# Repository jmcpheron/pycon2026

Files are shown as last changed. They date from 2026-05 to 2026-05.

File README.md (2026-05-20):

# pycon2026 — a 256:1 reduction-gear card

> A credit-card-sized object with a five-gear compound reduction chain — 256:1 from input to output. Designed in Onshape, deconstructed by Python.








<p align="center">
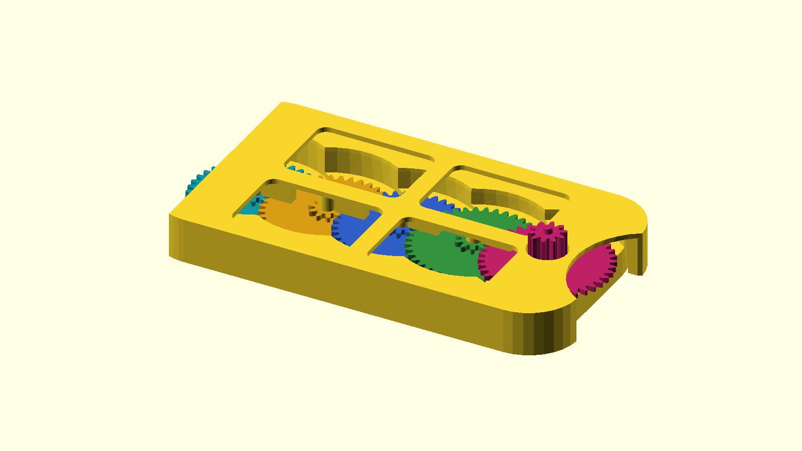
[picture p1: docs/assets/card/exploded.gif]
Animated exploded view of the reduction-gear card: top card half lifts up, five blue 40-tooth spur gears fan out in the middle, bottom card half lowers to reveal five shaft holes spaced 15 mm apart.
  
</p>

<p align="center">
  <sub>Onshape AP242 STEP → <a href="src/cardlab"><code>cardlab explode</code></a> → seven parts → animated GIF. The GIF rebuilds itself in CI whenever the STEP changes.</sub>
</p>

<p align="center">
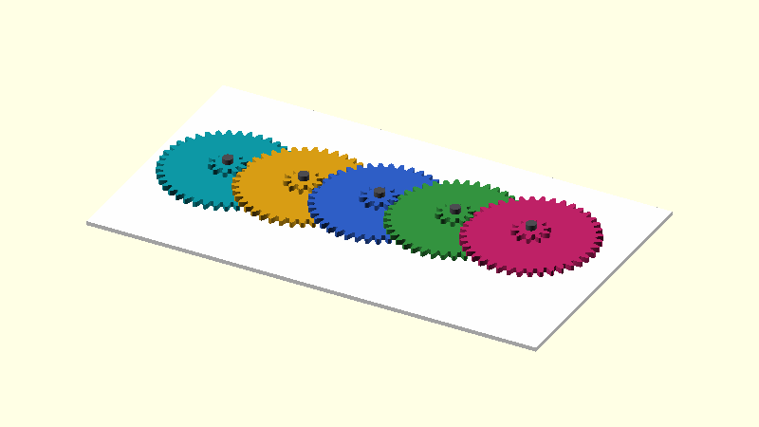
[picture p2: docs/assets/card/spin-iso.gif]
Animated isometric view of the same five-gear chain in motion. The input gear at one end is a brass blur — four full rotations per loop — and each subsequent gear turns at a quarter the rate of its neighbour, alternating direction. The output gear at the far end barely twitches: 256× slower than th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
  
</p>

<p align="center">
  <sub>Same five-gear chain, now <em>running</em>. Three-quarter iso view.</sub>
</p>

<p align="center">
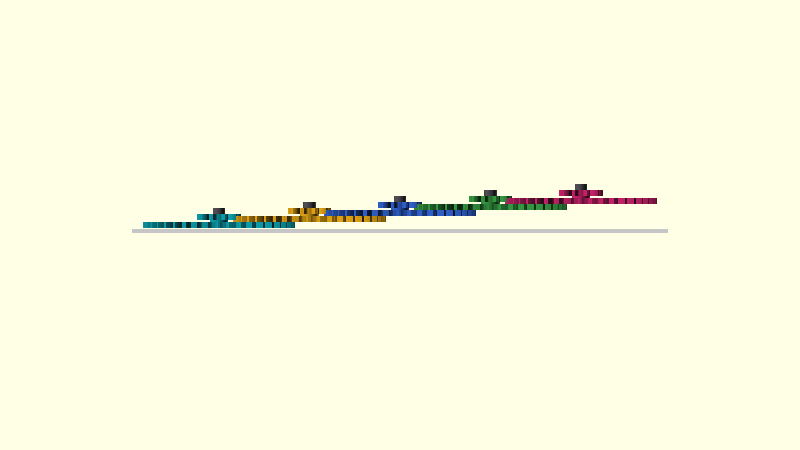
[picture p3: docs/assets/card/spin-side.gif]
Animated edge view of the same five-gear chain, looking along the card's long edge. Each compound gear sits one gear-thickness higher in Z than the previous, so the chain reads as a colored staircase climbing across the card body — and you can see each stage spinning at a quarter the rate of its ne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
  
</p>

<p align="center">
  <sub>Edge view reveals the staircase: each compound gear stacks one gear-thickness higher in Z so the print stays thin. Both GIFs are built parametrically from <a href="src/explainers/card.py"><code>card.py</code></a> with <a href="https://github.com/gumyr/build123d"><code>build123d</code></a> + <a href="https://github.com/gumyr/bd_warehouse"><code>bd_warehouse.gear.SpurGear</code></a>; rendered frame-by-frame by OpenSCAD and stitched by Pillow. Rebuilt by <a href="src/cardlab/spin.py"><code>cardlab spin</code></a>. (Both libraries Apache-2.0 — see <a href="ACKNOWLEDGMENTS.md">ACKNOWLEDGMENTS</a>.)</sub>
</p>

<p align="center">
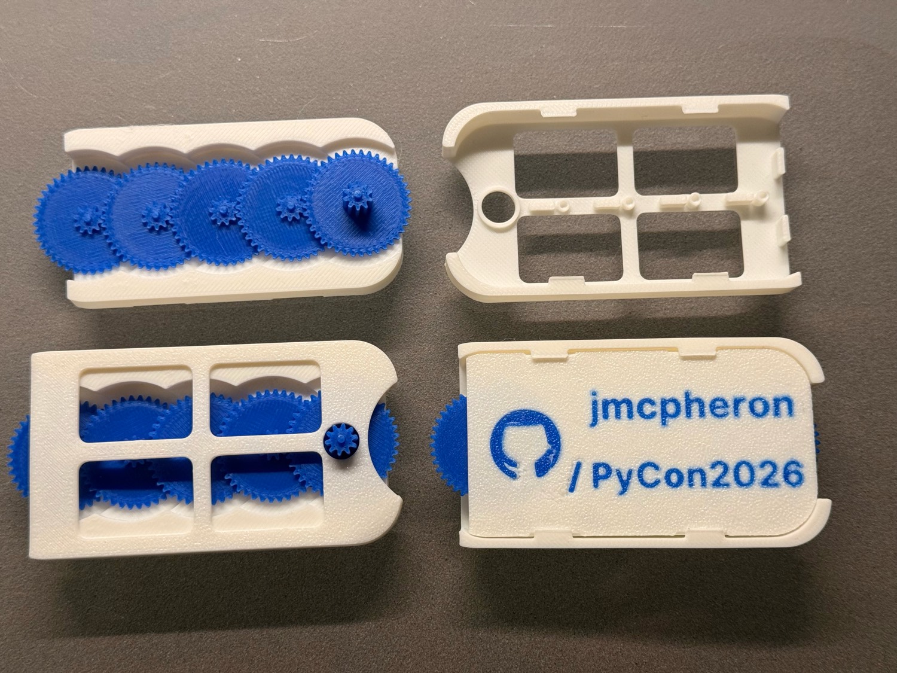
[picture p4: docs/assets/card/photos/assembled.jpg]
Photograph of an actual 3D-printed card, separated into four pieces on a grey desk. Top-left: the bottom card half with the five blue compound gears nested into their pockets, lid removed so the chain is visible. Top-right: the matching white top card half on its own, showing the four interior wind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
  
</p>

<p align="center">
  <sub>And here's the actual print. Two card halves, five blue compound gears, the input pinion poking out the right edge for your thumb — print-in-place from the same <a href="jmcpheron-card.step"><code>jmcpheron-card.step</code></a> the GIFs above are generated from.</sub>
</p>

<p align="center">
  Flat 2D plan view of the five-gear chain. The leftmost gear (INPUT, thumb-spun) rotates clockwise once every two seconds. Each subsequent gear runs at one-quarter the speed of the previous and spins the opposite direction — '4:1' callouts sit between each adjacent pair. By the rightmost gear (OUTPU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
</p>

<p align="center">
  <sub>Each mesh is a 4:1 reduction. Five gears, four meshes, 4<sup>4</sup> = <strong>256:1</strong>. See <a href="docs/explainers/gear-ratios.md">gear-ratios</a> for the math and thumb-travel intuition. Rebuilt by <a href="src/explainers/ratios.py"><code>explainers build ratios</code></a>.</sub>
</p>

<table>
<tr>
<td align="center" valign="top" width="33%">
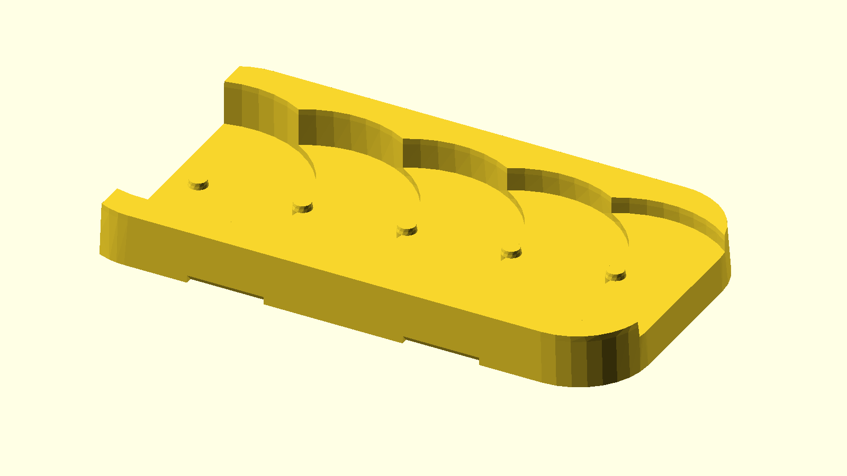
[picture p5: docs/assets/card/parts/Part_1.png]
Render of one of the two card halves — a 78 × 44 mm flat body with five rounded gear pockets, an axle hole, and a curved bottle-opener-style notch on the right.

<br/>
<sub><strong>Card half</strong><br/>78 × 44 mm body, five pockets, axle hole, bottle-opener notch.</sub>
</td>
<td align="center" valign="top" width="33%">
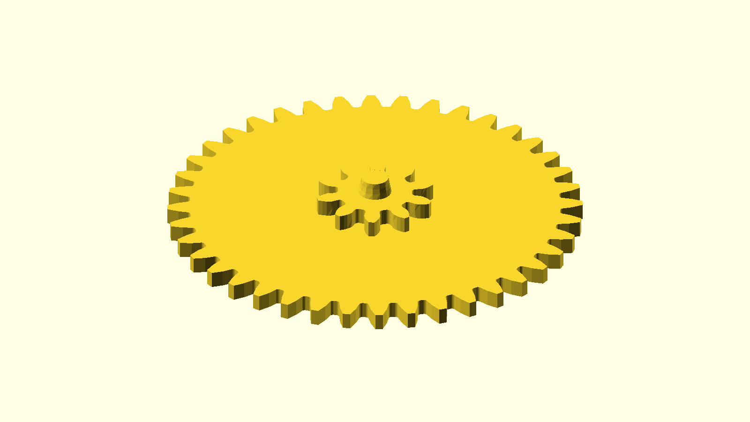
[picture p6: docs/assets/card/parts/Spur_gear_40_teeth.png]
Render of a 40-tooth spur gear with a short 10-tooth pinion hub fused on top — the standard compound gear.

<br/>
<sub><strong>Standard compound gear</strong><br/>40-tooth driven disc + 10-tooth pinion on a short hub.</sub>
</td>
<td align="center" valign="top" width="33%">
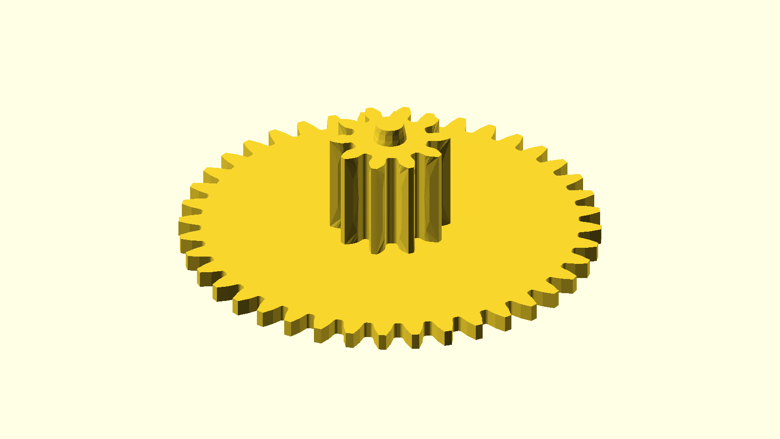
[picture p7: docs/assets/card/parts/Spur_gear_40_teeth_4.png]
Render of a 40-tooth spur gear with a tall 10-tooth pinion hub — the tall-hub variant used in alternating positions of the compound chain.

<br/>
<sub><strong>Tall-hub variant</strong><br/>Same 40 / 10 teeth, taller hub. Interleaved with short-hub gears so the discs don't collide.</sub>
</td>
</tr>
</table>

> *Curious about the pattern behind this repo? See [SHAREABLE-CAD.md](SHAREABLE-CAD.md) for the synthesis — Onshape as source of truth, GitHub as the workshop, MakerWorld + Printables as the storefronts, and the [Adam Savage vault](docs/vault/) as the current worked example.*

## Lightning talk · PyCon US 2026

<p align="center">
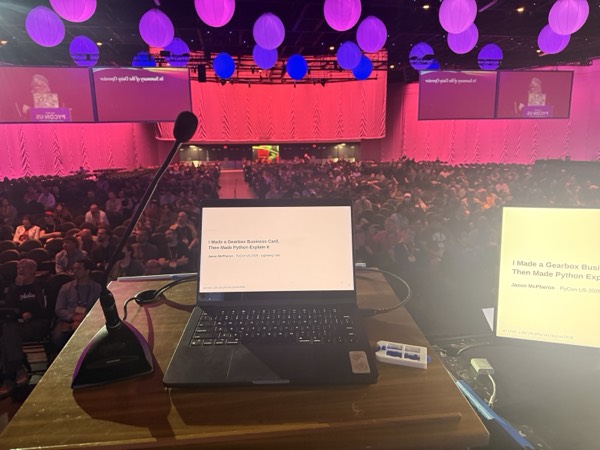
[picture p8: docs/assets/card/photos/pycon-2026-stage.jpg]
View from the lightning-talk podium at PyCon US 2026: a laptop on the podium shows the title slide 'I Made a Gearbox Business Card, Then Made Python Explain It · Jason McPheron · PyCon US 2026 · Lightning Talk'; a gooseneck microphone sits in front of it and a yellow confidence monitor to the right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
  
</p>

<p align="center">
  <sub>View from the lightning-talk stage at PyCon US 2026 in Long Beach, Saturday evening, May 16, 2026.</sub>
</p>

I gave a five-minute lightning talk at PyCon US 2026, *["I Made a Gearbox Business Card, Then Made Python Explain It"](https://us.pycon.org/2026/schedule/presentation/175/)* — the story behind this repo, condensed to slides and a 3D-printed prop audience members could hold. The same lightning-talk session included Simon Willison's *"The last six months in LLMs in five minutes,"* with the latest update to his [pelican-riding-a-bicycle](https://simonwillison.net/tags/pelican-riding-a-bicycle/) LLM benchmark — a real honour to share a stage with.

A recording should land on the [PyCon US YouTube channel](https://www.youtube.com/@PyConUS) in the weeks after the conference; I'll embed the clip here when it's posted.

## How it works

Five compound gears in a chain. Four 4:1 meshes between them, multiplied together: **256:1**. Spin the input gear with your thumb; the output gear moves a quarter-degree.

*(Five gears, four reductions — an idler chain of the same gears would still only reduce 4:1.)*

There are six short explainer pages if you want the longer version:

- [**The card in 3D**](docs/explainers/card-3d.md) — the STEP file and the little script that pulls it apart. Start here.
- [**Gear ratios**](docs/explainers/gear-ratios.md) — compound multiplication, with a thumb-travel intuition: ~20.3 m of finger motion per output rotation.
- [**Decoding the gears from STEP**](docs/explainers/decoding-gears.md) — slice the committed STL, FFT the radial profile, recover the tooth count and module from geometry alone.
- [**Stacking**](docs/explainers/stacking.md) — why a 3-level cycle of hub heights keeps the card thin without the discs colliding.
- [**Terminology**](docs/explainers/terminology.md) — pinion, module, pitch circle, addendum. The 90 seconds of vocabulary the other pages assume.
- [**Printing considerations**](docs/explainers/printing.md) — orientation, chamfers, why each post is its own part.

## A second design — Pounce-a-Pult, a spiral-spring cat toy

To show the same pipeline works on more than just the gear card, here's another of my designs run through it: the [Pounce-a-Pult spiral cat toy](docs/pounce-a-pult/README.md). The parametric source lives in a [public Onshape document](https://cad.onshape.com/documents/01739d2a63dc91eaf28c2c62/w/a7c671d651186a5272cc789f/e/fdb2542c5ccec8040d59912a) (fork it to remix the geometry) with a [printable MakerWorld bundle](https://makerworld.com/en/models/2138778-pounce-a-pult-spiral-cat-toy#profileId-2316710) (slicer profile + photos). The STEP export sits at [`step-demo/pounce-a-pult.step`](step-demo/pounce-a-pult.step); `cardlab inspect` reads its AP242 tree, `cardlab render` produces orthographic hero PNGs, and `cardlab explode` decomposes it into six per-part STL/GLB/PNG renders plus an animated exploded GIF — the same five-function chain the gear card uses, no toy-specific code. Per-page write-up at [**docs/pounce-a-pult/**](docs/pounce-a-pult/README.md).

## How it gets built

The card itself lives in Onshape. The STEP export is committed at the repo root. A little Click CLI called `cardlab` (in [`src/cardlab/`](src/cardlab/)) does five small things to it, leaning on [`build123d`](https://github.com/gumyr/build123d) and [`cascadio`](https://github.com/trimesh/cascadio):

| Command | Does |
|---|---|
| `cardlab inspect` | AP242 schema, assembly tree, bounding box, tessellation stats; merges sidecar `.meta.toml` if present |
| `cardlab build` | Tessellates STEP → STL or **colored GLB** (cascadio path preserves Onshape's per-part colors) |
| `cardlab render` | Orthographic PNG via the OpenSCAD pipeline (iso/top/edge/front/right presets) |
| `cardlab explode` | Pulls an assembly apart into per-part STL/GLB/PNG + an exploded GLB + an animated GIF + a manifest |
| `cardlab assemble` | Glues multiple STEP parts into one assembly from a TOML manifest |
| `cardlab spin` | Renders the chain *running* — parametric gears via `bd_warehouse`, frame-by-frame OpenSCAD, PIL-stitched into `spin-iso.gif` + `spin-side.gif`. Reads only from `src/explainers/card.py`; the STEP file is not used. |

```
jmcpheron-card.step       ──►  cardlab inspect  ──►  docs/assets/card/inspect.txt
                          ──►  cardlab build    ──►  jmcpheron-card.{stl,glb}
                          ──►  cardlab explode  ──►  parts/*.{stl,glb,png}
                                                     exploded.{glb,gif}
                                                     manifest.toml
src/explainers/card.py    ──►  cardlab spin     ──►  spin-iso.gif
                                                     spin-side.gif
```

Everything in [`docs/assets/card/`](docs/assets/card/) is regenerated by [`.github/workflows/build-card.yml`](.github/workflows/build-card.yml) on any push that touches the STEP or the `cardlab` script, then auto-committed back. Push a new Onshape export and the hero GIF above updates itself within a minute.

The six explainer pages above are also Python — small scripts under [`src/explainers/`](src/explainers/) that emit the markdown and SVG diagrams. All the numbers come from one [`card.py`](src/explainers/card.py); change a number there and every page reflects it on the next build.

```
src/explainers/<topic>.py  ──►  uv run explainers build  ──►  docs/explainers/<topic>.md
```

## Try it yourself

```bash
git clone https://github.com/jmcpheron/pycon2026
cd pycon2026
uv sync --extra step
uv run cardlab inspect jmcpheron-card.step
uv run cardlab explode --in jmcpheron-card.step --out /tmp/card/
# → /tmp/card/{exploded.gif, jmcpheron-card.glb, parts/*.{stl,glb,png}, manifest.toml}
```

The `step` extra is opt-in — the OpenCascade wheel is ~180 MB.

Requirements: Python 3.11+, [OpenSCAD](https://openscad.org/) on your `$PATH`, [`uv`](https://docs.astral.sh/uv/). Or just [open the Onshape doc](https://cad.onshape.com/documents/786fefdef357fb6860b54650/w/33fb9222a6752311e4f08c8b/e/da99fedbaeebf1422d4cb0d3) and spin it in your browser — no install required.

## Things I'd love to chat about at PyCon

If you scanned this from the card I handed you, here's what I'm hoping to talk about. Find me on the floor — or open an issue.

- **3D printing**, especially print-in-place mechanisms and the geometry tricks that make them survive a bed-slinger.
- **Python ↔ CAD pipelines.** Onshape STEP exports → `cascadio` → `trimesh` → OpenSCAD → animated GIF, all in CI. I'd like to hear what other people are gluing together.
- **Open-source licensing for physical 3D files.** I went with CC BY-SA 4.0 for the geometry — did I get that right? STEP and STL aren't software; copyright on mechanical designs is fuzzy; CERN OHL exists. Would love to hear from people who've thought harder about this.
- **Defensive disclosure vs. license clauses** as protection against patent trolls and copyright-shaped opportunism. Public Onshape + dated commits is probably doing most of the work; share-alike does the rest. Or does it?
- **Devlog-as-build-journal** as a way to ship hardware in public. I'd like to hear from others doing the same.

## License

**Code** (`src/`, `tests/`, workflows): **MIT** — see [`LICENSE`](LICENSE).

**3D files** ([`jmcpheron-card.step`](jmcpheron-card.step), the generated STL / GLB / PNG / GIF under `docs/assets/card/` and `docs/vault/assets/`, and the [public Onshape document](https://cad.onshape.com/documents/786fefdef357fb6860b54650/w/33fb9222a6752311e4f08c8b/e/da99fedbaeebf1422d4cb0d3)): **CC BY-SA 4.0** — see [`LICENSE-3D-FILES`](LICENSE-3D-FILES).

Print it, fork it, remix the gears. If you publish a derivative — a different layout, a coin-sized version, whatever — it needs to be CC BY-SA 4.0 too, and please credit `pycon2026` by jmcpheron with a link back here.

## Acknowledgments

This project is a thin glue layer on top of a lot of other open-source
work — `build123d`, `bd_warehouse`, `cadquery-ocp` (OCCT), `cascadio`,
`trimesh`, `Pillow`, `drawsvg`, `matplotlib`, `click`, plus OpenSCAD
and `uv` outside Python. See [`ACKNOWLEDGMENTS.md`](ACKNOWLEDGMENTS.md)
for the full list with licenses and links.

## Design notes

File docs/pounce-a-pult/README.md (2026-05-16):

# Pounce-a-Pult — a spiral-spring cat toy, run through the Python pipeline

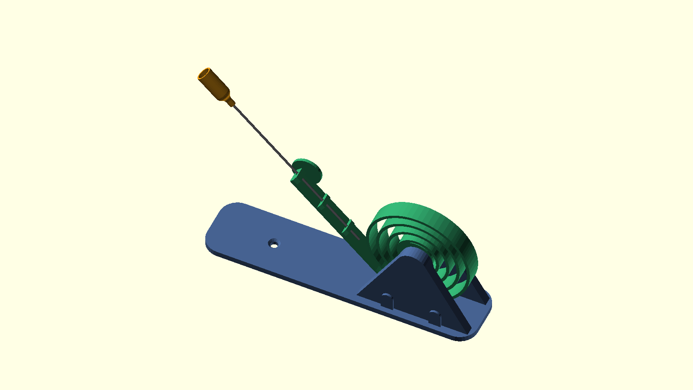
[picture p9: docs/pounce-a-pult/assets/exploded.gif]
Six parts of the pounce-a-pult fanning radially outward from the assembled pose and back, looping; the orange spiral spring and rod-holder cup, the long black base plate, two triangular brackets, and a small reflective bracket plate


> A flat spiral spring that flexes and rebounds when your cat swats it.
> One tap sends the spiral wobbling and twisting before it settles back,
> ready for the next round.

## What it is

The arm is a *flat spiral spring* — laid flat in the print bed, so it
comes off the printer ready to flex out-of-plane. Its free end carries
a small cup sized for a thin straight rod (a straightened coat hanger
works perfectly). Tape a feather to the rod and the assembly becomes a
self-resetting swatting target that moves in a way cats seem to find
endlessly interesting. The base is a long flat plate and two triangular
support brackets that hold the spring vertical.

## Where to get one

The pounce-a-pult is meant to be shared, printed, and remixed. Two
canonical homes for the design live alongside this repo:

- **Print one.** The published bundle on MakerWorld has the slicer
  profile, photos in the wild, and remix notes — the easiest path to a
  working toy:
  [makerworld.com/en/models/2138778-pounce-a-pult-spiral-cat-toy](https://makerworld.com/en/models/2138778-pounce-a-pult-spiral-cat-toy#profileId-2316710).
- **Remix the CAD.** The design lives in a public Onshape document —
  open it in any browser to spin it around, then click "Make a copy"
  into a free Onshape account to change the geometry directly (a
  longer base, taller brackets, a different polygon on the spring
  socket):
  [cad.onshape.com/documents/01739d2a63dc91eaf28c2c62](https://cad.onshape.com/documents/01739d2a63dc91eaf28c2c62/w/a7c671d651186a5272cc789f/e/fdb2542c5ccec8040d59912a).

The files under [`step-demo/`](../../step-demo/) are just the
exported STEP plus everything [`cardlab`](../../src/cardlab/)
derives from it.

## Hero renders

| Iso | Top | Edge |
|---|---|---|
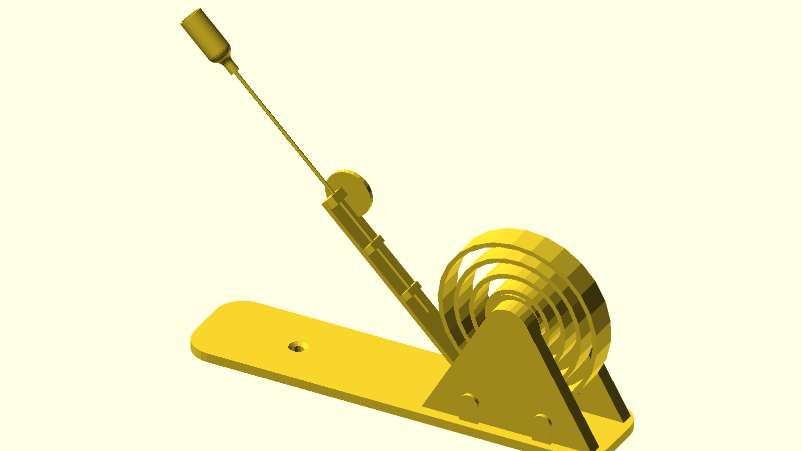
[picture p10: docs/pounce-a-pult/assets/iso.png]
Isometric render: long flat base, twin triangular brackets holding the orange spiral spring upright, small orange cup at the spring's free end
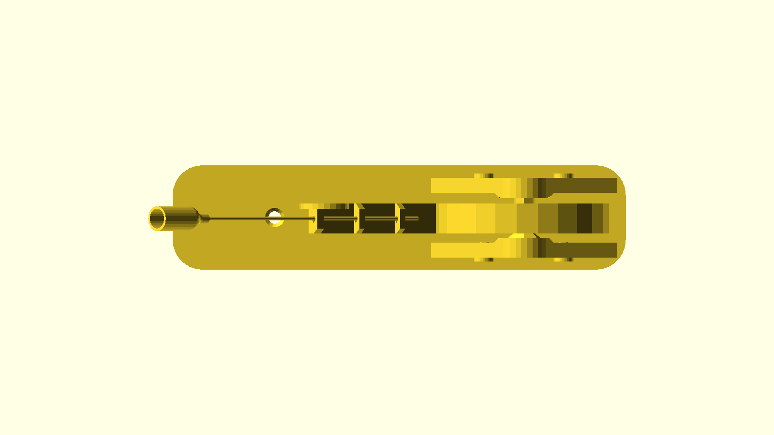
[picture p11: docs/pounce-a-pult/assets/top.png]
Top-down render showing the spring's flat spiral as a near-circular foot-print
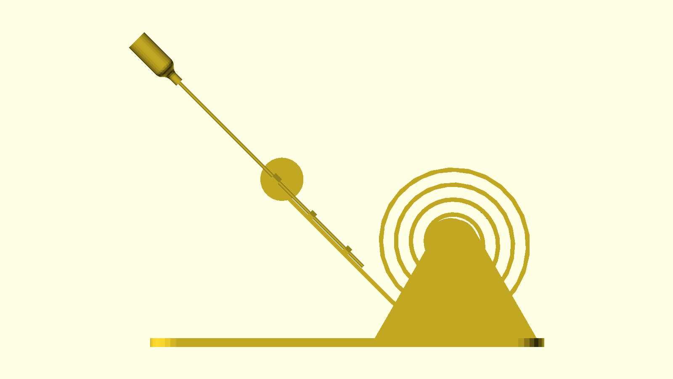
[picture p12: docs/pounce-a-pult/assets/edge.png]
Edge view: the base is a thin strip; the brackets project upward and the spring rises from between them
|  |  |  |

Rendered by `cardlab render` (OpenSCAD-backed orthographic projection)
at the iso / top / edge presets from
[`src/cardlab/render.py`](../../src/cardlab/render.py).

## V2 upgrades

- **Chamfered mounting holes** through the base plate so you can bolt
  this thing to a wall, desk, cat tree, or any nearby surface brave
  enough to host it.
- **Heptagon socket on the spring mount** — 7 sides instead of 2, so
  there are *seven* discrete angle options for clocking the spring
  into the base instead of just two. When the spring starts to sag
  after months of high-impact cat shenanigans, just rotate it to a
  fresh face: more tuning options, better wear spread, and an easy
  way to dial in the perfect amount of bounce.

## Assembly

- Designed for a **~1.6 mm rod**. A straightened coat hanger works
  great. Straightened PLA filament or any similar stiff plastic rod
  will also do the job.
- Add a feather, puffball, or string to the end of the rod with glue,
  a knot, or a snug friction fit. Cat preference, not engineering.
- The brackets slot onto the base plate; the spring's heptagon socket
  registers it to one of seven angles between them. No fasteners
  required for the basic build; M-screws into the chamfered base
  holes if you're wall-mounting.

## Printing

- **PLA or PETG** recommended.
- **No supports** required.
- **Prints flat on the build plate.** The spiral arm is what makes
  this design work — print it lying down so the layers run radially
  along the spring's length, not across it. Cross-grain layers crack
  on the first hard swat.

## Part-by-part breakdown

`cardlab explode` decomposes the STEP into 6 solids, renders each one
in isolation, and writes the colour + centroid + displacement vector
to [`assets/manifest.toml`](assets/manifest.toml).

| Render | Part | Bbox (mm, X × Y × Z) | Notes |
|---|---|---|---|
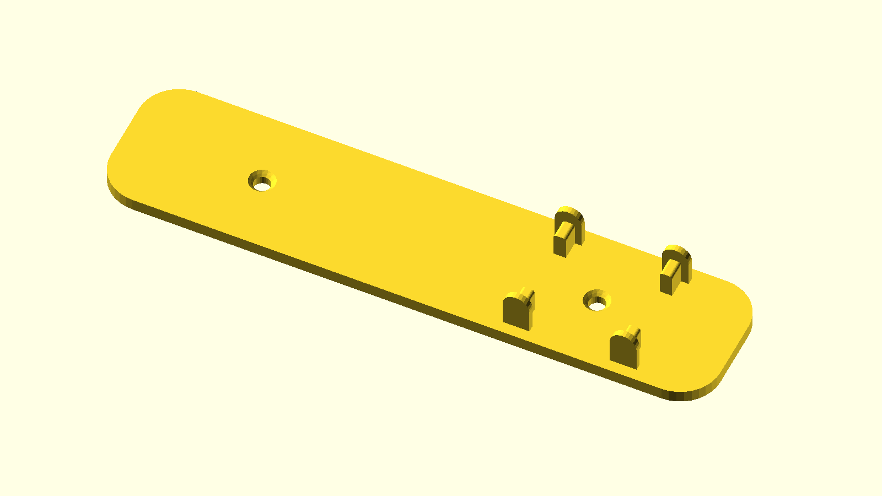
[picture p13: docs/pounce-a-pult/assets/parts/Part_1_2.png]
Long flat base plate
|  | `Part_1_2` | 182 × 42 × 16 | Long flat base plate — the longest part on the long axis. |
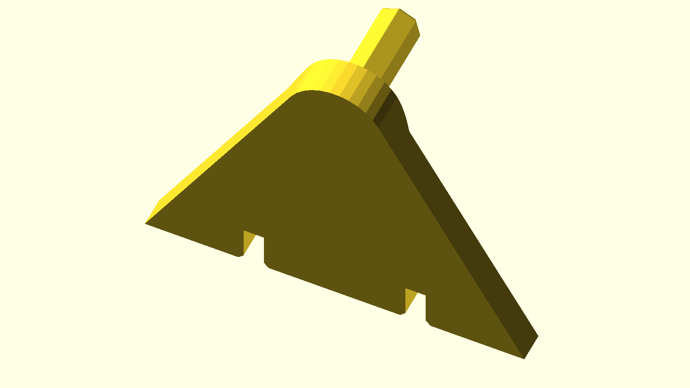
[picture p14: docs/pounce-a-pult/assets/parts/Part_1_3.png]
Triangular support bracket
|  | `Part_1_3` | 75 × 28 × 55 | One of the triangular support brackets. |
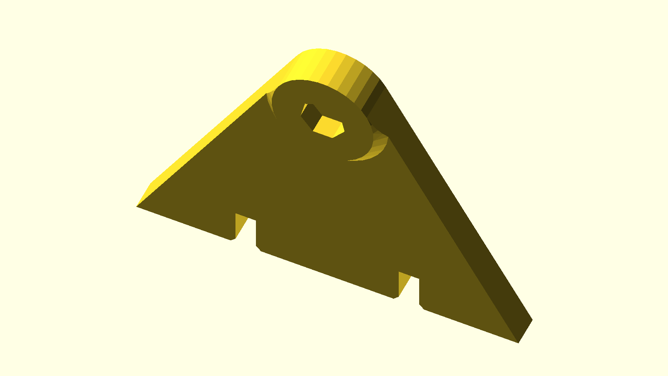
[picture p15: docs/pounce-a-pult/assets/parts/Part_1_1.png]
Triangular support bracket — mirror twin
|  | `Part_1_1` | 75 × 8 × 55 | The mirror-twin support bracket. |
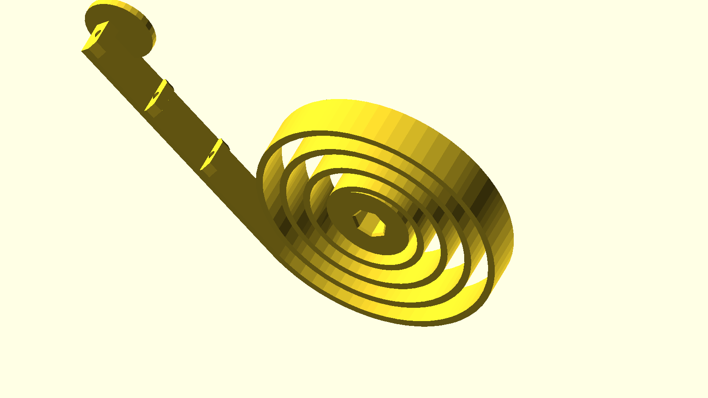
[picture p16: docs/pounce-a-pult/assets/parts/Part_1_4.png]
Flat spiral spring arm
|  | `Part_1_4` | 125 × 12 × 78 | The flat spiral arm — the part that flexes. |
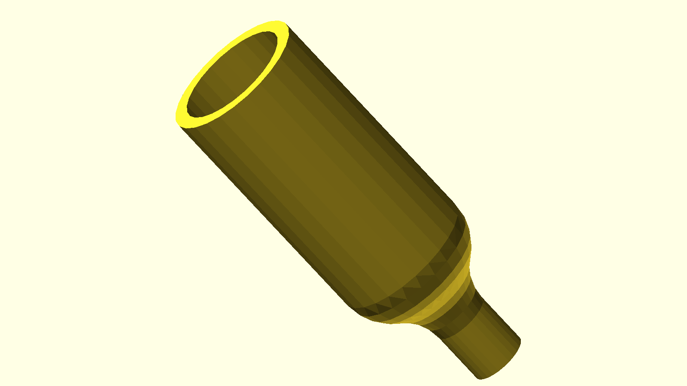
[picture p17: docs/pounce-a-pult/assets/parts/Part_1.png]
Small rod-holder cup
|  | `Part_1` | 25 × 10 × 25 | The rod-holder cup at the free end of the spring. |
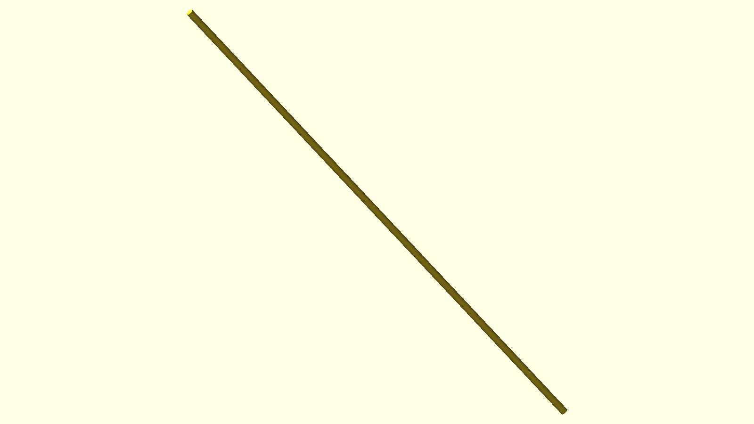
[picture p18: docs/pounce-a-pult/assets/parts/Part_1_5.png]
Square mounting reference
|  | `Part_1_5` | 86 × 1.5 × 86 | The thin square reference plate visible in the Onshape doc. |

Dimensions come straight from the STEP's bounding boxes in
[`assets/manifest.toml`](assets/manifest.toml); the captions are my
read of what each slot is for. The full per-part STL + GLB live next
to the PNGs in [`assets/parts/`](assets/parts/) so you can pull any
single part into Bambu Studio or Onshape.

## Inspect output

The full AP242 tree, bounding box, and tessellation stats are in
[`inspect.txt`](inspect.txt) — produced by `cardlab inspect
step-demo/pounce-a-pult.step`. Useful if you want to confirm units,
schema, or originating CAD system before re-mixing.

## How this page is built

```
step-demo/pounce-a-pult.step  ──►  cardlab inspect  ──►  inspect.txt
                              ──►  cardlab render   ──►  assets/{iso,top,edge}.png
                              ──►  cardlab explode  ──►  assets/exploded.{glb,gif}
                                                         assets/manifest.toml
                                                         assets/parts/*.{stl,glb,png}
```

The exact same `build123d` + `cascadio` + `trimesh` + OpenSCAD + Pillow
pipeline that powers the [gear card's exploded GIF](../assets/card/exploded.gif)
and the [vault mechanism animation](../vault/assets/vault-hero.gif). No
asset-specific code — the only thing that changes between projects is
the input STEP file and the displacement strategy. See
[`ACKNOWLEDGMENTS.md`](../../ACKNOWLEDGMENTS.md) for the full
upstream-library credit list.

CI re-runs the full pipeline on every push that touches
`step-demo/**.step` or `src/cardlab/**`, via
[`.github/workflows/build-step.yml`](../../.github/workflows/build-step.yml),
and auto-commits the regenerated artefacts back to `main`.

## Source · license

The pounce-a-pult is another of my designs, published under
[Creative Commons Attribution 4.0 (CC BY)](https://creativecommons.org/licenses/by/4.0/)
— a more permissive choice than the rest of this repo's 3D files, so
anyone can remix and redistribute the toy without share-alike strings
attached.

Two canonical locations:

- The **parametric CAD source** is a [public Onshape document](https://cad.onshape.com/documents/01739d2a63dc91eaf28c2c62/w/a7c671d651186a5272cc789f/e/fdb2542c5ccec8040d59912a) — this is where the geometry actually *lives* (sketches, features, parameters). Fork it there if you want to change the shape of anything.
- The **printable bundle** is on [MakerWorld](https://makerworld.com/en/models/2138778-pounce-a-pult-spiral-cat-toy#profileId-2316710) — slicer profile, photos, assembly tips, and a place to leave a like.

The `step-demo/pounce-a-pult.step` file is the STEP export from that
Onshape document; every render in this folder
(`docs/pounce-a-pult/assets/*.{png,gif,glb}` and `parts/*`) is a
derivative work of it and inherits **CC BY 4.0** — distinct from the
rest of this repo's [`LICENSE-3D-FILES`](../../LICENSE-3D-FILES) (CC
BY-SA 4.0).

If you remix the toy, please carry the attribution forward.

---

*Generated by `cardlab` from `step-demo/pounce-a-pult.step` — same
Python pipeline as the gear card, run against a different design.*

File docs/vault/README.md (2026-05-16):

# Vault Door Mechanism Study

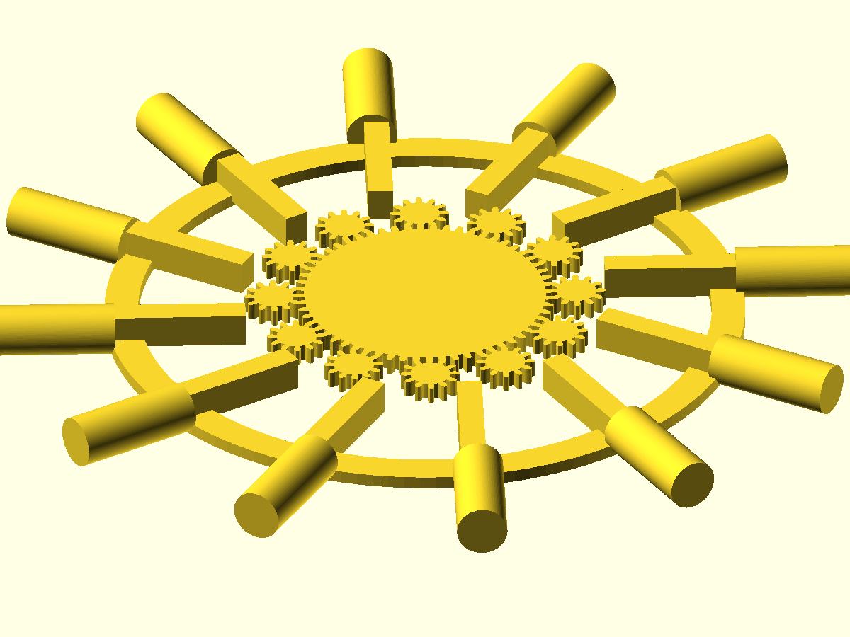
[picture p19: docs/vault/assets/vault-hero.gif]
12-pin vault door mechanism — ring gear, 12 spurs, 12 rack-and-pin assemblies


> *A small Python toy for the geometry of rotary vault-door pin mechanisms.
> Symmetry, gearing, packaging, and what 12 pins share that
> 13 pins can't.*

## I made this because I got curious

Watching Adam Savage's mini vault-door build, I kept staring at one
detail I didn't understand at first: each pin had a section of straight
gear teeth cut into it, and the back of that section — the spine,
opposite the teeth — was machined surprisingly thin. More material
removed than weight savings would justify. When the parts went together
inside the door it clicked. **The pin count was forcing the geometry.**

A single central pinion has to drive all N racks at once, the racks
share the perimeter of that one pinion, and each rack's spine gets
machined down to whatever slice it gets. Bigger N → thinner slice.
Adam wasn't choosing the shape; the pin count was choosing it for him.

That observation kept me up an evening. This repo is what came out — a
Python parametric study of how pin count, symmetry, gearing, and
packaging interact on a circular vault door. Every diagram below is
generated from one parameter file
([`vault.py`](../../src/vault/vault.py)); change a number, every page
re-derives.

## Play with it

**[→ Open the live pin-count explorer](https://jmcpheron.github.io/pycon2026/vault/pin-explorer.html)**

Drag the slider from 3 to 30 pins. The layout snaps. The readout panel
shows the angle step (`360/N`), the divisors of N, whether the count
has exact opposing pairs, and how thin the rack body has to be at that
pin count given the canonical 12 mm pinion.

> 12 reads clean.  13 works but doesn't share.  24 pinches the racks to slivers.

*(Clicking that link from GitHub.com opens the page source. Open it
through GitHub Pages for the live version — the URL above lands you
there directly.)*

## Five short sections

1. [**Symmetry**](symmetry.md) — why 12 and 24 read as obvious and 13 doesn't.
2. [**The 13-pin problem**](thirteen-pin-problem.md) — it works mechanically; what it gives up are the *shortcuts* (shared racks, mirrored fixtures, sub-symmetric actuation). Honest framing of where prime hurts.
3. [**Pin counts**](pin-counts.md) — small-multiples comparison plus the rack-thinning note from watching Adam's video, with the inequality `t ≤ 2π·r_pinion/N − clearance` and a per-N budget table.
4. [**Motion and travel**](motion-and-travel.md) — what a 10° cam rotation actually gets you. `arc = r·θ`, the cam-radius table, and the careful distinction between *arc travel* and *radial pin travel*.
5. [**Onshape workflow**](onshape-workflow.md) — how the Python parameters in [`vault.py`](../../src/vault/vault.py) map to a parametric CAD model.

## For the Tested community

If you got here via the Tested Maker Share: hi. Adam's mini vault-door
build sparked this study; it is a love-letter to the geometry, not a
clone of his mechanism. Fork it, remix it, riff on it — change the pin
count in [`vault.py`](../../src/vault/vault.py), run `uv run vault build`,
and every page above re-derives with your numbers. The interactive
explorer takes the same input live in your browser. Send me what you
find.

## Default door parameters

* Door diameter: **160 mm**, thickness **8 mm**
* Pin count: **12** on a pitch circle of radius **70 mm**
* Pin travel: **8 mm** radial
* Central cam rotation: **10°** (sweeps **12.22 mm** of arc at the pin radius)
* Central pinion radius: **12 mm** (bounds rack-body thickness to **5.98 mm** at N = 12)

Change any of these in [`vault.py`](../../src/vault/vault.py) and the
explainer pages, hero animation, and budget tables all re-derive on the
next `uv run vault build`.

## Print one · remix it

The five canonical mechanism parts ship as standalone STLs alongside
the hero GIF, ready to drop into Bambu Studio, Onshape, or any other
3D tool:

* [`assets/parts/ring-gear.stl`](assets/parts/ring-gear.stl) — central 60-tooth ring gear (module 1). Print **1×**.
* [`assets/parts/spur-gear.stl`](assets/parts/spur-gear.stl) — one 12-tooth satellite spur gear. Print **12×**.
* [`assets/parts/rack.stl`](assets/parts/rack.stl) — one rack, already pre-milled on its spine to the per-pin tangential budget (5.98 mm). Print **12×**.
* [`assets/parts/pin.stl`](assets/parts/pin.stl) — one 12 mm × 30 mm locking pin. Print **12×**.
* [`assets/parts/door-rim.stl`](assets/parts/door-rim.stl) — the 152.4 mm annulus the pins ride through. Print **1×**.

To regenerate them locally (no OpenSCAD required for parts-only
export — build123d is enough):

```
uv run vault export-parts --out-dir /tmp/vault-parts
```

## How it gets built

```
src/vault/<topic>.py     ─►  uv run vault build <topic>      ─►  docs/vault/<topic>.md (+ assets/*.svg)
src/vault/mechanism.py   ─►  uv run vault build-mechanism    ─►  docs/vault/assets/vault-hero.gif
                                                                 + docs/vault/assets/parts/*.stl
src/vault/mechanism.py   ─►  uv run vault export-parts       ─►  docs/vault/assets/parts/*.stl  (parts only, no GIF)
```

The lightweight pages are regenerated by
[`.github/workflows/build-vault.yml`](../../.github/workflows/build-vault.yml)
on every push that touches `src/vault/` and auto-committed back to
`main`. The detailed mechanism GIF — which needs build123d,
`bd_warehouse`, OpenSCAD, and xvfb — runs on its own slower workflow
[`.github/workflows/build-vault-mechanism.yml`](../../.github/workflows/build-vault-mechanism.yml).
Both auto-commit alongside the parallel workflows for the gear card and
the engineering explainers.

The interactive [`pin-explorer.html`](pin-explorer.html) is *not*
regenerated — it's hand-written, self-contained, deployed by
[`.github/workflows/pages.yml`](../../.github/workflows/pages.yml).

## Disclaimer · licenses

This is a fan-made educational mechanism study inspired by public maker
videos and general vault-door mechanisms. It is **not** an official
Tested project, does not reproduce any private plans, and is not
affiliated with Adam Savage's Tested.com.

Code: MIT.
Diagrams + 3D files under this directory: CC BY-SA 4.0.
See [`LICENSE`](../../LICENSE) and [`LICENSE-3D-FILES`](../../LICENSE-3D-FILES).

## Credits — the libraries that draw the pictures

The static SVG diagrams (symmetry, pin-counts, motion, the 13-pin
comparison) are drawn with
[`drawsvg`](https://github.com/cduck/drawsvg) (MIT).
The mechanism GIF above is built from
[`build123d`](https://github.com/gumyr/build123d) and
[`bd_warehouse`](https://github.com/gumyr/bd_warehouse) parts (both
Apache-2.0) — `bd_warehouse.gear.SpurGear` is what gives us the
involute-tooth ring and spur gears — rendered frame-by-frame through
[OpenSCAD](https://openscad.org/) (GPL-2.0-or-later) and stitched into
a GIF with [Pillow](https://github.com/python-pillow/Pillow) (MIT-CMU).
The full list of third-party tools the repo leans on lives in
[`ACKNOWLEDGMENTS.md`](../../ACKNOWLEDGMENTS.md).

---

*Generated by `src/vault/index.py`. Source-of-truth parameters live in
[`src/vault/vault.py`](../../src/vault/vault.py).*

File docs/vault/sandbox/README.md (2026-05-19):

# Vault door — local OpenSCAD sandbox

This directory is the **local iteration playground** for the vault door's
structural body. It is intentionally a "side quest" from the main repo
toolchain:

* No build123d, no `bd_warehouse`, no Python in the loop — just one
  hand-written `.scad` file with an OpenSCAD Customizer block.
* Not watched by `build-vault.yml` or `build-vault-mechanism.yml`. The
  only CI that touches it is `pages.yml`, which publishes the file to
  GitHub Pages as a static asset.
* No auto-commits race your edits.

The canonical Python parameters in [`src/vault/vault.py`](../../../src/vault/vault.py)
remain the source of truth for the CI-rendered GIF and the engineering
explainer pages. `door.scad` is a *parallel* representation — same
numbers, different language — meant for fast geometric play.

## How to use

Open the file in the OpenSCAD GUI:

```
openscad docs/vault/sandbox/door.scad
```

Then **View → Customizer**. Drag the sliders. Hit **F5** for fast
preview, **F6** for the full CSG render.

To export a still PNG for sharing:

```
openscad -o /tmp/door.png \
    --imgsize 1600,900 \
    --camera 0,0,15,58,0,28,500 \
    --projection ortho \
    --colorscheme Cornfield \
    docs/vault/sandbox/door.scad
```

To override a parameter from the command line (one-off, without editing
the file):

```
openscad -o /tmp/door_thin.png -D 'door_thickness_mm=24' docs/vault/sandbox/door.scad
```

## What is and isn't in the model

In: door body, tapered edge, internal cavity, 12 radial pin bores, the
spur-axle bolt circle on the 72 mm BCD, the ring-gear boss recess, an
optional 120° cutaway wedge.

Not in: the ring gear, the 12 spur gears, the racks, the locking pins
themselves, the combination lock cage, the hinge, the frame plate. The
gears already exist as STLs in
[`docs/vault/assets/parts/`](../assets/parts/) — those are produced from
`src/vault/mechanism.py` via build123d + bd_warehouse, because involute
gear teeth are painful in raw OpenSCAD primitives. If you want them
visible alongside the door, `import("../assets/parts/ring-gear.stl")`
from a sibling `.scad` file is the cleanest path.

## When to graduate a number out of the sandbox

If a dimension you've been dialling in here turns out to be the "right"
one, update [`docs/vault/specs.md`](../specs.md) (with a source tag) and
then `src/vault/vault.py`. The sandbox is for play; the Python module is
where decisions land.

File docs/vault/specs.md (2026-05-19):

# Vault build — specifications

Single source of truth for every dimension, count, and material call-out.
Each entry tagged with the source it came from (e.g. `[video-01]`), so when
Adam revises a number in a later video the trail stays clear.

Sources legend:
- `[video-01]` — Adam machining the ring gear from a stainless cylinder
  (https://www.youtube.com/watch?v=SiL8IzJSnyU)
- `[Part 2]` — pins, racks, acrylic hub body — `part-2.md`
- `[Part 3]` — vault-door puck, frame plate, hinge — `part-3.md`
- `[Part 4]` — rack concentricity rework, revised pin diameter — `part-4.md`
- `[Part 5]` — miniature combination lock cage — `part-5.md`

---

## Global gear math

| Parameter | Value | Source |
| --- | --- | --- |
| Gear module | 0.5 mm | [video-01] |
| Scale (relative to a real vault door) | 1/12 | [video-01] |

The module is the parameter that has to match across every gear that meshes,
so it is the single most important number in the file.

## Real-world reference (for context, not for modeling)

Real vault doors: 24 spur gears (24 teeth each) around a 288-tooth ring gear.
Adam's miniature halves this — see below. `[video-01]`

## Ring gear

| Parameter | Value | Source |
| --- | --- | --- |
| Teeth | 120 | [video-01] |
| Outer diameter | 2.401 in (≈ 2.4 in) | [video-01] |
| Depth of gear cut (OD to root of tooth) | 0.044 in | [video-01] |
| Material (Adam's build, FYI only) | 416 stainless | [video-01] |

## Spur gears

| Parameter | Value | Source |
| --- | --- | --- |
| Count | 12 | [video-01] |
| Teeth (each) | 24 | [video-01] |
| Bolt-circle hole spacing | 30° (12 holes evenly around) | [video-01] |

Adam's mill dividing plate has 24 holes (15° spacing), but he only fills every
other one for the 12-pin door.

## Locking pins

| Parameter | Value | Source |
| --- | --- | --- |
| Count | 12 (one per spur gear) | [video-01] |
| Diameter | 12 mm | [video-01] |
| Drive mechanism | Straight rack on bottom face, driven by spur gear | [video-01] |

## Door body (the acrylic / cast-iron puck)

| Parameter | Value | Source |
| --- | --- | --- |
| Outer diameter (at the front face) | 6 in (152.4 mm) | [Part 2] |
| Stock thickness (Adam's as-built) | 1.25 in (31.75 mm) | [Part 2] |
| Sandbox thickness (see "Three-stage edge profile" below) | 48 mm | derived |
| Material (Part 2) | Cast acrylic (for the visualisation hub) | [Part 2] |
| Material (Part 3) | Cast iron (the real heavy puck) | [Part 3] |
| Front-face solid thickness (before cavity) | 0.5 in (12.7 mm) | [Part 3] |
| Internal cavity depth (Adam's stock) | 0.75 in (19.05 mm) | [Part 3] |
| Door-thinning required for swing clearance | 0.75 in (19.05 mm) of push-back | [Part 3] |
| Ring-gear boss inner diameter ("slip cut") | 2.003 in (50.876 mm) | [Part 2] |

### Three-stage edge profile

The Part 3 video shows the door edge is NOT a single conical taper —
it's three roughly-even axial stages stacked back-to-front, each
~1/3 of the total thickness:

| Stage | z range | Wall character | Role |
| --- | --- | --- | --- |
| **Back** | [0, t/3] | Near-cylindrical (≈ 0°) | Houses the 12 radial pin bores. The wall has to be straight so the bores are perpendicular to a parallel surface. |
| **Middle** | [t/3, 2t/3] | Gradual taper (≈ 6°) | Intermediate transition. |
| **Front** | [2t/3, t] | Bigger taper (≈ 12°) | Lands on the display face. This is the angle that does most of the "thunk into the frame seat" work. |

Where `t` is the total door thickness.

**Why the sandbox uses 48 mm instead of Adam's 31.75 mm**: at the
canonical 12 mm pin diameter, the back stage needs to contain the pin
bore cleanly — diameter 12 + 0.2 mm clearance + ~2 mm of wall above and
below = ~16 mm of z-height per stage. Three even stages of 16 mm = 48
mm total. Adam's 31.75 mm stock gives each stage only ~10.6 mm, which
forces the pin to straddle the boundary between the back stage and the
middle stage rather than living entirely inside the back stage. The
sandbox model favours a clean back-stage placement; the as-built
column is preserved as a separate row above.

## Pin layout & spur-axle bolt circle

| Parameter | Value | Source |
| --- | --- | --- |
| Spur-axle bolt-circle diameter (BCD) | 72 mm | [Part 2] |
| Spur-axle hole count | 12 (every other hole of the 24-hole dividing-plate pattern) | [video-01] |
| Angular spacing | 30° | 360 / 12 |
| Pin bores | 12 radial, through the rim, into the cavity | [Part 2] |
| Shoulder-bolt smooth-shoulder slip-fit clearance to spur-gear bore | 0.1 mm | [Part 2] |

## Pin & rack mechanism (revisions and details)

| Parameter | Value | Source |
| --- | --- | --- |
| Pin diameter (Part 2 drawing) | 12 mm ("M12 × 30") | [Part 2] |
| Pin diameter (Part 4 revision, measured from physical part) | 10 mm | [Part 4] |
| Pin length | 30 mm | [Part 2] |
| Pin base thread | M6 (rack screws into the pin base) | [Part 2] |
| Rack stock | 8 × 8 mm square | [Part 2] |
| Rack module | Mod 0.5 (matches ring + spur) | [Part 2] |
| Rack threaded stud | 6 mm Ø, M6 (turned from the 8 mm square) | [Part 2] |
| Rack back-face relief | Curved (ball-end-mill) to clear ring gear | [Part 2] |
| Rack quantity made | 14 (12 needed; "always make more than you need") | [Part 4] |
| Rack tooth-zero-point alignment tolerance | within 0.1 mm of all 12 racks | [Part 2] |
| Concentricity error from hand-cut thread (the trap to avoid in CAD) | 0.0125 in (≈ 0.32 mm) | [Part 4] |

## Frame plate & door swing (Part 3, FYI for the full build)

| Parameter | Value | Source |
| --- | --- | --- |
| Frame plate material | 1/2 in 6061 aluminium | [Part 3] |
| Frame plate footprint | ≈ 10–12 in square | [Part 3] |
| Frame opening | 6 in bore | [Part 3] |
| Door-to-frame radial clearance | 0.020 in (0.508 mm) | [Part 3] |
| Hinge thrust bearings | 3/8 in OD on a 1/8 in centre pin | [Part 3] |
| Hinge fasteners | 28 × M2 screws (M6 is Adam's plan B) | [Part 3] |

## Combination lock cage (Part 5, future scope)

| Parameter | Value | Source |
| --- | --- | --- |
| Cage envelope | 0.75 in long × 0.5 in wide | [Part 5] |
| Cage wall material | 0.025 in (≈ 0.64 mm) brass sheet | [Part 5] |
| Combination wheels | 3 wheels | [Part 5] |
| Wheel diameter | 0.450 in | [Part 5] |
| Spindle | 1/8 in brass rod through the door | [Part 5] |
| Dial tick divisions | 36 (one per 10°) | [Part 5] |

## Derived values

| Parameter | Value | Notes |
| --- | --- | --- |
| Drive ratio (ring : spur) | 5 : 1 | 120 / 24. Onshape's Gear Relation tool will compute this automatically from tooth counts. |
| Spur centres relative to ring centre | 36 mm | BCD / 2 |
| Pins per 30° wedge | 1 | 12 pins, 360 / 12 |

## Discrepancies (numbers that disagree between sources)

These are the open decisions. When you pick a winner, update both
`src/vault/vault.py` and the row above to match.

| Param | `src/vault/vault.py` | Video transcript | Decision |
| --- | --- | --- | --- |
| Locking pin diameter | `MECH_LOCKING_PIN_DIA_MM = 12.0` | 12 mm `[Part 2 drawing]` → revised 10 mm `[Part 4 physical part]` | (TBD) |

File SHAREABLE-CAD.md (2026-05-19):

# Shareable CAD — the pattern this repo is built on

> *A pipeline for hand-printable, parametric, code-trackable, community-shareable 3D objects. Onshape is where the geometry lives. GitHub is the workshop. MakerWorld and Printables are the storefronts. Python sits in the middle and pulls everything apart so anyone can put it back together.*

This repo started as one small physical artifact — a credit-card-sized
five-gear reduction chain handed out at PyCon 2026 — and a Python
toolkit to deconstruct its STEP file into renders, exploded GIFs, and
generated explainer pages. Then we ran the same toolkit on a
[spiral-spring cat toy](docs/pounce-a-pult/README.md). Then we started
[an Adam Savage mini-vault-door study](docs/vault/). Three different
objects, same scaffolding, same kind of writeup.

At three projects the *pattern* is more interesting than any one of
them. This document is the pattern.

## TL;DR

```
   Onshape doc          ← source of truth (parametric CAD in the cloud)
       │ STEP export, committed to repo root
       ▼
   GitHub repo          ← Python tooling, parameters, history, issues
       │ auto-built artifacts (STL / GLB / GIF / SVG / explainer pages)
       ▼
   MakerWorld + Printables   ← consumer-facing sharing endpoints
                              (3MF bundle + slicer profile + photos)
```

You design in Onshape because it's the most painless cloud CAD tool
that produces clean STEP. You commit the STEP into git so the geometry
has a versioned home. You mirror the parameters into a Python file so
parameter changes show up as real diffs. You let CI rebuild every
derivative artifact on push. You ship a 3MF bundle to MakerWorld
because that's where consumer 3D printers actually look — and you
mirror to Printables (and link back to GitHub) because that's the open
door home. The Python tooling makes the whole loop reproducible.

The three projects so far:

| Project | Status | Lives on | Doc |
|---|---|---|---|
| Gear card | shipped | GitHub | [`README.md`](README.md) |
| Pounce-a-Pult | shipped | MakerWorld + GitHub | [`docs/pounce-a-pult/`](docs/pounce-a-pult/README.md) |
| Adam Savage vault | in progress | GitHub (sandbox printable now) | [`docs/vault/`](docs/vault/README.md) |

The vault is the spotlight worked example in this document — it's the
project where every pipeline stage is visible because we're walking
through it in real time.

## What makes something "shareable CAD" in this sense

The word "shareable" does a lot of work here. People share STLs on
Thingiverse every day; that's not what this is about. What we mean:

1. **Parametric.** The object isn't a frozen mesh — it's a small
   number of *parameters* that produce a mesh. Change a tooth count, a
   diameter, a thickness, and the whole thing re-derives.
2. **Single source of truth.** Every dimension lives in exactly one
   place. The Onshape document has it. A Python file mirrors it. Tests
   yell if a third file hardcodes one of those numbers.
3. **Code-trackable.** A parameter change is a one-line git diff with
   a commit message and a date. Not a screenshot of "revision 12 of
   the Onshape document, dated last spring."
4. **Derivable.** Every artifact a reader might want — exploded GIF,
   per-part STL, hero PNG, explainer page — is *built* by code that
   reads only from the source of truth. No artisanal copies.
5. **Printable.** The end-state of this whole loop is a 3D print
   someone else can produce in their own kitchen with a 3D printer
   they already own, without having to know any of the above.

The PyCon-talk kernel of all this is the **Python tooling that does
the deriving** — `cardlab`, `explainers`, `vault`. Those packages are
the *lab* where we work out what "processing 3D files at consumer
community level" actually means.

## The three projects so far

### Gear card — the kernel

Animated exploded view of the reduction-gear card

A 78 × 44 mm card with five compound gears giving 256:1 reduction
input-to-output. The card itself lives in
[a public Onshape document](https://cad.onshape.com/documents/786fefdef357fb6860b54650/w/33fb9222a6752311e4f08c8b/e/da99fedbaeebf1422d4cb0d3);
its STEP export sits at the repo root as [`jmcpheron-card.step`](jmcpheron-card.step);
the Python parameter mirror lives at
[`src/explainers/card.py`](src/explainers/card.py); the
[`cardlab`](src/cardlab/) CLI deconstructs the STEP into per-part
renders + an exploded GIF + a manifest; the [`explainers`](src/explainers/)
CLI generates six writeup pages, every number on every page sourced
from `card.py`. This is the project where the pipeline was born.

Lives on GitHub. CC BY-SA 4.0 on the geometry — change-and-share-back.

### Pounce-a-Pult — the MakerWorld proof point

Six parts of the pounce-a-pult fanning radially outward and back

A spiral-spring cat toy. Second project. The
[Onshape document](https://cad.onshape.com/documents/01739d2a63dc91eaf28c2c62/w/a7c671d651186a5272cc789f/e/fdb2542c5ccec8040d59912a)
is its real home; the
[MakerWorld bundle](https://makerworld.com/en/models/2138778-pounce-a-pult-spiral-cat-toy)
is where actual humans go to print it. The STEP file
[`step-demo/pounce-a-pult.step`](step-demo/pounce-a-pult.step)
is the bridge: `cardlab inspect / render / explode` runs the *same
five-function pipeline* used on the gear card — no toy-specific code
— and the auto-committed artifacts under
[`docs/pounce-a-pult/assets/`](docs/pounce-a-pult/) feed the page on
github.io.

Lives on **MakerWorld + GitHub**. CC BY 4.0 — intentionally more
permissive than the gear card, no share-alike strings, because cat
toys travel better that way.

### Adam Savage mini vault door — the walkthrough in progress

12-pin vault door mechanism — ring gear, 12 spurs, 12 rack-and-pin assemblies

A fan study of the 1/12-scale vault-door mechanism Adam Savage
machined on
[Tested.com](https://www.tested.com/). The third project, and the
slowest — partly because it's the most ambitious (12 pins on a 72 mm
BCD, three nested taper stages, a satellite gear train), partly
because we're documenting *while* we model. Everything is here:

- The video research, transcribed and distilled into [`docs/vault/specs.md`](docs/vault/specs.md).
- An [Onshape workflow doc](docs/vault/onshape-workflow.md) and [Onshape notes](docs/vault/onshape-notes.md) covering the FeatureScripts, the variable sheet, the gear math.
- A parametric **OpenSCAD sandbox** at [`docs/vault/sandbox/`](docs/vault/sandbox/) with a three-stage tapered door body, a full assembly with imported gear STLs, a self-contained ring-gear `.scad`, and a rack `.scad` that meshes with the satellite spurs. STLs ready to print today.
- A side-by-side **[Onshape ↔ OpenSCAD comparison doc](docs/vault/onshape-vs-openscad.md)** covering the tradeoff between cloud-CAD ergonomics and code-trackable text files.
- A build123d render pipeline at [`src/vault/mechanism.py`](src/vault/mechanism.py) producing the hero GIF above.
- Five canonical part STLs exported by [`vault export-parts`](src/vault/cli.py) under [`docs/vault/assets/parts/`](docs/vault/assets/parts/).

What's left to ship: the Onshape model itself (in progress), a 3MF
bundle for MakerWorld, a Printables mirror, and a few open dimension
questions (the [12 mm vs 10 mm pin diameter](docs/vault/specs.md)
revision Adam shows in Part 4; the three-stage taper angles).

The vault is the project where every pipeline stage is in flight at
the same time — which is why it's the example I keep coming back to
below.

## The pipeline stages

### Onshape as the source of truth

Onshape isn't open source. It's a cloud CAD app owned by PTC. We
recommend it anyway, because for the audience this pipeline is aimed at
— people who want to design a parametric 3D object and put it in
front of other humans without negotiating five command-line tools — it
is the most painless entry point that produces clean STEP. The
specifics that earn it the spot:

- **Public-readable URLs.** You can paste an Onshape link in your
  README and anyone with a browser can spin your design around. The
  gear card and Pounce-a-Pult both do this.
- **FeatureScript standard library.** Standard features (spur gears,
  threads, weld beads) are a click away. We use the
  ["Spur Gear" FeatureScript](docs/vault/onshape-notes.md) directly for
  every gear in the vault. No hand-drawn involutes.
- **Mate and Gear Relation UX.** Onshape's Assembly tab is genuinely
  good at making 12 satellite spurs rotate at the right ratio against
  a central ring gear. Code-driven CAD tools cannot beat that for
  iteration speed.
- **STEP export.** AP242 STEP is the lingua franca that lets every
  downstream tool (build123d, cascadio, OpenSCAD via STL, FreeCAD,
  CAM packages) read what Onshape made.

The cost is real, and worth naming. Onshape documents aren't
git-trackable. If PTC raises prices or shuts the free tier, your
geometry doesn't *vanish* — STEP exports survive — but the editing
environment does. We acknowledge the lock-in honestly and mitigate it
two ways: (a) commit STEP exports into git so the geometry has a
versioned home outside Onshape, and (b) keep the *numbers* in a Python
file so changing a parameter is independent of the editing UI. More on
that below.

### The Python parameter mirror

Every project in this repo has a single Python module that holds every
dimension. Other code reads *only* from that module:

- Gear card: [`src/explainers/card.py`](src/explainers/card.py) — `BIG_TEETH`, `PINION_TEETH`, `MODULE_MM`, the lot.
- Vault: [`src/vault/vault.py`](src/vault/vault.py) — door diameter, pin count, BCD, ring-gear bore, pressure angle, every cam parameter.

You change a number there, you run `uv run explainers build` or
`uv run vault build`, and every page, diagram, and (for the vault)
every parametric `.scad` file re-derives. There's a test
([`test_no_drift_between_sections`](tests/test_explainers.py)) that
checks every explainer markdown still contains the textual value of
the canonical parameters — so a literal-number sneaking into the
prose fails CI.

The Python mirror is what lets a parameter change be a 1-line git diff
with a commit message and a date. The Onshape variables are still the
*editing surface*; the Python module is the *diffable record*. They
have to stay in sync, and right now that sync is by hand (you change
a number in Onshape, you also change it in `card.py` / `vault.py`).
The hand-sync is the friction point most worth automating eventually.

### The Python kernel

The three packages [`cardlab`](src/cardlab/), [`explainers`](src/explainers/),
and [`vault`](src/vault/) are the *lab* the PyCon talk is built
around — small CLIs that demonstrate "processing 3D files at
consumer-community level."

`cardlab` is the workhorse, because STEP processing is the part most
people don't already have a recipe for:

| Command | Does |
|---|---|
| `cardlab inspect` | AP242 schema, assembly tree, bounding box, tessellation stats |
| `cardlab build` | Tessellates STEP → STL or coloured GLB |
| `cardlab render` | Orthographic PNG via OpenSCAD (iso / top / edge / front / right) |
| `cardlab explode` | Pulls an assembly apart into per-part STL/GLB/PNG + exploded GLB + animated GIF + manifest |
| `cardlab assemble` | Glues multiple STEP parts into one assembly |
| `cardlab spin` | Renders a gear chain *running* — parametric gears, frame-by-frame OpenSCAD, PIL-stitched into a GIF |

`explainers` and `vault` generate the per-page writeups: SVG diagrams
via [`drawsvg`](https://github.com/cduck/drawsvg), charts via
matplotlib, markdown that reads from the parameter file.

The packages split into a **light toolchain** (drawsvg + matplotlib,
fast install, builds the explainer pages) and a **heavy toolchain**
(build123d + cadquery-ocp + OpenSCAD + xvfb, ~180 MB OpenCascade
wheel, builds the STEP-derived renders and the GIFs). Anyone who just
wants to fix a typo in an explainer page doesn't need OpenCascade.
The split is in
[`pyproject.toml`'s optional dependencies](pyproject.toml):
`--extra explainers` is the light one, `--extra step` is the heavy
one. CI uses both.

### GitHub as the workshop

This repo's working pattern, generalised:

1. **The README tells the story.** Hero GIF, what it is, how it
   works, how to print one. Not "documentation" — narrative. The
   [gear-card README](README.md) is the canonical example.
2. **CI auto-builds derived artifacts on push.** Three workflows
   ([`build-card.yml`](.github/workflows/build-card.yml),
   [`build-explainers.yml`](.github/workflows/build-explainers.yml),
   [`build-vault.yml`](.github/workflows/build-vault.yml)) each watch
   their own input paths and write to disjoint output paths. They each
   `git pull --rebase` and retry on push rejection, so they can race
   each other (and human pushes) without conflict.
3. **Issues are for design discussion.** "Should the pin be 10 mm or
   12 mm?" is an issue, not a Slack thread.
4. **PRs are for parameter changes.** Bump a number, regenerate the
   diagrams, look at the diff. The diagrams are part of the diff.
5. **GitHub Pages deploys `docs/`.** Anyone who doesn't have a clone
   can still read the markdown.

The auto-commit-on-push pattern is the one trick most other CAD repos
don't do — it's what makes "change one number, rebuild everything" a
real workflow instead of a documentation lie. It's worth copying.

### MakerWorld + Printables as the storefronts

Once a design is ready for non-programmer humans, ship it to the two
biggest FDM-hobbyist sharing sites:

- **MakerWorld** is owned by Bambu Lab, the dominant consumer
  3D-printer maker right now. It bundles slicer profiles with prints,
  which dramatically lowers the "first print works" failure rate. Its
  audience is enormous. It is also somewhat closed — login-gated,
  account-bound, with a points system tilted toward originating-on-MW.
  We share there because that's where the audience is.
- **Printables** is owned by Prusa. Looser, more open. The default
  share-licence is more permissive. Smaller audience but a sturdier
  community.

The pattern is to publish to **both**, with the 3MF bundle as the
binary artifact and the GitHub repo as the parametric source. Each
listing should link back to the others:

```
   MakerWorld listing ──► ──► ──► GitHub repo ──► Onshape doc
              ▲                       │
              └─── Printables listing ┘
```

The Pounce-a-Pult is the existing template here — its
[MakerWorld page](https://makerworld.com/en/models/2138778-pounce-a-pult-spiral-cat-toy)
is the bundle, [its GitHub page](docs/pounce-a-pult/README.md) carries
the parametric story, and the
[Onshape doc](https://cad.onshape.com/documents/01739d2a63dc91eaf28c2c62/w/a7c671d651186a5272cc789f/e/fdb2542c5ccec8040d59912a)
is where the geometry lives. The vault will follow the same pattern
once the Onshape model is finished.

## The open-source ↔ consumer-friendly tension

The pipeline forces a question: if MakerWorld is closed-ish, why
publish there at all? Why not just throw everything on Printables and
GitHub and tell people to clone the repo?

Because that's not where most consumers are. A first-time 3D printer
owner with a Bambu A1 in their kitchen is more likely to open the
Bambu Handy app and search MakerWorld than to type git URLs into a
terminal. Pretending otherwise just keeps a smaller audience.

The core belief this pipeline tries to live by:

- **The source of truth stays open.** The Onshape document is public.
  The Python parameter file is in git under MIT. The STEP file is in
  git under CC BY-SA 4.0 (or CC BY 4.0 for permissive cases like the
  Pounce-a-Pult). Anyone who wants to fork the *editable thing* can.
- **The derived bundle goes where the audience is.** MakerWorld gets
  a 3MF + slicer profile + photos. The bundle is the "click to print"
  consumer thing — it isn't where remixing happens, it's where the
  audience already lives.
- **Every listing links back to the others.** A MakerWorld viewer
  who wants to change the geometry sees, in the description, "Remix
  the CAD in Onshape" and "Full source on GitHub." A GitHub visitor
  sees the MakerWorld link in the README. Nobody is trapped in any
  single platform.

The licenses (MIT for code; CC BY-SA 4.0 or CC BY 4.0 for geometry;
see [`ACKNOWLEDGMENTS.md`](ACKNOWLEDGMENTS.md)) are the legal
expression of this stance. The dual-publish pattern is the practical
expression.

## Recommended repo layout

Generalised from what `pycon2026/` already does:

```
<project>/
├── README.md              # Project story. Hero GIF at the top. The story is the doc.
├── SHAREABLE-CAD.md       # This doc, or a pointer to it.
├── LICENSE                # MIT for code.
├── LICENSE-3D-FILES       # CC BY-SA 4.0 (default) or CC BY 4.0 (permissive variant).
├── ACKNOWLEDGMENTS.md     # Third-party tools + licenses + Onshape doc link.
├── <project>.step         # The Onshape STEP export. Lives at the root, gets committed.
├── docs/
│   ├── assets/<project>/  # Hero render, exploded GIF, per-part PNGs.
│   ├── explainers/        # Markdown + SVG, generated from src/explainers/.
│   ├── sandbox/           # OpenSCAD playground (optional, not auto-built).
│   └── makerworld/        # 3MF bundle source + slicer profile (when ready).
├── src/
│   ├── <thing>lab/        # Python CLI: inspect/build/render/explode/spin.
│   └── explainers/        # Parametric doc generator. Owns the parameter file.
├── tests/                 # Drift tests: numbers in markdown == numbers in parameters.py.
└── .github/workflows/     # Auto-build + auto-commit derived artifacts on push.
```

Canonical examples in *this* repo for each row:

- README pattern → [`README.md`](README.md) (gear card) and [`docs/pounce-a-pult/README.md`](docs/pounce-a-pult/README.md).
- License pair → [`LICENSE`](LICENSE) + [`LICENSE-3D-FILES`](LICENSE-3D-FILES).
- ACKNOWLEDGMENTS → [`ACKNOWLEDGMENTS.md`](ACKNOWLEDGMENTS.md).
- STEP at root → [`jmcpheron-card.step`](jmcpheron-card.step).
- Sandbox playground → [`docs/vault/sandbox/`](docs/vault/sandbox/).
- Python kernel → [`src/cardlab/`](src/cardlab/).
- Parameter file → [`src/explainers/card.py`](src/explainers/card.py), [`src/vault/vault.py`](src/vault/vault.py).
- Auto-commit workflows → [`.github/workflows/`](.github/workflows/).

## Onshape conventions

Pulled from
[`docs/vault/onshape-workflow.md`](docs/vault/onshape-workflow.md) and
[`docs/vault/onshape-notes.md`](docs/vault/onshape-notes.md), which
were written *while* modelling the vault and are the load-bearing
references:

1. **Make the document publicly readable.** Right-click → Share →
   anyone with the link. Put the URL in the README.
2. **Variables at the top of the Part Studio.** Every parameter the
   Python file has, define as an Onshape variable: `#door_diameter`,
   `#pin_count`, `#cam_rotation`. Drive every sketch dimension from
   the variable. This is your editing surface.
3. **Mirror the variables in your Python parameter file.** Same
   names, same units. They have to be kept in sync by hand — there's
   no automation for this yet — and the [Onshape ↔ Python table](docs/vault/onshape-workflow.md)
   is the canonical record of which mirrors which.
4. **Use FeatureScript for standard features.** Don't hand-draw
   involute gear teeth, threads, or splines. The Onshape standard
   library has them. [Spur Gear settings](docs/vault/onshape-notes.md)
   for our use cases are documented end-to-end.
5. **STEP export to repo root.** When a model is "ready enough,"
   export AP242 STEP, commit at the project root. Auto-commit
   workflows take over from there.

## GitHub conventions

What this repo does that's worth copying:

- **A front-door README that tells a story**, hero image first. The
  gear-card README opens with the exploded GIF before any prose — the
  GIF *is* the elevator pitch.
- **Auto-commit derived artifacts on push.** Three workflows
  ([`build-card.yml`](.github/workflows/build-card.yml),
  [`build-explainers.yml`](.github/workflows/build-explainers.yml),
  [`build-vault.yml`](.github/workflows/build-vault.yml)) each watch
  their own input paths, run their pipeline, and `git push` the
  output back to `main` with a rebase-and-retry loop. They write to
  disjoint paths so they can race.
- **Light vs heavy dependency extras** in `pyproject.toml` so
  contributors who only want to edit prose aren't forced into a 180
  MB OpenCascade wheel.
- **Pages workflow** publishes `docs/` to github.io for non-cloners.
- **A devlog**. [`docs/devlog/`](docs/devlog/) is where build journal
  entries live — informal, dated, the human story alongside the
  generated artifacts.

## MakerWorld + Printables prep

When a design is ready to ship to consumer 3D printer owners, the
bundle is:

1. **Hero render** — a single iso PNG that reads at thumbnail size.
   `cardlab render --angle iso` makes one.
2. **Per-part STLs** — what the slicer actually consumes. `cardlab
   explode` writes them under `assets/parts/`.
3. **3MF (preferred over STL)** — bundles part orientation,
   per-part colour, and printer-specific settings. Bambu Studio /
   PrusaSlicer both export.
4. **Slicer profile** — the `.gcode.3mf` or `.3mf` with the project's
   tested-good slicer settings baked in. MakerWorld highlights this.
5. **Photos in the wild** — a print on a desk, a cat playing with
   the toy, the card in someone's hand. Social proof that the design
   prints.
6. **Links back to GitHub and Onshape** — every consumer-site listing
   should have these in the description.

The [Pounce-a-Pult MakerWorld page](https://makerworld.com/en/models/2138778-pounce-a-pult-spiral-cat-toy)
is the existing template. Copy its structure.

## The vault as worked example

Where the Adam Savage vault is, as of this writing:

**Done.**

- Distilled five videos of source material into [`docs/vault/specs.md`](docs/vault/specs.md) with a per-row source tag and a "Discrepancies" table flagging the 12 mm vs 10 mm pin diameter question.
- Built an Onshape-conventions doc at [`docs/vault/onshape-notes.md`](docs/vault/onshape-notes.md) covering ring-gear and satellite-spur FeatureScript settings, the derived consistency-check numbers, and the four Assembly-tab operations (Revolute / Gear Relation / Rack-and-Pinion Relation / Circular Pattern) that turn one modelled spur into the timed 12-pin mechanism.
- A parametric OpenSCAD sandbox at [`docs/vault/sandbox/`](docs/vault/sandbox/) with:
  - [`door.scad`](docs/vault/sandbox/door.scad) — three-stage tapered puck, pin bores in the cylindrical back stage, ring-boss recess, spur-axle bolt circle.
  - [`assembly.scad`](docs/vault/sandbox/assembly.scad) — full mechanism using imported STLs for the gears, parametric pins, with a single `cam_progress` slider driving ring rotation, spur counter-rotation, and pin extension together.
  - [`ring_gear.scad`](docs/vault/sandbox/ring_gear.scad) — self-contained parametric spur gear, no libraries. Exports to STL.
  - [`rack.scad`](docs/vault/sandbox/rack.scad) — parametric rack meshing with the 24-tooth satellite spurs. Exports to STL.
- A side-by-side [Onshape ↔ OpenSCAD comparison](docs/vault/onshape-vs-openscad.md) covering the tradeoff between cloud-CAD ergonomics and code-trackable text files, with the ring gear as the worked example.
- A build123d render pipeline at [`src/vault/mechanism.py`](src/vault/mechanism.py) producing the hero GIF from `vault.py`.
- Five canonical printable part STLs at [`docs/vault/assets/parts/`](docs/vault/assets/parts/), exported by [`vault export-parts`](src/vault/cli.py).

**Next.**

- Finish the Onshape model. The geometry decisions (three-stage taper, pin diameter) get resolved in `specs.md` first; then they get into the Onshape variables, then into `vault.py`.
- Resolve the open dimension discrepancies in [`specs.md`'s Discrepancies table](docs/vault/specs.md).
- Bundle a 3MF + slicer profile.
- Publish to MakerWorld with the bundle.
- Mirror to Printables.
- Cross-link all three.

When that's done, the vault becomes the second project to fully
traverse the pipeline (after the Pounce-a-Pult). At that point this
doc gets updated with "the vault, as shipped."

## Starter checklist — kicking off your own project

Use this as the kickoff sequence for a new shareable-CAD project,
roughly in order:

1. **Pick a parametric CAD object.** Something small enough to print
   in one job. Something where changing a parameter is *interesting*
   to a remixer (a tooth count, a length, a bolt spacing).
2. **Build it in Onshape.** Make the document publicly readable.
   Put every dimension in a variable at the top of the Part Studio.
3. **Create a GitHub repo.** Mirror the layout in the "Recommended
   repo layout" section above. MIT for the code, CC BY-SA 4.0 (or
   CC BY 4.0 if you want permissive) for the geometry.
4. **Commit the STEP export at the repo root.** This is the bridge
   between Onshape and everything downstream.
5. **Write `parameters.py` (or `<project>.py`).** Mirror every
   Onshape variable as a Python constant. Use it from every other
   Python file in the repo. Reference [`src/vault/vault.py`](src/vault/vault.py)
   as the template.
6. **Wire up `cardlab` or a `cardlab`-style CLI.** At a minimum,
   `inspect` and `render`. `explode` if the design has multiple
   parts. (Copying `cardlab` and renaming `<thing>lab` is a fine
   starting point — it's not yet a published library; it's a pattern
   to fork.)
7. **Write your first explainer page** generated from the parameter
   file. Even if it's just one page that says "this has N teeth, here
   is what N teeth looks like, here is what changes if you change
   N." That page becomes the README's deep-link.
8. **Wire up auto-commit CI.** Copy [`build-card.yml`](.github/workflows/build-card.yml)
   as your starting point. Make it watch your STEP path and your
   Python kernel path. Make it write to disjoint output paths so it
   doesn't fight the human pushes.
9. **Ship a Printables listing** with the STEP file and the
   generated STLs. Link back to your GitHub repo and Onshape doc.
10. **Bundle a 3MF and ship a MakerWorld listing.** Test print first;
    include the slicer profile; include photos. Link back to
    Printables, GitHub, and Onshape.
11. **Open a [`docs/devlog/`](docs/devlog/) entry** for ongoing build
    notes. Future-you will thank present-you.
12. **Update the README's front-door story** as the project evolves.
    The README is not docs; it's the elevator pitch with a hero GIF.

That's the pattern. Three projects so far have used it; the vault is
the fourth in flight; this document is the first time it's been
written down. If you build something with this pipeline, please open
an issue and link back — the goal is for the pattern itself to be
remixable.

---

*Companion to [`README.md`](README.md). The vault project at
[`docs/vault/`](docs/vault/) is the spotlight worked example. The
gear card ([`README.md`](README.md)) and Pounce-a-Pult
([`docs/pounce-a-pult/`](docs/pounce-a-pult/README.md)) are the
already-shipped proof points.*

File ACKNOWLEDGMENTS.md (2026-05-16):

# Acknowledgments

This repo is a thin layer of glue on top of a lot of other people's
work. Below is a list of the third-party tools and libraries that
make it possible, with their licenses and links. Where we redistribute
or modify any of their code (we don't — they're all dependencies pulled
from PyPI / apt / etc.), the upstream license text travels with the
package.

If something we use isn't credited here, that's a bug — please open an
issue or a PR.

## Python libraries (pulled in via `pyproject.toml`)

| Project | License | Used for |
|---|---|---|
| [`build123d`](https://github.com/gumyr/build123d) | [Apache-2.0](https://www.apache.org/licenses/LICENSE-2.0) | Parametric CAD modelling — reading the card STEP file in `cardlab`, generating the vault mechanism geometry in `src/vault/mechanism.py`, and the spinning gear chain in `src/cardlab/spin.py`. |
| [`bd_warehouse`](https://github.com/gumyr/bd_warehouse) | [Apache-2.0](https://www.apache.org/licenses/LICENSE-2.0) | Parametric gear primitives (`SpurGear`) on top of `build123d`. Drives the ring gear + spur gears in the vault mechanism animation **and** the 40-tooth driven + 10-tooth pinion compound gears in the card-spinning animation. |
| [`cadquery-ocp`](https://github.com/CadQuery/OCP) | [Apache-2.0](https://github.com/CadQuery/OCP/blob/master/LICENSE) | Python bindings to the [Open CASCADE Technology](https://dev.opencascade.org/) (OCCT) geometry kernel. Underlies `build123d`. |
| [`cascadio`](https://github.com/trimesh/cascadio) | [MIT](https://github.com/trimesh/cascadio/blob/main/LICENSE) | STEP → coloured GLB in one OCCT pass. Preserves Onshape's per-part colours through the `cardlab build` pipeline. |
| [`trimesh`](https://github.com/mikedh/trimesh) | [MIT](https://github.com/mikedh/trimesh/blob/main/LICENSE.md) | Mesh manipulation — used by `cardlab.explode` to enumerate per-part centroids and bboxes, and by the `decoding` explainer to slice the gear STL. |
| [`Pillow`](https://github.com/python-pillow/Pillow) | [MIT-CMU](https://github.com/python-pillow/Pillow/blob/main/LICENSE) | PNG → GIF stitching for the exploded-view animation (`cardlab.explode`) and the vault mechanism animation (`vault.mechanism`). |
| [`drawsvg`](https://github.com/cduck/drawsvg) | [MIT](https://github.com/cduck/drawsvg/blob/master/LICENSE.txt) | SVG generation for every explainer diagram and every vault topic diagram. |
| [`matplotlib`](https://matplotlib.org/) | [PSF-based](https://matplotlib.org/stable/users/project/license.html) | Charts in `src/explainers/` (the `decoding` and `ratios` explainers in particular). |
| [`click`](https://github.com/pallets/click/) | [BSD-3-Clause](https://github.com/pallets/click/blob/main/LICENSE.rst) | Command-line interfaces for all three CLIs (`cardlab`, `explainers`, `vault`). |
| [`pytest`](https://github.com/pytest-dev/pytest/) | [MIT](https://github.com/pytest-dev/pytest/blob/main/LICENSE) | Test runner. |

## External tools (system-level)

| Project | License | Used for |
|---|---|---|
| [OpenSCAD](https://openscad.org/) | [GPL-2.0-or-later](https://github.com/openscad/openscad/blob/master/COPYING) | PNG rendering of every per-part view and every animated frame. Invoked as a subprocess (no linking). |
| [Xvfb](https://x.org/releases/X11R7.7/doc/man/man1/Xvfb.1.xhtml) | [MIT/X11](https://gitlab.freedesktop.org/xorg/xserver/-/blob/master/COPYING) | Headless X display for OpenSCAD in CI runners. |
| [`uv`](https://github.com/astral-sh/uv) | [Apache-2.0 / MIT](https://github.com/astral-sh/uv?tab=readme-ov-file#license) | Python dependency management — the only thing you need to install before `uv sync --extra step`. By [Astral](https://astral.sh/). |
| [Onshape](https://www.onshape.com/) | proprietary platform | Source of the original `jmcpheron-card.step` ([public document](https://cad.onshape.com/documents/786fefdef357fb6860b54650/w/33fb9222a6752311e4f08c8b/e/da99fedbaeebf1422d4cb0d3)). |
| [GitHub Actions](https://github.com/features/actions) | proprietary platform | CI runner that auto-rebuilds the GIFs, SVGs, and markdown on every push. |

## Inspirations (no code reused)

- **Adam Savage's mini vault-door build** on [Tested](https://www.tested.com/). The vault-door study under [`docs/vault/`](docs/vault/) is a love-letter to the *geometry* of his mechanism — a fan study, not a clone, not affiliated with Tested.com or Adam Savage. No private plans or assets from the show are used.

## A second 3D-files license — CC BY 4.0 for the Pounce-a-Pult

- **Pounce-a-Pult spiral cat toy** ([`step-demo/pounce-a-pult.step`](step-demo/pounce-a-pult.step) and every render under [`docs/pounce-a-pult/assets/`](docs/pounce-a-pult/assets/)): another of my designs, published under [Creative Commons Attribution 4.0 (CC BY)](https://creativecommons.org/licenses/by/4.0/) — intentionally more permissive than the rest of this repo's 3D files. Two canonical locations:
  - Parametric CAD source: [public Onshape document](https://cad.onshape.com/documents/01739d2a63dc91eaf28c2c62/w/a7c671d651186a5272cc789f/e/fdb2542c5ccec8040d59912a). This is where the geometry actually *lives* — open it in a browser to inspect, fork it into a free Onshape account to remix.
  - Printable bundle: [MakerWorld model page](https://makerworld.com/en/models/2138778-pounce-a-pult-spiral-cat-toy#profileId-2316710). Slicer profile, photos, assembly tips.

  The committed STEP file and every derived render (PNGs, GIF, GLB, per-part STLs) under `docs/pounce-a-pult/` are CC BY 4.0 with attribution to me. This is distinct from the rest of the repo's 3D files (the gear card and vault diagrams), which are CC BY-**SA** 4.0 under [`LICENSE-3D-FILES`](LICENSE-3D-FILES).

## How the licenses interact with this repo

* **Our code** under `src/`, `tests/`, and the GitHub workflows is **MIT** ([`LICENSE`](LICENSE)).
* **Most of our 3D files** — the committed gear-card STEP, and every STL / GLB / PNG / GIF generated under `docs/assets/card/` and `docs/vault/assets/` — are **CC BY-SA 4.0** ([`LICENSE-3D-FILES`](LICENSE-3D-FILES)).
* **The Pounce-a-Pult** ([`step-demo/pounce-a-pult.step`](step-demo/pounce-a-pult.step) and everything under `docs/pounce-a-pult/`) is also my design but is published under **CC BY 4.0** — deliberately looser, no share-alike. See the section above.
* **Dependencies** retain their own licenses. We do not redistribute their source; we import them from PyPI / install them from apt. Anyone reproducing this project pulls them from the same upstream sources.
* **OCCT** (under `cadquery-ocp`) is LGPL-2.1 with an exception that permits dynamic linking from non-GPL applications. We use it through `build123d`'s Python API only.
* **OpenSCAD** (GPL-2.0-or-later) is invoked as a separate process via `subprocess.run`. No source linking; the GPL doesn't extend across the subprocess boundary.

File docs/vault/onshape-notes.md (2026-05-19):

# Onshape working notes

CAD-tool-specific guidance, distilled from initial research and updated as I
go. `specs.md` is for *what* to model; this file is for *how* to model it in
Onshape specifically.

## FeatureScripts to use

Don't hand-draw involute gear teeth — Onshape's standard custom-feature
library has a **Spur Gear** generator. Add it via "Add custom features" in any
Part Studio.

| Gear | Settings |
| --- | --- |
| Spur gear (qty 12) | Module 0.5, 24 teeth, **External** |
| Ring gear | Module 0.5, 120 teeth, **External** (it's a sun gear — see below) |

The 2.4-in outer-diameter target on the ring gear should fall out of the math
once module and tooth count are right; verify against `specs.md` after generating.

> **Naming note.** "Ring gear" is what Adam calls it in the video, but
> topologically it's a *sun gear* — the 12 spurs orbit it on the outside,
> meeting its outward-facing teeth. An *internal* ring/annulus gear has
> teeth on the inside of an annulus with planets sitting inside. Set
> `Internal = OFF` in the FeatureScript or the spurs won't mesh.

## Assembly: getting them to mesh

1. **Revolute Mate** each gear and pin to the base plate so it can rotate
   about its axis.
2. **Gear Relation** between the ring gear and each spur gear. Onshape derives
   the 5:1 ratio from the tooth counts automatically (no need to type it).
3. For the locking pins, a **Rack and Pinion Relation** (rather than Gear
   Relation) ties each pin's linear motion to its spur gear's rotation.

Driving the ring gear should then animate all 12 pins extending in unison.

## Ring gear in Onshape — module math, then two ways to cut teeth

### What "module" actually is

Gear *module* (`m`) is the millimetres of **pitch diameter per tooth**.

```
pitch_diameter = m × N           (N = tooth count)
pitch_radius   = m × N / 2
```

The *pitch circle* is the imaginary circle where two meshing gears
touch tangentially — not the outer (tooth-tip) or root (tooth-bottom)
circle. The tooth-tip circle is one module *bigger* than the pitch
circle on each side:

```
tip_diameter  = pitch_diameter + 2·m   (external gear)
root_diameter = pitch_diameter − 2.5·m (external gear, with clearance)
```

**Two gears can only mesh if they share the same module.** Module is
to gears what thread pitch is to screws — it's the "compatibility
key". For this build, every gear is module `0.5 mm`.

Plugging in Adam's numbers:

| Gear | `m × N` | Pitch dia | Tip dia (outer) |
| --- | --- | --- | --- |
| Spur (×12) | 0.5 × 24 | 12.0 mm | 13.0 mm |
| Ring (sun)  | 0.5 × 120 | 60.0 mm | 61.0 mm |

The 61.0 mm tip diameter is **2.401 in** — exactly the OD Adam
measures in the video. That's the consistency check after generating
the gear: if Onshape's "outer diameter" readout is anything but
61 mm, the module or tooth count is wrong.

### Spur-gear centre distance falls out of the same math

For two external gears in mesh the centres are spaced by the *sum* of
their pitch radii:

```
centre_distance = (pitch_radius_ring + pitch_radius_spur)
                = (60/2) + (12/2)
                = 30 + 6
                = 36 mm
```

Twice that = 72 mm BCD — which matches Adam's 72 mm bolt-circle
exactly. So once `m`, ring teeth, and spur teeth are set, the 72 mm
BCD isn't a free parameter; it's a derived consequence.

### Approach A — Spur Gear FeatureScript (recommended)

This is the path the table above is pointing at. Two clicks per gear,
no manual involute drawing.

1. In a Part Studio: **Add custom features → search "Spur Gear" →
   install** the Onshape Inc. one. (You only do this once per
   document.)
2. Toolbar → **Spur Gear** icon.
3. Inputs:
   * `Module` = `#gear_module` (= 0.5 mm)
   * `Number of teeth` = 120 for the ring, 24 for the spur
   * `Pressure angle` = 20° (modern; 14.5° only matters for our
     OpenSCAD-rendered preview where build123d hits numerical limits)
   * `Face width` (i.e. thickness) = whatever the door cavity allows.
     For Adam's stack a few mm is fine.
   * **`Internal` = OFF** — both the ring/sun and the spurs are
     external. Flipping Internal ON makes the FeatureScript carve
     teeth into the *inside* of an annulus, which is the wrong
     topology for this build.
   * `Centre hole` — optional. The spurs need one for their
     shoulder-bolt axle; the ring needs one for the 2.003 in mounting
     boss (= 50.876 mm).
4. Pick the sketch plane (Top is fine) and confirm.

The result is a full involute-toothed gear, mathematically perfect.

### Approach B — Sketch + Pattern Remove (manual)

Worth doing **once**, on a low-tooth-count gear, to actually feel how
the involute shape comes out. Don't do this for the 120-tooth ring —
it'll be 120 hand-tuned cuts.

1. **Blank**: a cylinder, diameter = `tip_diameter = m·N + 2·m`.
2. **One tooth gap**: sketch a single tooth-shaped void at the top of
   the blank. The "right" curve is an involute of a base circle
   (`base_diameter = pitch_diameter · cos(pressure_angle)`), but for
   visualisation a symmetric V-shape with the included angle set to
   `360° / N − 2·pressure_angle` reads correctly at low tooth counts.
3. **Extrude → Remove** that sketch through the blank.
4. **Linear/Circular Pattern**: pattern the Remove feature `N` times
   around the axis. The pattern angle is `360° / N`.

For a 24-tooth spur this gets you a passable gear in 5–10 minutes.
For the 120-tooth ring it would take an hour and look worse than the
FeatureScript output. The reason to do it once is so the module /
pitch-circle relationship stops being abstract — you literally
*drew* the pitch circle to position the tooth gap, and you watched
the tooth count drive the pattern step.

### Verifying the mesh in the Assembly tab

Whichever approach you used:

1. Insert the ring and one spur into an Assembly.
2. **Fix** the ring at the origin.
3. **Revolute mate** the spur to a sketch point on the ring's 72 mm
   BCD. The spur should spin freely around its own axis.
4. **Gear Relation**: select the ring's revolute and the spur's
   revolute. Onshape derives the 5:1 ratio from the tooth counts
   (120 / 24); you should not have to type it.
5. Drag the ring with your mouse. The spur spins. If the *teeth visibly
   collide* rather than glide, the centre distance is off by a fraction
   of a mm — usually because the BCD was typed in by hand instead of
   computed from `(m·N_ring + m·N_spur) / 2`.

## Satellite spur gears (the 12 that drive the racks)

You model **one** spur gear and Circular Pattern it 12× around the
72 mm BCD in the Assembly tab. Same Spur Gear FeatureScript as the
ring — only a few fields change.

### Spur Gear FeatureScript settings

| FeatureScript field | Value | Why |
| --- | --- | --- |
| Gear input type | Module | Adam's build is metric. |
| **Module** | `0.5 mm` | Must match the ring AND the rack. Module is the gear-compatibility key. |
| **Number of teeth** | `24` | [Part 2]; gives a 5:1 ratio against the 120-tooth ring. |
| Pressure angle | `20°` | Modern AGMA standard. (14.5° only matters for the OpenSCAD-rendered preview where build123d hits numerical limits.) |
| Helix angle | `0°` | Spur, not helical. |
| **Internal** | **OFF** | Same as the ring — external teeth. |
| **Face width / Thickness** | `8 mm` (or `4 mm` for a schematic study) | Match the 8 × 8 mm rack stock so the rack-and-pinion mesh is full-width. |
| Center hole | ON, diameter `bolt_dia + 0.1 mm` | Shoulder-bolt axle slip-fit. Adam's rule from [Part 2]: gear bore is 0.1 mm larger than the bolt's smooth shoulder OD. Pick the bolt first, then size the bore. |
| Sketch plane | Top (or the door-cavity inner face) | Doesn't affect geometry — placement happens in the Assembly. |

### Derived numbers (consistency checks after generating)

| Quantity | Value | Formula |
| --- | --- | --- |
| Pitch diameter | `12 mm` | `m × N = 0.5 × 24` |
| Tip (outer) diameter | `13 mm` | `pitch + 2·m` |
| Root diameter | `10.75 mm` | `pitch − 2·1.25·m` |
| Centre distance to ring | `36 mm` | `pitch_radius(ring) + pitch_radius(spur) = 30 + 6` |
| BCD | `72 mm` | `2 × centre_distance` — matches Adam's drawing [Part 2] |

If Onshape's readout doesn't say `tip_diameter = 13 mm` after the
FeatureScript runs, the module or tooth count is wrong.

### In the Assembly tab

The Spur Gear feature only creates the part. The actual *mechanism*
comes from four Assembly-level operations:

1. **Revolute Mate** the spur to a sketch point on the **72 mm BCD**.
   It should spin freely about its own axis.
2. **Gear Relation** between the ring's revolute and this spur's
   revolute → Onshape derives the 5:1 ratio from tooth counts
   (120 / 24) automatically.
3. **Rack-and-Pinion Relation** between this spur's revolute and the
   corresponding pin's **Slider Mate**. Onshape uses the spur's pitch
   radius (6 mm) to convert rotation to linear travel:
   * One full spur rotation = `2π × 6 ≈ 37.7 mm` of linear pin travel.
   * Canonical `PIN_TRAVEL_MM = 8 mm` requires `≈ 76°` of spur rotation.
   * Which back-derives to `≈ 15°` of ring rotation (the 5:1 ratio) —
     close to the canonical `CAM_ROTATION_DEG = 10°` budget.
4. **Circular Assembly Pattern** of the (spur + rack + pin)
   sub-assembly, 12× around the door axis. One click and Onshape
   mathematically guarantees identical timing across all 12 pins —
   sidestepping the concentricity rework Adam describes in [Part 4].

> **Sub-assembly tip.** Build "1 spur + 1 rack + 1 pin" as a separate
> Assembly tab, get the revolute / slider / rack-and-pinion relations
> right *once*, then insert that sub-assembly into the main door
> assembly 12 times. Keeps the mating tree clean.

## Gotchas & lessons learned

_(Add entries here as I run into them.)_

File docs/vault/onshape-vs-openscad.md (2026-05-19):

# Onshape vs OpenSCAD — for code-tracked CAD

Both Onshape and OpenSCAD are *parametric* CAD. You set knobs, the
model rebuilds. But they sit at opposite ends of a spectrum that
matters if you live in `git`: **where the source of truth lives, and
how a future you re-derives the model from it**.

This page exists because the same ring gear in this build can be made
with either tool. Both paths work. The point isn't to declare a winner
— it's to be clear about what you trade for what.

## TL;DR

| Question | Onshape | OpenSCAD |
| --- | --- | --- |
| Where does the source of truth live? | Cloud document with versioned revisions | Plain `.scad` text file in `git` |
| What does a "diff" look like? | Visual A↔B revision compare in the browser | `git diff` — line-level, attribution-able |
| Can I rebuild this from a 2-year-old commit? | Only if the Onshape doc still exists *and* its FeatureScripts haven't been version-bumped | Yes, deterministically — same `openscad` + same `.scad` = same STL |
| Does it work offline? | No | Yes |
| Best at? | Assemblies with motion (mates, joints, gear relations) | Math-driven parts, parameter sweeps, programmatic generation |
| Worst at? | Things that need to be checked into `git` | Organic / sculpted shapes |
| Cost (this project) | Free (public docs) | Free, MIT |
| Export to STEP? | Yes (native CAD kernel) | No (mesh-based, STL/3MF/AMF only) |
| Library ecosystem | FeatureScripts (cloud, embedded in CAD) | BOSL2, MCAD, NopSCADlib (installed locally) |

## What they have in common

If you squint, the **mental model is the same**:

1. Define parameters.
2. Express the geometry as expressions of those parameters.
3. Tweak a parameter, the whole model re-derives.

Both produce STL. Both can drive a 3D printer or downstream
simulation. Both can be parametrically *configured* (Onshape's
"configurations" / OpenSCAD's `// [Customizer]` blocks).

The whole gear-math derivation in
[`onshape-notes.md`](onshape-notes.md) — module, pitch circle, tip
circle, root circle, centre distance from sum of pitch radii — is
*identical* in both tools. It has to be: it's just the underlying
gear geometry. The tools differ in how you *type* it.

## Where they diverge: the ring gear, two ways

### Onshape

Four clicks, no math typed out by you:

1. Add custom feature → install "Spur Gear" once.
2. Open the Spur Gear feature.
3. Fill in: `Module = 0.5`, `Teeth = 120`, `Pressure angle = 20°`,
   `Face width = 4 mm`, `Bore dia = 50.876 mm`, **`Internal = OFF`**.
4. Confirm.

You don't see `pitch_radius = m·N / 2` anywhere. The FeatureScript
computed it; the GUI just rendered the result. This is fast, ergonomic,
and the resulting involute is metrology-grade. If you change a
parameter, the gear updates in real time.

Where this leaves you for "code tracking":

* The parameter values live inside a cloud document.
* If you delete the document, the gear is gone. If Onshape rolls a new
  FeatureScript version, the same numbers might generate a *slightly
  different* gear.
* Diffs are visual ("compare this revision to that revision"). They
  read well for shape changes ("the bore moved 2 mm") but poorly for
  parameter changes ("which of the 17 numbers changed from r12 to
  r13?").
* You can export a STEP or STL and check those into git, but those are
  *artifacts*, not sources. Re-editing them downstream defeats the
  parametric workflow.

### OpenSCAD

The same gear, expressed as text you can `git diff`:

```scad
// docs/vault/sandbox/ring_gear.scad — excerpt
function pitch_radius(n, m) = n * m / 2;
function tip_radius(n, m)   = pitch_radius(n, m) + m;
function root_radius(n, m)  = pitch_radius(n, m) - 1.25 * m;

module gear_2d(n, m, pa) {
    pitch_r = pitch_radius(n, m);
    tip_r   = tip_radius(n, m);
    root_r  = root_radius(n, m);
    half_arc_at_pitch = m * PI / 4;
    half_root_y = half_arc_at_pitch + (pitch_r - root_r) * tan(pa);
    half_tip_y  = max(half_arc_at_pitch - (tip_r - pitch_r) * tan(pa),
                      0.02);
    union() {
        circle(r = root_r);
        for (k = [0 : n - 1])
            rotate([0, 0, k * 360 / n])
                polygon(points = [
                    [root_r, -half_root_y],
                    [root_r,  half_root_y],
                    [tip_r,   half_tip_y],
                    [tip_r,  -half_tip_y],
                ]);
    }
}
```

The full file is ~80 lines including comments and the satellite-spur
demo. Run `openscad -o ring_gear.stl -D 'show_spurs=false'
ring_gear.scad` and you get a 2708-facet STL you can print.

* **`git log` is your design history.** Every change to a parameter is
  attributed, dated, and revertible. PRs review parameter changes
  exactly the way they review code.
* **Reproducibility is automatic.** Check out a 2-year-old commit, run
  OpenSCAD, get the *exact* same STL bytes (up to FP determinism).
* **The math is visible.** Anyone reading the file can see that
  `pitch_radius` is `n × m / 2`. The Onshape FeatureScript hides this.
* **You pay for it in tooth fidelity** — the `polygon()` above uses
  straight flanks slanted by the pressure angle, not a true involute
  curve. For visualisation and most prints, it's fine; for tight-mesh
  metrology, you'd want BOSL2's `spur_gear()` or a true-involute
  library.

### Visually side-by-side

The OpenSCAD render at default Customizer values:

Ring + 12 spurs meshing, generated from ring_gear.scad

(That's a link to the generated STL. The render PNG is regenerated
ad-hoc; see [`sandbox/README.md`](sandbox/README.md) for the export
command.)

The Onshape render would look identical *to the eye* — the same module
and tooth counts produce the same external shape, regardless of who
draws the teeth. The differences live in the **process**, not the
geometry.

## Where each tool dominates

### Reach for Onshape when

* You're building **assemblies with motion**. Mates, joints, gear
  relations, drag-to-test interference — these are first-class in
  Onshape and a pain to express in code.
* You need **STEP export** for downstream CAM, CFD, FEA, or other
  classical CAD pipelines. OpenSCAD's mesh outputs can't round-trip
  through STEP.
* The shape is **organic or sculpted** — body work, ergonomic grips,
  swoopy panels. OpenSCAD primitives don't bend that way comfortably.
* Your collaborators **don't code** but do know CAD. Onshape's GUI
  meets them where they are.

### Reach for OpenSCAD when

* The geometry is **math-driven**. Gear teeth, threads, fractals,
  voronoi infill, lattice supports — these are easier as expressions
  than as sketches.
* You want a **parameter sweep**. "Render this part at module 0.4, 0.5,
  0.6, 0.8" is a 1-line shell loop with OpenSCAD; in Onshape it's
  manual configuration management.
* You need **`git`-tracked history of every parameter change**. PRs
  reviewing the move from "12 mm pin" to "10 mm pin" should be a 2-line
  diff, not a screenshot of an Onshape revision tree.
* You're sharing the design **with people who may not have an account**
  on your CAD tool. A `.scad` file works for anyone who runs `apt-get
  install openscad` or downloads the macOS binary.
* The part is **small enough that tooth-perfect involutes don't
  matter** — schematic study models, decorative pieces, prototypes.

## The third option (worth knowing about)

This repo's `src/vault/mechanism.py` does neither — it uses
**build123d + bd_warehouse** (Python on top of the OCCT CAD kernel) to
get *both* a real involute (via OCCT's `Geom_Ellipse` machinery in
`bd_warehouse.gear.SpurGear`) *and* code-trackable parameter source
(via the Python module). The pattern is:

```
src/vault/vault.py          single Python file, every parameter
        ↓
src/vault/mechanism.py      build123d code, imports vault.py
        ↓
docs/vault/assets/parts/*   exported STLs, auto-committed by CI
```

It's the best of both worlds for *this* build — you get true involute
gears that you can `git diff` line-by-line — but the toolchain is
heavy (cadquery-ocp, OpenSCAD for rendering, xvfb in CI). For a
small one-file gear demo, `ring_gear.scad` is faster to read and
faster to iterate on.

The lesson: "Onshape vs OpenSCAD" isn't really binary. If
code-trackability is your hill, the underlying axis is *"is the
source of truth a text file?"* — and OpenSCAD, build123d, and
CadQuery are all on the right side of it.

## See also

* [`onshape-notes.md`](onshape-notes.md) — the canonical Onshape recipe
  for this build, including the ring-gear FeatureScript settings.
* [`sandbox/ring_gear.scad`](sandbox/ring_gear.scad) — the OpenSCAD
  ring-gear demo file.
* [`sandbox/ring_gear.stl`](sandbox/ring_gear.stl) — the printable STL
  generated from it.
* [`sandbox/README.md`](sandbox/README.md) — sandbox usage and
  "graduate a number out of the sandbox" rule.
* `src/vault/mechanism.py` — the build123d production path for the
  same five canonical parts.

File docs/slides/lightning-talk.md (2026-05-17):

---
marp: true
theme: default
class: invert
paginate: true
footer: 'github.com/jmcpheron/pycon2026'
style: |
  section { padding: 40px 60px; }
  h1 { font-size: 1.55em; line-height: 1.2; border-bottom: 2px solid #4a9eff; padding-bottom: 0.2em; margin-bottom: 0.5em; }
  h2 { font-size: 1.3em; line-height: 1.3; }
  ul { font-size: 0.85em; line-height: 1.8; }
  p { font-size: 0.9em; line-height: 1.6; }
  .two-col { display: flex; gap: 1.5em; align-items: center; }
  .two-col > div { flex: 1; }
  .pipeline { font-family: monospace; font-size: 0.82em; line-height: 2.2; background: rgba(255,255,255,0.08); padding: 1em 1.5em; border-radius: 8px; margin: 0.8em 0; }
  .big-quote { font-size: 1.15em; line-height: 1.6; font-style: italic; margin: 0.8em 0; color: #a8d4ff; }
  .qr-wrap { text-align: center; margin-top: 0.5em; }
  .qr-wrap img { max-height: 340px; }
  .soft { color: #999; font-size: 0.8em; }
  footer { font-size: 0.65em; color: #6699cc; font-family: monospace; }
---

<!-- _class: lead -->

## I Made a Gearbox Business Card,<br>Then Made Python Explain It

**Jason McPheron** · PyCon US 2026 · Lightning Talk

<!--
[walk up, hold up the card if you have one]
-->

---

# Hi, I'm Jason.

<div class="two-col">
<div>

- IT work, California community college — mostly student systems
- This talk is about what I do when I should be relaxing: **3D printing little mechanical things and then overthinking them with Python**
- First PyCon — wanted something physical to bring
- Something more interesting than "here's my GitHub"

</div>
<div>

w:360

</div>
</div>

<!--
I work in IT for a community college here in California, mostly around student systems.

But this talk is about one of my hobbies, which is 3D printing little mechanical things and then overthinking them with Python.

This is my first PyCon, and I wanted to make something physical to bring with me.

Partly because 3D printing is fun. Partly because I like making small mechanical objects. And partly because conferences full of strangers can be a little intimidating, so I wanted a conversation starter.

Something I could hand someone that was more interesting than just saying, "Here's my GitHub."
-->

---

# So I made a 3D printed business card.

It has my GitHub project on it.

It also has a **tiny gear mechanism** built into it.

You can spin one gear with your thumb, and the motion moves through the card.

<p class="big-quote">Part business card. Part fidget toy. Part tiny mechanical demo.</p>

At first, that was the whole project. Make a cool little object. Print it. Bring it to PyCon.

<!--
It has my GitHub project on it, but it also has a tiny gear mechanism built into it. You can spin one gear with your thumb, and the motion moves through the card.

It is part business card, part fidget toy, and part tiny mechanical demo.

At first, that was the whole project. Make a cool little object. Print it. Bring it to PyCon. Use it as an excuse to talk to people.
-->

---

# This is where I was happy with the design.

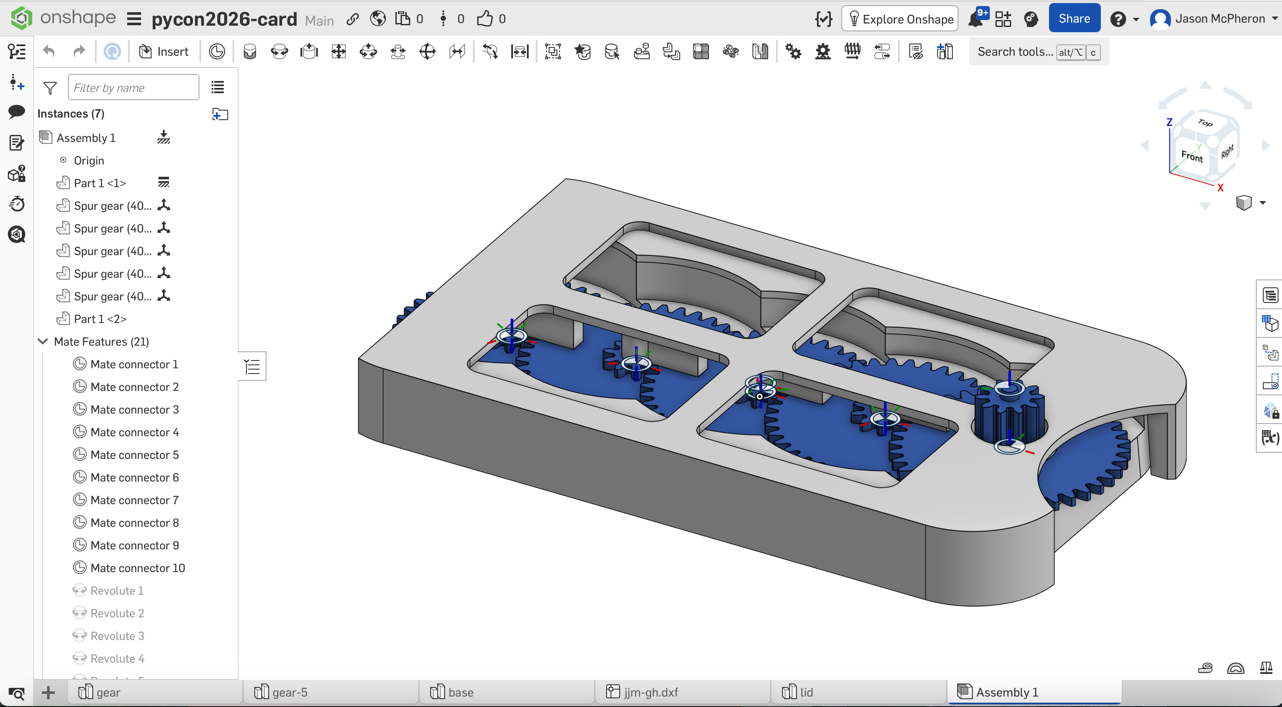
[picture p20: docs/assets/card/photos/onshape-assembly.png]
w:860 center


<!--
The design started in Onshape. Parts, mate connectors, revolute joints so the gears actually spin, even the mesh ratios set up so Onshape knows how they drive each other.

When I got to this point — assembly done, gears moving, lid fitting — I was just happy with it as a 3D design. That felt like the project.

And then I had the thought that probably gets a lot of us into trouble: "This is nice, but how do I force Python into this?"

What could I actually do with it if I exported it and dropped it in a repo? How much Python tooling could I throw at a STEP file and get something interesting out?
-->

---

# The moment the project changed.

<div class="two-col">
<div>

Once I had the card assembled, I exported it as a **STEP file**.

<div class="pipeline">

Onshape assembly &nbsp;→&nbsp; STEP export &nbsp;→&nbsp; GitHub repo

</div>

Now I had **a single file** that represented the assembled physical object.

I could put it in a repo. Version it. Run tools against it. Treat the physical object a little more **like a software project**.

</div>
<div>

w:380

</div>
</div>

<!--
Once I had the card assembled, I exported it as a STEP file.

That was the moment where the project changed for me. Because now I had a single file that represented the assembled physical object. I could put that file in a GitHub repo. I could version it. I could run tools against it. I could start treating the physical object a little more like a software project.
-->

---

# Python around the STEP file.

<div class="two-col">
<div>

Not replacing CAD.

**Tooling around the CAD export.**

- Inspect the file
- Take the assembly apart
- Generate renders
- Make exploded views
- Animate the mechanism
- Keep notes, journals, tolerance experiments

</div>
<div>

w:380

<p class="soft" style="text-align:center;">Yes, the gears clip through each other. <br>If that bothers you — <em>stay tuned.</em></p>

</div>
</div>

<!--
So the Python part became less about replacing CAD, and more about building tooling around the CAD export. The design still happens in Onshape. But once the STEP file is in the repo, Python can start doing useful things around it.

Quick aside on this GIF: yes, the gears are clipping through each other. The render does not know about the mesh ratios, so each gear just spins at the same rate. If that bothers you, hang on — I'll come back to it in a minute.

It can inspect the file. It can help take the assembly apart. It can generate renders. It can make exploded views. It can create animated GIFs that show the mechanism moving.

And it can help keep track of all the little notes around the object: explainers, development journals, tolerance problems, print settings, experiments, and the general story of how the thing changed over time.

That became the real project. Not just the card itself, but the workflow around the card.
-->

---

# A STEP file is not an explanation.

GIFs show *what* the object does. They don't say *why* it's shaped that way.

So the repo also writes **explainer pages** — short prose with diagrams:

<div class="two-col">
<div>

- `gear-ratios.md` — why **32 × 8**, four times, gives 256:1
- `decoding-gears.md` — recovering tooth counts from the STL geometry itself
- `stacking.md` — why the gears sit in a staircase, not a stack
- `printing.md` — what changed when the printer, rudely, obeyed physics

<p class="big-quote">The repo doesn't just show the object.<br>It teaches you what's going on inside it.</p>

</div>
<div>

w:380

</div>
</div>

<!--
A GIF is great, but it only shows what the object does. It does not tell you why it is shaped the way it is. Why those tooth counts. Why those ratios. Why the gears are stacked the way they are.

So alongside the renders, the repo also writes explainer pages. Short prose with diagrams. Why 32 times 8, four times over, gives 256 to 1. How you can recover the tooth counts from the STL geometry itself, after the fact. Why the gears sit in a staircase instead of a clean stack. And what had to change when the printer, very rudely, obeyed physics.

The renders are the gallery. The explainers are the museum placard next to it.
-->

---

# GitHub Actions for physical objects.

The cool part isn't that Python *can* make these. It's that I never run it.

Push a change to the STEP file or the gear constants. A workflow regenerates the GIFs, the explainer pages, the diagrams — and **commits them back to main**.

<div class="pipeline">

`jmcpheron-card.step` &nbsp;changes&nbsp; →&nbsp; <strong>build-card.yml</strong> &nbsp;→&nbsp; new exploded GIF, spin GIF, parts<br>
`src/explainers/card.py` &nbsp;changes&nbsp; →&nbsp; <strong>build-explainers.yml</strong> &nbsp;→&nbsp; new pages + SVGs

</div>

<p class="big-quote">A README can quietly start lying about its object.<br>An auto-commit loop makes that a lot harder.</p>

**Remember the clipping gears?** Fork the repo, fix the spin renderer so each gear turns at its real ratio, push, and the workflow will rebuild the GIF for you. **PR welcome.**

<!--
Here is the part I actually like about using GitHub Actions for this. It is not that Python can make renders and exploded views and diagrams. We already saw that. It is that I almost never run any of it.

When I push a change to the STEP file, a workflow runs in the cloud, regenerates the exploded GIF and the spinning GIF, and commits the new files back to main. When I push a change to the gear constants in card.py, a different workflow rebuilds every explainer page and every SVG, and commits those back too.

And here is the open invitation. Remember the spin GIF where the gears clip through each other? That is a real, small, fixable bug in the renderer. Fork the repo, fix it so each gear turns at its own ratio, push it up, and the workflow will rebuild the GIF on its own. I would genuinely love a PR.

Screenshots get stale. Documentation gets stale. A repo can quietly start lying about the object it contains. An auto-commit loop is my attempt to make that a little harder.
-->

---

# Paws for animals.

<div class="two-col">
<div>

Before this card, I made a 3D printed **cat toy** for my mom.

That project is where I really started enjoying designing separate parts and assembling them.

The only problem:

**I do not have a cat.**

I have a golden retriever named **Bowie**.

</div>
<div>

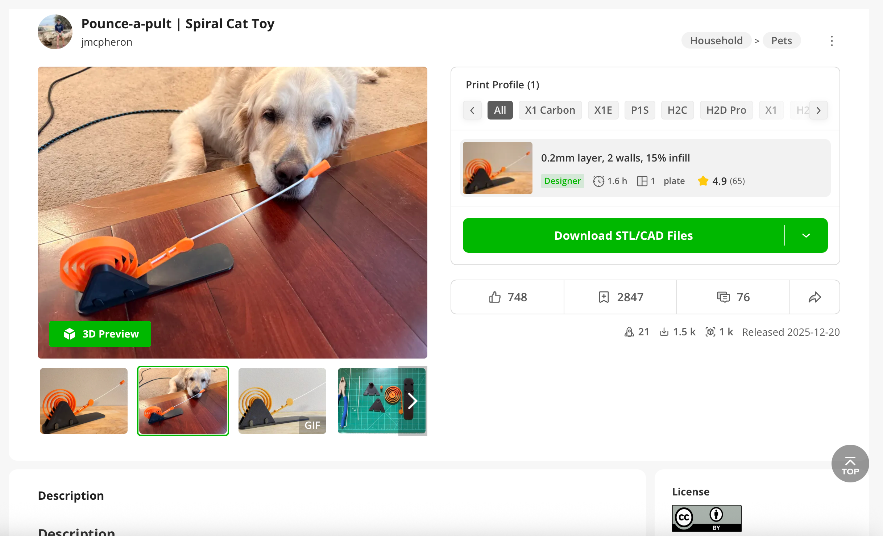
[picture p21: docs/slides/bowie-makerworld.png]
w:400


<p class="soft" style="text-align:center;">The cat toy on MakerWorld. Bowie remains unimpressed.</p>

</div>
</div>

<!--
Before this card, I had another little Onshape project. For Christmas, my mom asked me to design a 3D printed cat toy. That project is where I really started learning how much I enjoy making separate parts in Onshape and then assembling them into a complete object.

There is something extremely satisfying about designing individual pieces, bringing them together, and then seeing the assembled product. It feels like the model becomes real before you ever print it.

The only problem is that I do not have a cat. I have a golden retriever named Bowie.

But that cat toy became useful for the Python side of the project too. It was a different STEP file. A different object. A different assembly. And I could try running it through a similar workflow. That helped me think about whether I was building tools for one very specific business card, or whether I was building a more general little pipeline for understanding 3D projects.
-->

---

# The tiny plastic maker version.

I am sure serious hardware fields have much more mature ways to do this.

Probably industry-standard workflows, best practices, blind spots I have not even learned enough to know I have.

Mine is:

- A 3D printed gearbox business card
- A public Onshape model
- A STEP export
- A Python CLI
- GitHub Actions making pictures

<p class="big-quote">Small enough to be playful.<br>Silly enough to experiment with.<br>Pointing at a serious idea.</p>

<!--
I do not want to oversell this. I am sure that in serious hardware, robotics, aerospace, manufacturing, and embedded systems, there are much more mature ways to do this. There are probably industry-standard workflows, best practices, blind spots I have not even learned enough to know I have, and whole categories of tooling that solve parts of this properly.

My version is the tiny plastic maker version. It is a 3D printed gearbox business card, a public Onshape model, a STEP export, a Python CLI, and GitHub Actions making pictures.

But that is what I like about it. It is small enough to be playful. It is silly enough to experiment with. And it points at a serious idea.
-->

---

# Physical open source borrows from software.

Version control · Generated documentation · Repeatable builds<br>Reviewable changes · Public artifacts

And maybe: **little sanity checks that help the object explain itself.**

---

One more thing: I'm also curious about **licensing**.

For code, we have familiar open-source licenses.

For functional 3D design files — STEP files, things you can print and use — I'm less sure what the right answer is.

Does Creative Commons make sense? Is CC BY-SA the right model? What does *sharing* mean when someone can download the geometry, modify it, print it, remix it?

Making those questions **part of the project** instead of something I figure out later in private.

<!--
Physical open-source projects can borrow some habits from software. Version control. Generated documentation. Repeatable builds. Reviewable changes. Public artifacts. And maybe even little sanity checks that help the object explain itself.

I am also interested in the licensing side of this. For code, we have a pretty familiar set of open-source licenses. For 3D design files, especially functional objects, I am less sure what the right answer is. Does Creative Commons make sense for STEP files? Is CC BY-SA the right model? What does sharing mean when someone can download the geometry, modify it, print it, remix it, or manufacture it?

I do not have a perfect answer to that. But it is one of the reasons I like having the project public. It makes those questions part of the project instead of something I figure out later in private.
-->

---

<!-- _class: lead -->

# Come find me.

Onshape · OpenSCAD · Python · gears · GitHub Actions<br>STEP files · licensing · cat toys · golden retrievers<br>*how much tooling is too much tooling for a tiny plastic business card*

<div class="qr-wrap">

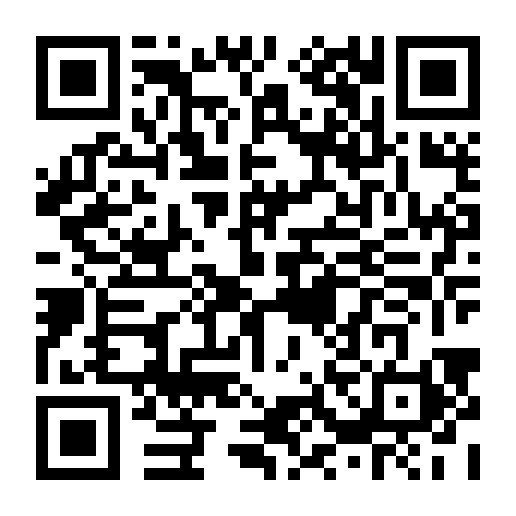
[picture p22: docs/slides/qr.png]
QR code


**github.com/jmcpheron/pycon2026** — I have cards, ask for one.

</div>

<!--
So if you see me around, come find me. I can show you the card. We can talk about Onshape, OpenSCAD, Python, gears, GitHub Actions, STEP files, licensing, cat toys, or how much tooling is too much tooling for a tiny plastic business card.

The repo is jmcpheron slash pycon2026.

Thank you.
-->

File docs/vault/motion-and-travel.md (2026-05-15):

# Motion and travel — what 10° gets you

A 10° rotation doesn't sound like much. At a large
radius, the edge of the mechanism still moves several millimetres — and a
cam slot or linkage can convert some of that motion into useful radial
*pin* travel.

10° cam sweep at r = 70 mm

## arc = r · θ

For an angle θ in radians, a point at radius r sweeps an arc of length
r·θ.

```
arc_length = radius × angle_in_radians
10°  =  0.174533 rad
```

| Radius | Arc travel at 10° |
|---:|---:|
| 20.0 mm | 3.49 mm |
| 40.0 mm | 6.98 mm |
| 60.0 mm |  10.47 mm |
| 70.0 mm |  12.22 mm |
|  100.0 mm |  17.45 mm |

At the default pin radius of 70 mm, a
10° cam rotation sweeps
**12.22 mm** along the pin pitch circle.

## Important caveat — arc travel ≠ pin travel

The pin moves *radially* (in toward the hub or out toward the door edge),
not tangentially. Arc travel is what the cam slot has to cover; the
*pin* travel is whatever component of that arc the slot geometry
projects radially.

The actual radial pin travel depends on the actuator:

* **Cam slot in a rotating plate** — slot angle and slot length set the
  radial component.
* **Rack and pinion** — pin moves in a straight line driven by a
  perpendicular gear; ratio is fixed by gear and rack geometry.
* **Crank linkage** — non-linear; faster near 0°, slower near full
  travel.
* **Lever arm** — multiplies or divides cam motion by the lever ratio.
* **Follower geometry, friction, clearance** — every real mechanism
  gives back some travel to slop and to part finish.

For the default vault parameters (pin travel = 8 mm),
the actuator must convert ~12.2 mm of arc into
8 mm of radial throw. A 8/12.2
≈ 0.65 ratio is well inside what a
short cam slot or a 1:1 lever can handle.

---

*Generated by `src/vault/motion.py`. Cam rotation and pin radius come
from `src/vault/vault.py`.*

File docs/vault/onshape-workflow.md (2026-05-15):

# Onshape workflow — making the SVGs match a real CAD model

The diagrams in this section are generated from Python so they always
match the parameters in [`src/vault/vault.py`](../../src/vault/vault.py).
For the *physical* mechanism, the same parameters drive an Onshape
parametric model. This page documents the convention so the two stay in
sync.

## Variables (Onshape ⟷ vault.py)

Define these as Onshape *variables* in the top-level Part Studio. The
column on the right is the matching constant in `vault.py`.

| Onshape variable | Default | `vault.py` constant |
|---|---:|---|
| `#door_diameter` | 160 mm  | `DOOR_DIAMETER_MM` |
| `#door_thickness` | 8 mm | `DOOR_THICKNESS_MM` |
| `#pin_count` | 12 | `PIN_COUNT` |
| `#pin_diameter` | 4 mm | `PIN_DIAMETER_MM` |
| `#pin_length` | 20 mm | `PIN_LENGTH_MM` |
| `#pin_travel` | 8 mm | `PIN_TRAVEL_MM` |
| `#pin_radius` | 70 mm | `PIN_RADIUS_MM` |
| `#hub_diameter` | 35 mm | `HUB_DIAMETER_MM` |
| `#wheel_diameter` | 45 mm | `WHEEL_DIAMETER_MM` |
| `#cam_rotation` | 10 deg | `CAM_ROTATION_DEG` |
| `#clearance` | 0.3 mm | `CLEARANCE_MM` |
| `#plate_thickness`  | 4 mm | `PLATE_THICKNESS_MM` |

## Suggested phasing

The model is a study, not a product, so it's worth building it in
discardable phases.

### Phase 1 — Static layout
* Circular door slab driven by `#door_diameter` and `#door_thickness`.
* Pin holes via a circular pattern of `#pin_count` instances at
  `#pin_radius`.
* Central hub at `#hub_diameter`.

### Phase 2 — Radial pin motion
* Pins as separate parts.
* Slider mates pinning each pin to a radial axis.
* Animate pins between fully-extended and fully-retracted.

### Phase 3 — One actuator concept
Pick *one* of these to model first. The vault SVG study deliberately
stays neutral about which is "right":

1. **Central cam plate with radial slots** — easiest to visualise, hard
   to tune.
2. **Rack-and-pinion** ring — clean linear motion, more parts.
3. **Rotating ring with angled slots** — compact, follows pin centres.
4. **Linkages from a central wheel to each pin** — most parts, easiest to
   reason about per-pin force.

### Phase 4 — Compare 12 vs. 13

Use Onshape *configurations* (or two parallel Part Studios) to keep both
counts in one document:

```
Vault Door · 12 pins
Vault Door · 13 pins
Vault Door · 24 pins
```

The 13-pin configuration doesn't have to be fully
functional. A static layout study is enough to show the design problems
documented in [the 13-pin problem](thirteen-pin-problem.md).

## Exporting back to this repo

When you have a STEP export you're happy with, drop it next to
`jmcpheron-card.step` and (eventually) wire up a `cardlab`-style
explode pipeline. For now the SVG study and any Onshape screenshots
live side by side under `docs/vault/` — the SVGs answer "what should
the mechanism look like?" and the screenshots answer "does it close?"

---

*Generated by `src/vault/onshape_workflow.py`. Variable defaults come
from `src/vault/vault.py`.*

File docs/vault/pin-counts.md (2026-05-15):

# Pin counts — comparing 6, 8, 12, 13, 24

A circular vault door doesn't care what pin count you pick — they all add
up to 360° eventually. The mechanism around the door cares
a lot.

small-multiples grid of 6, 8, 12, 13, and 24 pin layouts

## The comparison table

| Pin Count | Angle Step | Opposing Pairs? | Clean Quadrants? | Notes |
|---:|---:|:---:|:---:|---|
| 6  | 60.000° | yes | no  | hex-like; only 2- and 3-fold symmetry |
| 8  | 45.000° | yes | yes | clean diagonal symmetry |
| 12 | 30.000° | yes | yes | clock-like, very friendly |
| 13 | 27.692° | **no** | **no** | possible, but awkward |
| 24 | 15.000° | yes | yes | very flexible and divisible |

## Divisors at a glance

divisor chips for 12, 13, 24

Composite pin counts give the mechanism designer many ways to divide,
mirror, and repeat a design. Prime pin counts (red row) give two: 1, and
the count itself.

That's not a bug in primes — it's the *definition* of prime. It just means
a 13-pin mechanism either uses 13
identical individually-routed actuators, or one custom shape. There's no
elegant middle ground.

## Picking a pin count

If your design doesn't have a strong reason to pick a prime, pick a
composite. 12 is the obvious starting point — it inherits all
the readability of a clock face.

If you want twice the resolution but the same friendliness, jump to
24.

If you want a conversation piece, pick 13 on purpose and
[lean into the constraint](thirteen-pin-problem.md).

## A note from watching Adam Savage's mini vault build

> *Watching Adam Savage machine the pins for his mini vault door build, I
> kept staring at one detail and not getting it: each pin had a section
> of straight gear teeth cut into it, and the **back** of that section —
> the spine, opposite the teeth — was machined surprisingly thin. Way
> more material removed than you'd expect for weight savings. Then I saw
> the parts assembled inside the door and it clicked. He didn't choose
> that shape; the pin count chose it for him.*

The build style is a **rack-and-pinion central drive**: each pin carries
a section of straight gear teeth (a *rack*) along one face, and a single
central pinion gear at the hub meshes with **all N racks at once**. Turn
the handle, the pinion rotates, every pin translates radially in unison.

the same pinion driving N=6, 12, 24 racks — each rack body shrinks as N grows

For all N racks to engage the same pinion, they have to share the
perimeter of the pinion's pitch circle. That perimeter is `2π · r`, and
the N rack bodies — each with some tangential thickness `t` — must fit
side-by-side around it without colliding:

```
N · (t + clearance)  ≤  2π · r_pinion
```

Re-arranged, the upper bound on each rack body's tangential thickness is

```
t  ≤  (2π · r_pinion / N)  −  clearance
```

So the central pinion's circumference is a **budget** the N racks split
between them. Halve the pinion radius, halve the budget. Double the pin
count, halve the budget. There is nowhere else for the material to go,
so you machine the spine of every rack thinner until it fits its slice.
The teeth themselves have to stay full-profile to mesh — *the spine is
the only place material can come from.*

For this study's parameters — a central pinion of radius **12 mm**
driving **12** racks with 0.3 mm clearance —
each rack body gets at most **5.98 mm**
of tangential thickness:

| Pin count N | Rack body budget `t ≤ 2π·12/N − 0.3` |
|---:|---:|
| 6  | 12.27 mm |
| 8  | 9.12 mm |
| 12 | 5.98 mm |
| 13 | 5.50 mm |
| 24 | 2.84 mm |

That is what **"design tax"** looks like in metal. Pin count doesn't just
choose where each pin lives on the door — it dictates how much *meat*
every rack body is allowed to keep.

(Adam Savage's video is a great public reference for the build style;
the specific mechanism geometry is not reproduced here. This is a
fan-made educational study, not affiliated with Tested.)

---

*Generated by `src/vault/pin_counts.py`. Pin counts and the central
pinion radius come from `src/vault/vault.py`.*

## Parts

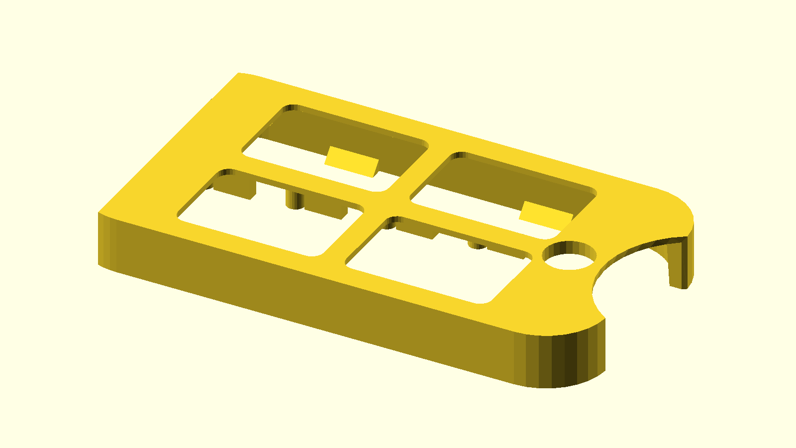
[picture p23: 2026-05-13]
docs/assets/card/parts/Part_1_1.png

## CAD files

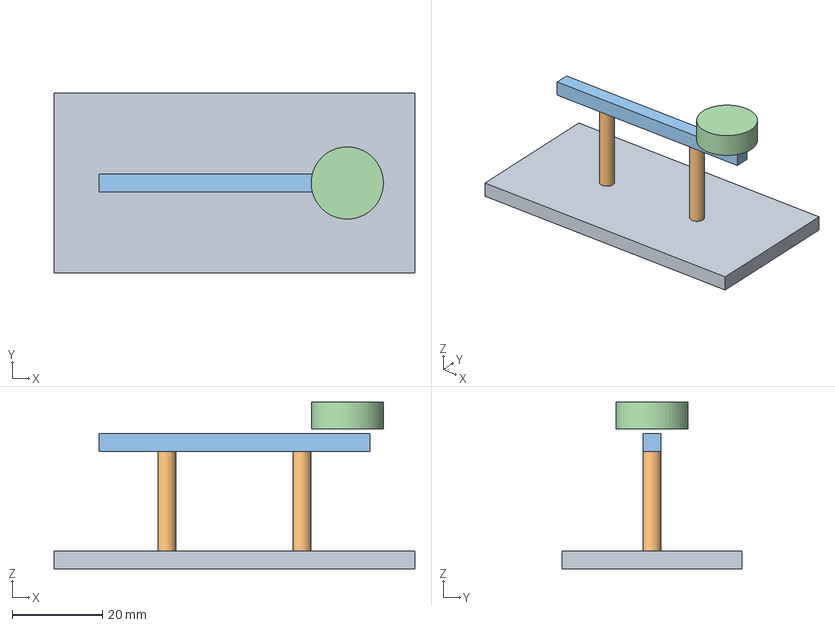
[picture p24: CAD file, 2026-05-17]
step-demo/parts/assembled.step
80.0 x 40.0 x 37.0 mm
base
pin-left
pin-right
arm
cup

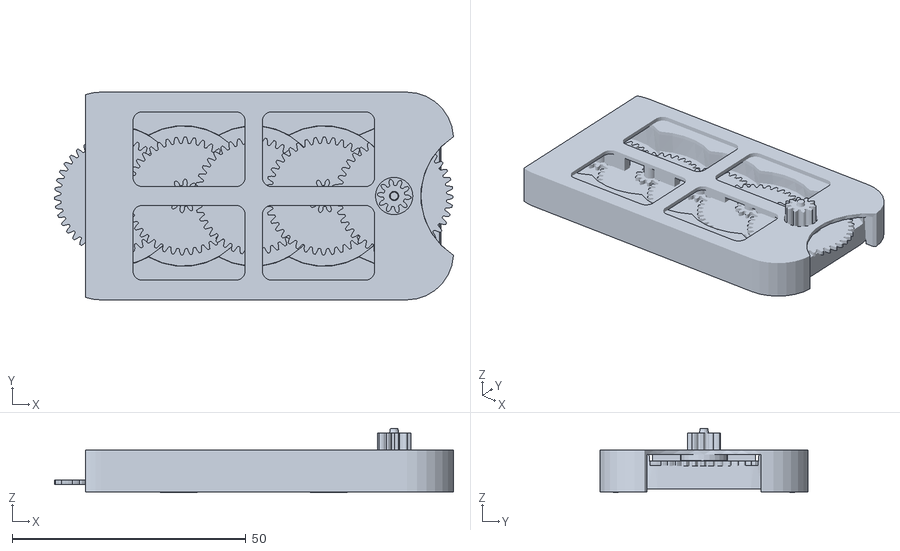
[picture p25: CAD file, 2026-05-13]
docs/assets/card/jmcpheron-card.stl
85.3 x 44.4 x 13.7

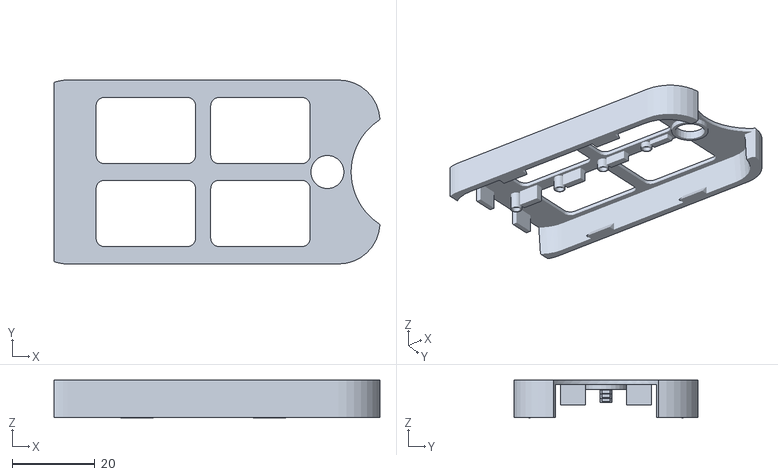
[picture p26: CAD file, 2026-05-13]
docs/assets/card/parts/Part_1_1.stl
78.7 x 44.4 x 9.10

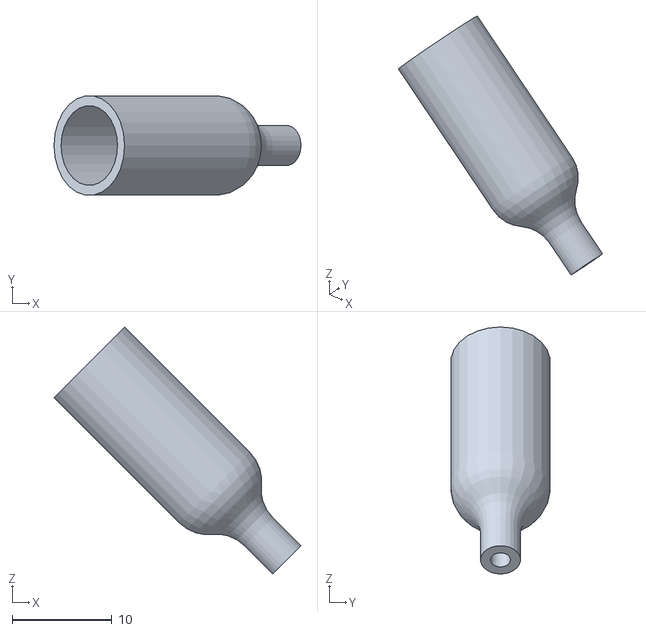
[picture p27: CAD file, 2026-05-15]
docs/pounce-a-pult/assets/parts/Part_1.stl
24.7 x 9.93 x 24.7

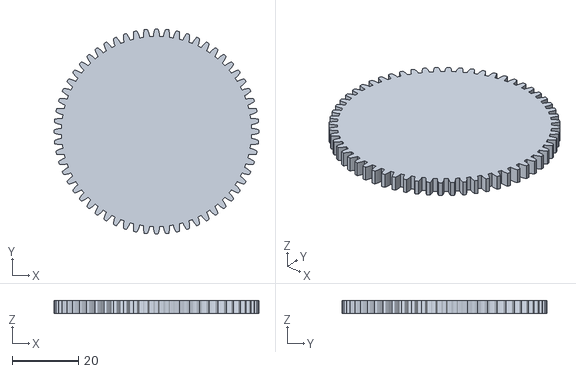
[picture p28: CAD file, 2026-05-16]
docs/vault/assets/parts/ring-gear.stl
62.0 x 62.0 x 4.00

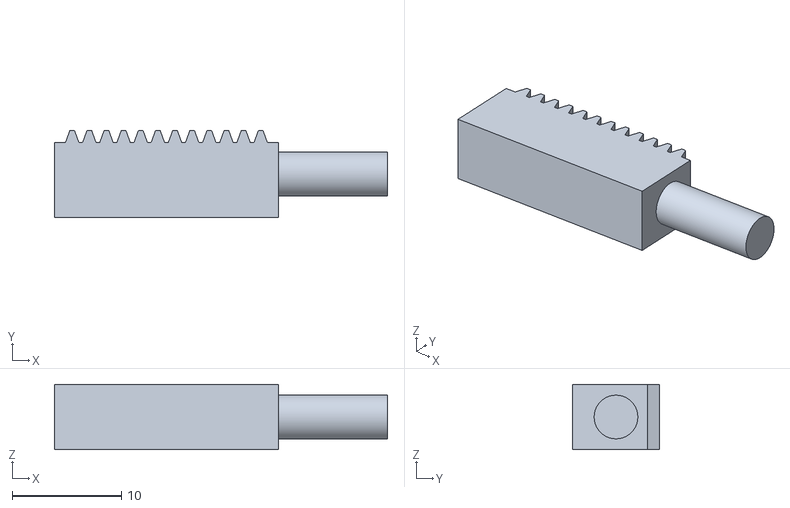
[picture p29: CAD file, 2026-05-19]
docs/vault/sandbox/rack.stl
30.5 x 8.00 x 6.00

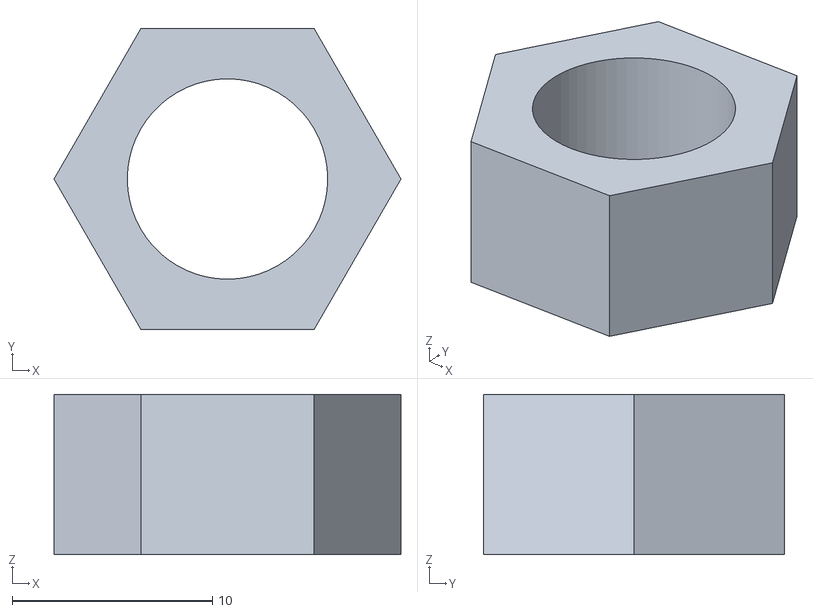
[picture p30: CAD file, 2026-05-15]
output/run-20260507T053409Z/final.stl
17.3 x 15.0 x 8.00

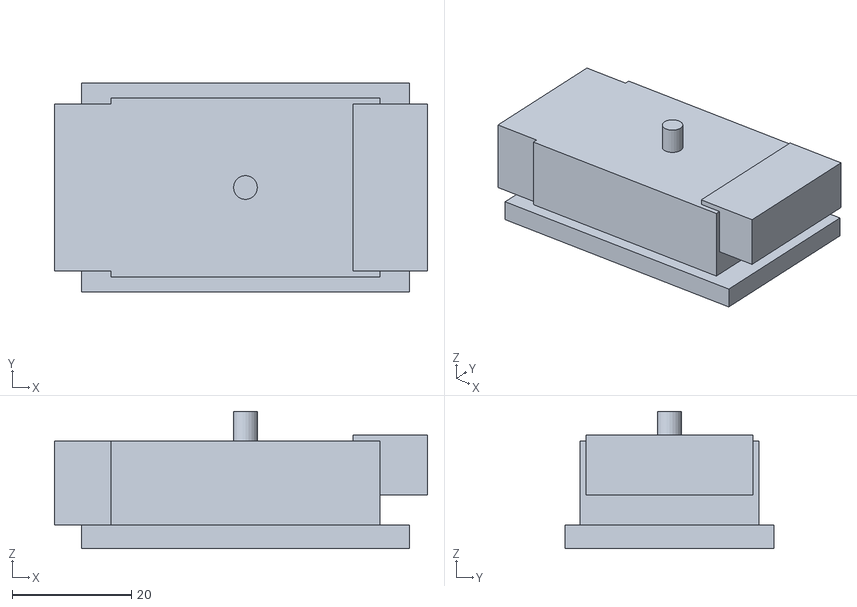
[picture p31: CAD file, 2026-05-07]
output/run-20260507T072032Z/final.stl
62.5 x 35.0 x 23.0

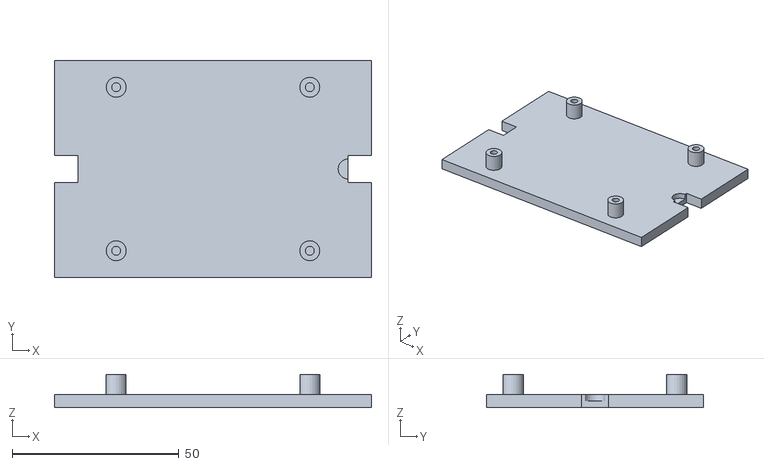
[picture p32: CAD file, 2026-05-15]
output/run-20260507T080310Z/final.stl
95.0 x 65.0 x 10.0

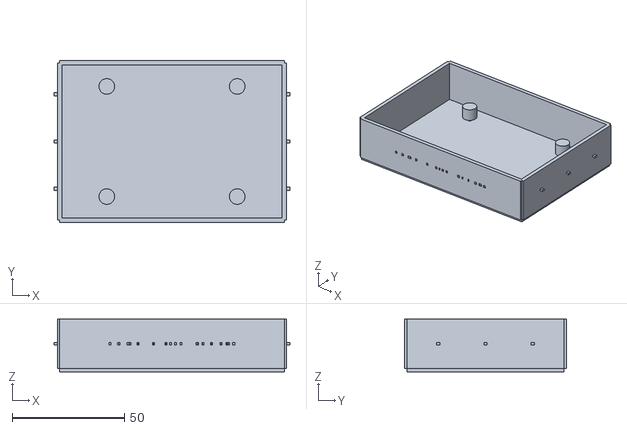
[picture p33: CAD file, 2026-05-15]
output/run-20260507T144420Z/final.stl
105.0 x 72.0 x 23.5

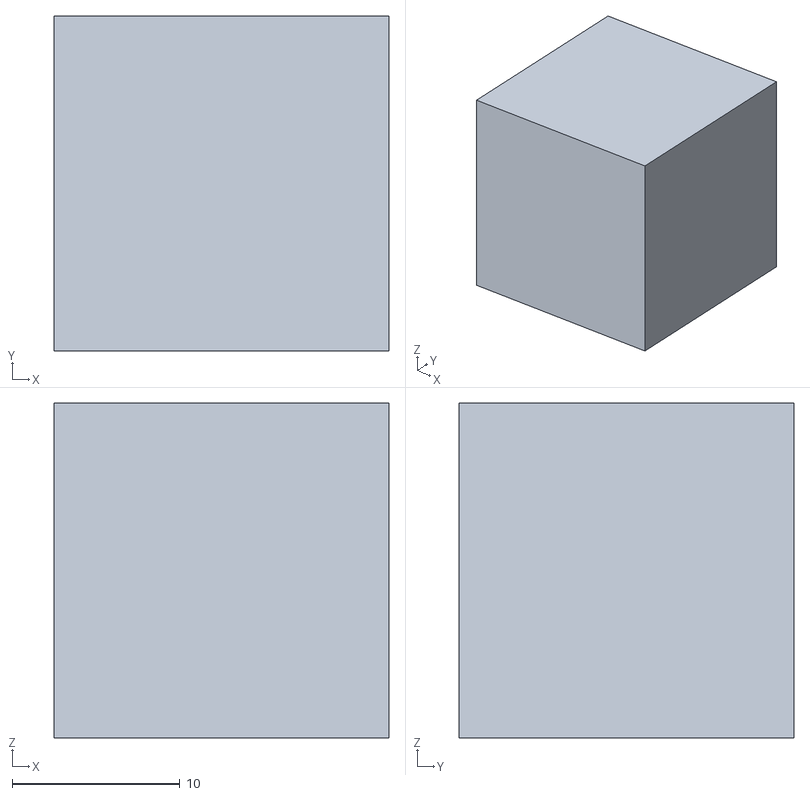
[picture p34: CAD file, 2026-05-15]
output/smoketest/cube.stl
20.0 x 20.0 x 20.0

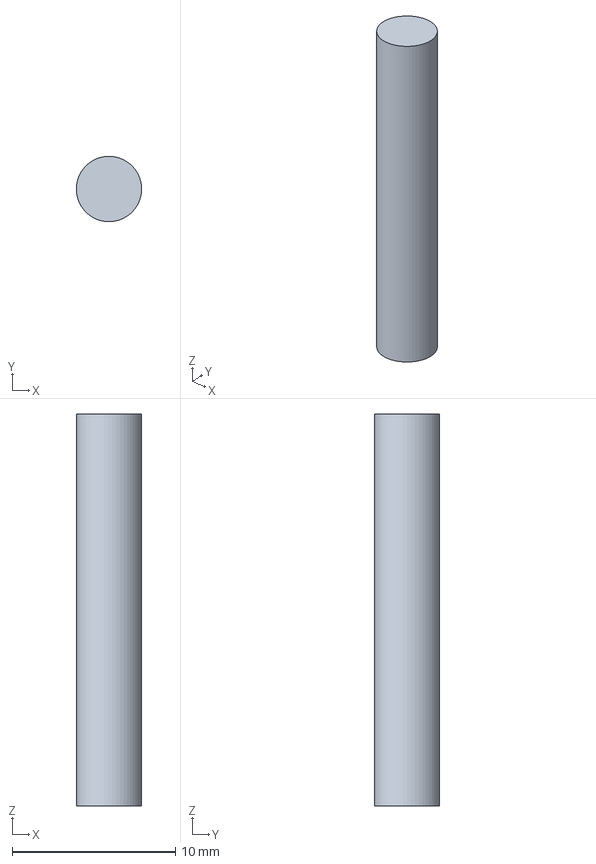
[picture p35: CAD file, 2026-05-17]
step-demo/parts/pin.step
4.00 x 4.00 x 24.0 mm

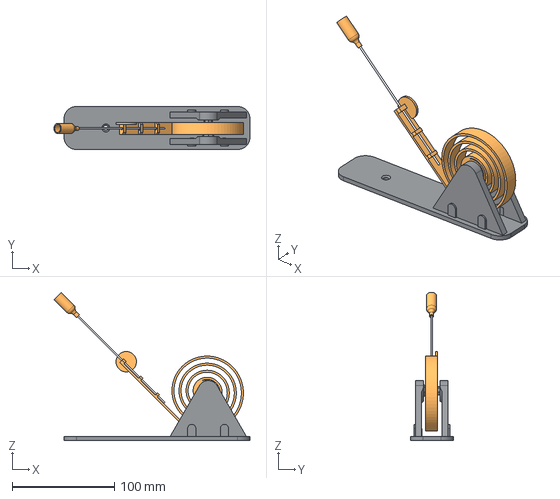
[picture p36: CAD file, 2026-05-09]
step-demo/pounce-a-pult.step
191.8 x 42.0 x 145.2 mm

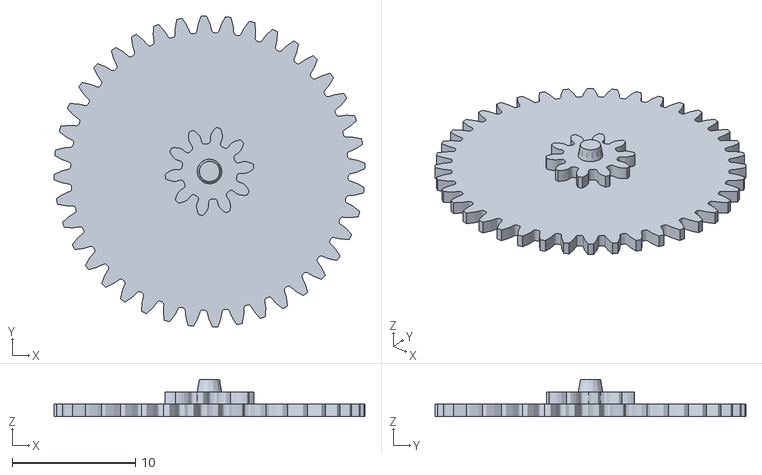
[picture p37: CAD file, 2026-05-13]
docs/assets/card/parts/Spur_gear_40_teeth.stl
25.2 x 25.2 x 3.00

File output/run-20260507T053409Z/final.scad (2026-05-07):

$fn = 60;

module hex_nut_m10() {
    // M10 hexagonal nut dimensions
    // Across flats (width): 15mm
    // Height: 8mm
    // Hole diameter: 10mm
    
    difference() {
        // Outer hexagon
        cylinder(h = 8, r = 15/2/cos(30), $fn = 6);
        
        // Inner hole
        cylinder(h = 8, r = 5, $fn = 60);
    }
}

hex_nut_m10();

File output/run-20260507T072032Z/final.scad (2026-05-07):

$fn = 24;

module tolerance_hole() {
    translate([0, 0, -1])
        cylinder(h = 22, r = 2);
}

module anvil() {
    // Base - wide, flat platform
    cube([55, 35, 4], center = true);
    
    // Main body block
    translate([0, 0, 9])
        cube([45, 30, 14], center = true);
    
    // Horn - tapered wedge approximation using scaled cube
    translate([28, 0, 12]) {
        difference() {
            cube([20, 28, 10], center = true);
            // Taper by removing corner material
            translate([10, 0, 0])
                cube([15, 32, 12], center = true);
        }
    }
    
    // Heel block on opposite side
    translate([-26, 0, 9])
        cube([12, 28, 14], center = true);
    
    // Tolerance hole through main body
    tolerance_hole();
}

module text_emboss() {
    // Simple recessed rectangles to approximate "PYCON"
    // P
    translate([-18, 16, 19.5]) {
        cube([3, 6, 0.8]);
        translate([0, -3, 0]) cube([6, 3, 0.8]);
        translate([0, 0, 0]) cube([6, 2, 0.8]);
    }
    
    // Y
    translate([-8, 16, 19.5]) {
        cube([3, 3, 0.8]);
        translate([3, 0, 0]) cube([3, 3, 0.8]);
        translate([1.5, -3, 0]) cube([3, 3, 0.8]);
    }
    
    // C
    translate([4, 16, 19.5]) {
        cube([6, 2, 0.8]);
        cube([2, 6, 0.8]);
        translate([4, 4, 0]) cube([2, 2, 0.8]);
    }
    
    // O
    translate([16, 16, 19.5]) {
        cube([6, 2, 0.8]);
        cube([2, 6, 0.8]);
        translate([4, 0, 0]) cube([2, 6, 0.8]);
        translate([0, 4, 0]) cube([6, 2, 0.8]);
    }
    
    // N
    translate([26, 16, 19.5]) {
        cube([2, 6, 0.8]);
        translate([4, 0, 0]) cube([2, 6, 0.8]);
        cube([6, 2, 0.8]);
    }
}

difference() {
    anvil();
    text_emboss();
}

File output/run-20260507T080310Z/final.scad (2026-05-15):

$fn = 24;

module base_plate() {
    cube([95, 65, 4], center=true);
}

module standoff(height) {
    cylinder(h=height, r=3, center=false);
}

module clearance_hole() {
    cylinder(h=10, r=1.35, center=false);
}

module keyhole_slot() {
    // Keyhole slot: 8mm wide x 14mm long
    // Composed of: rectangular slot (8x14mm) + hanging hole (6mm dia)
    union() {
        // Main slot opening: 8mm wide x 14mm long
        cube([8, 14, 6], center=true);
        
        // Hanging hole at top of slot: 6mm diameter cylinder
        translate([0, 7, 3]) 
            cylinder(h=6, r=3, center=true);
    }
}

// Calculate mounting hole positions (centered on 58mm x 49mm pattern)
hole_x_offset = 58 / 2;
hole_y_offset = 49 / 2;

difference() {
    union() {
        // Base plate positioned at z=0 to z=4
        translate([0, 0, 2]) base_plate();
        
        // Four standoffs extending from z=4 to z=10
        translate([-hole_x_offset, -hole_y_offset, 4]) 
            standoff(6);
        
        translate([hole_x_offset, -hole_y_offset, 4]) 
            standoff(6);
        
        translate([-hole_x_offset, hole_y_offset, 4]) 
            standoff(6);
        
        translate([hole_x_offset, hole_y_offset, 4]) 
            standoff(6);
    }
    
    // Four clearance holes (M2.5 = 2.7mm) drilled through standoffs and base
    // Positioned at z=4 to cleanly drill through the 6mm standoffs
    translate([-hole_x_offset, -hole_y_offset, 4]) 
        clearance_hole();
    
    translate([hole_x_offset, -hole_y_offset, 4]) 
        clearance_hole();
    
    translate([-hole_x_offset, hole_y_offset, 4]) 
        clearance_hole();
    
    translate([hole_x_offset, hole_y_offset, 4]) 
        clearance_hole();
    
    // Two keyhole slots on short edges (65mm side)
    // Left edge keyhole
    translate([-47.5, 0, 2]) 
        rotate([0, 0, 90])
        keyhole_slot();
    
    // Right edge keyhole
    translate([47.5, 0, 2]) 
        rotate([0, 0, 90])
        keyhole_slot();
}

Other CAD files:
jmcpheron-card.step
docs/pounce-a-pult/assets/parts/Part_1_3.stl
docs/vault/assets/parts/rack.stl
docs/vault/sandbox/ring_gear.stl
output/run-20260507T144420Z/final.scad
docs/assets/card/parts/Part_1.stl
docs/assets/card/parts/Spur_gear_40_teeth_1.stl
docs/assets/card/parts/Spur_gear_40_teeth_2.stl
docs/assets/card/parts/Spur_gear_40_teeth_3.stl
docs/assets/card/parts/Spur_gear_40_teeth_4.stl
docs/pounce-a-pult/assets/parts/Part_1_1.stl
docs/pounce-a-pult/assets/parts/Part_1_2.stl
docs/pounce-a-pult/assets/parts/Part_1_4.stl
docs/pounce-a-pult/assets/parts/Part_1_5.stl
docs/vault/assets/parts/door-rim.stl
docs/vault/assets/parts/pin.stl
docs/vault/assets/parts/spur-gear.stl
docs/vault/sandbox/assembly.scad
docs/vault/sandbox/door.scad
docs/vault/sandbox/rack.scad
docs/vault/sandbox/ring_gear.scad
output/experiments/multi-gen-2026-05-07-anvil/anthropic_claude-haiku-4.5.scad
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

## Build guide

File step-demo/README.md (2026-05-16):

# step-demo — STEP files, the Python way

This directory exercises [`cardlab`](../src/cardlab), the sibling tool to `badgeforge` that handles STEP files (ISO 10303 — the heavyweight CAD interchange format that GitHub's web UI can't natively render).

The story is in three parts.

## 1 · Inspect a real STEP file

`pounce-a-pult.step` is an Onshape AP242 export of the *Pounce-a-Pult spiral cat toy* — flat spiral spring on a base plate, another of my designs, published under [CC BY 4.0](https://creativecommons.org/licenses/by/4.0/). The parametric source lives in a [public Onshape document](https://cad.onshape.com/documents/01739d2a63dc91eaf28c2c62/w/a7c671d651186a5272cc789f/e/fdb2542c5ccec8040d59912a), with the printable bundle published on [MakerWorld](https://makerworld.com/en/models/2138778-pounce-a-pult-spiral-cat-toy#profileId-2316710). The toy's own page (renders, assembly, printing notes, license details) lives at [`docs/pounce-a-pult/`](../docs/pounce-a-pult/README.md). Even before we tessellate anything, Python can read its product structure:

```bash
uv run cardlab inspect step-demo/pounce-a-pult.step
```

You get the schema, originating system, units, bounding box, triangle count at the default tessellation, and the assembly tree with each part's position. CI captures this as [`docs/pounce-a-pult/inspect.txt`](../docs/pounce-a-pult/inspect.txt) on every push.

## 2 · Convert it to formats GitHub *can* render

```bash
uv run cardlab build --in step-demo/pounce-a-pult.step --out step-demo/pounce-a-pult.stl
uv run cardlab build --in step-demo/pounce-a-pult.step --out step-demo/pounce-a-pult.glb
```

GitHub renders `.stl` natively — click [`pounce-a-pult.stl`](pounce-a-pult.stl) in the file tree and you get a 3D viewer with pan/zoom/rotate. The `.glb` is a glTF binary suitable for embedding in three.js viewers, model-viewer, etc.

For the README hero images:

```bash
xvfb-run -a uv run cardlab render \
  --in step-demo/pounce-a-pult.step \
  --angle iso \
  --out docs/pounce-a-pult/assets/iso.png
```

`cardlab render` is small and a little clever: it tessellates to STL, writes a one-line `.scad` shim that `import()`s the STL, then hands the whole thing to OpenSCAD — reusing the exact xvfb + Cornfield pipeline `badgeforge` already proved out. So the STEP renders share the badge's visual style for free.

## 3 · Compose multiple STEP parts into one assembly

Sometimes the assembly is one file; sometimes it's a bill of materials. `cardlab assemble` reads a TOML manifest and stitches parts together:

```bash
uv run python step-demo/parts/generate.py        # one-shot — writes base/arm/cup/pin .step
uv run cardlab assemble \
  --manifest step-demo/parts/assembly.toml \
  --out step-demo/parts/assembled.step \
  --also-stl --also-png
```

[`parts/assembly.toml`](parts/assembly.toml) is a flat list of `[[part]]` blocks with relative `path`, optional `name`, and optional `xyz` / `rpy` locations. Edit the numbers, re-run, see the result.

## Pipeline diagram

```
  *.step  ──►  cardlab inspect ──►  tree.txt
          ──►  cardlab build   ──►  *.stl  (GitHub viewer)
          ──►  cardlab build   ──►  *.glb  (web viewers)
          ──►  cardlab render  ──►  *.png  (hero images)
  *.toml  ──►  cardlab assemble ──► assembled.step (+ .stl, +.png)
```

CI runs all of the above on every push that touches `step-demo/**` or `src/cardlab/**`, then auto-commits the results. Configured in [`.github/workflows/build-step.yml`](../.github/workflows/build-step.yml).

## Why these tool choices

- **`build123d`** for STEP I/O — actively maintained, clean `Compound` / `Location` API, sits on the same OpenCascade engine Onshape uses on export so the round-trip is BREP-lossless rather than mesh-lossy.
- **OpenSCAD** for PNG renders — already proven on this repo's CI; sidesteps the EGL / pyrender headless rabbit hole.
- **`trimesh`** is in the dep list as an optional bridge to other mesh formats; `cardlab build` itself uses build123d's native `export_gltf`.

The OpenCascade Python wheel (`cadquery-ocp`) is ~180 MB, so it's gated behind `uv sync --extra step` rather than being a default dependency — most contributors only working on the badge don't need it.

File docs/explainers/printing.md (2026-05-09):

# 3D-printing considerations — designing for the printer, not just the function

> *[your voice here] this is the section where you note that the engineering of how it works is only half the problem; the other half is making it actually come off the build plate intact.*

## Print orientation: big disc on the bed

print orientation showing layers stacking from the build plate

The compound gear has a single sane orientation: **big disc flat on the build plate, hub up, pinion on top**. Two reasons:

1. **Tooth resolution.** The 40-tooth big gear's teeth are 0.6 mm tall radially. Printed flat on the bed, that detail lives in the *layer plane*, where the printer's resolution is set by extrusion width (~0.4 mm) — sharp. Printed standing up, that detail would be sliced into 6 stacked layers per tooth and lose the curve to staircase artifacts.
2. **Self-supporting tower.** The hub above the big gear is a vertical cylinder — cleanest possible shape for FDM. No bridges, no overhangs, no support material.

At 0.1 mm layer height, the 1 mm big gear is 10 layers; the 1 mm pinion is also 10 layers. Plenty of structural mass.

## The hub-to-pinion overhang

This is the one place the simple "big-disc-on-bed" orientation fights you. The hub is 3 mm wide; the pinion above it is 7.2 mm wide. That's 2.1 mm of radial overhang per side, with no support beneath.

flat overhang fails; 45° chamfer succeeds

A flat overhang of 2.1 mm sags or curls — FDM filament can't span empty space sideways without something underneath. Two options:

- **Add a 45° chamfer** between the hub and the pinion. Each layer of the chamfer is supported by the layer below, all the way up to the full pinion radius. No support material, no print failure.
- **Use a tree-support generator** during slicing, and pay for support removal time afterward.

The chamfer wins. It's a couple of seconds in CAD, doesn't cost any height (the chamfer is "above" the hub but the pinion sits on top of it, so total height is unchanged), and the result is a printer-friendly self-supporting form.

## Why the post is its own part

monolithic gear+post fails; separate parts both work

The post — the axle the gear spins on — needs to extend *below* the gear to seat into the card body. If you tried to print the gear and post as one part, you'd be asking the printer to either start the post hovering in mid-air below the build plate (impossible) or flip the gear upside-down so the post stub points up (which puts the 0.6 mm-tall teeth standing up — the bad orientation).

Two separate parts solves it cleanly:

- **Gear** prints big-down, hub up, pinion on top. Best orientation for tooth resolution.
- **Post** prints lying flat on the bed. Just a 2 mm × ~9 mm cylinder — trivial.

After printing, posts press-fit into pre-drilled holes in the card body (or print into a card with the holes built in). Gears slide down onto the posts, optionally with a tiny printed cap on top to keep them from lifting off.

## A practical settings table

| Setting | Value | Rationale |
|---|---|---|
| Layer height | 0.1 mm | 6 layers per 0.6 mm tooth height — clean detail |
| Walls | 4–5 perimeters | Tiny parts; you want them solid |
| Infill | 50–100 % | Doesn't matter for time, helps strength |
| Supports | none | The chamfer eliminates the only overhang |
| Material | PLA or PETG | PLA is fine for a non-loadbearing demo; PETG wears better |
| Brim | 5 mm if needed | The pinion's small footprint can pop loose |

## Putting it together

Printing four standard parts and one tall-hub variant takes about 25 minutes in PLA at 0.1 mm layers, plus the time to print the card body and posts. Total assembly is press-fit with no glue: posts into card, gears onto posts, optional pointer onto the output gear's pinion, done.

[← Back to gear ratios](gear-ratios.md) · [back to index](index.md)

---

*Generated by [`src/explainers/printing.py`](../../src/explainers/printing.py). Edit the source, not this file.*

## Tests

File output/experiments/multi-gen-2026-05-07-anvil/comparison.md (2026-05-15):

# multi-generator comparison

- prompt (first 200 chars): `Create a small 3D-printable OpenSCAD anvil with "PYCON 2026" embossed on the side.

Build:
- A flat base
- A central body block on top of the base
- A tapered horn extending from one side
- A short he...`

| model | outcome | gen (s) | render (s) |
|---|---|---|---|
| `google/gemma-4-31b-it` | OK | 14.59 | 3.29 |

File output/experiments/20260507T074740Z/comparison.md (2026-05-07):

# multi-critic comparison

- render: `docs/devlog/assets/2026-05-07-scadvil-anvil/render.png`
- prompt (first 200 chars): `Create a 3D-printable OpenSCAD calibration anvil.

Design constraints to keep render time low:
- Use only cube(), cylinder(), and sphere() primitives.
- Do NOT use minkowski() or hull() — they are too...`
- augment: (none — SYSTEM_CRITIQUE verbatim)

| model | done | score | blocking | non-blocking | source | t(s) |
|---|---|---|---|---|---|---|
| `google/gemini-2.5-flash` | False | 4 | 3 | 0 | tool_call | 2.5 |
| `anthropic/claude-haiku-4.5` | False | 7 | 3 | 3 | tool_call | 6.37 |
| `qwen/qwen3-vl-8b-instruct` | False | 4 | 5 | 5 | tool_call | 3.35 |
| `openai/gpt-5-mini` | — | — | — | — | unparsed | 29.8 |
| `meta-llama/llama-4-scout` | — | — | — | — | error | 0.72 |
| `google/gemma-4-31b-it` | False | 4 | 1 | 1 | tool_call | 28.22 |

## blocking issues by model

### `google/gemini-2.5-flash` — score 4
_summary:_ The model currently lacks a tapered horn and legible text, and the tolerance hole is missing. These critical issues prevent it from matching the request.

- **blocking:** The horn is not tapered as requested; it is a rectangular block.
- **blocking:** The text is not legible as "PYCON"; it is a collection of cuboids and has been placed on the wrong face of the object (it is on the larger face instead of the side).
- **blocking:** The tolerance hole is not visible or properly placed; it should be drilled through the body in a visible location on the top face.

### `anthropic/claude-haiku-4.5` — score 7
_summary:_ The model credibly depicts a calibration anvil with all major requested components (base, body, horn, heel, tolerance hole, and embossed text), though some details need refinement for print accuracy.

- **blocking:** Horn taper is not visually tapered—it appears as a blocky rectangular mass because the difference operation removes corner material but doesn't create a smooth wedge shape; for a calibration tool this defeats the typical anvil horn form.
- **blocking:** Embossed text positioning is off-target and appears distorted; the letters should sit flat on the top face of the body but their placement puts them partially out of bounds relative to the body geometry.
- **blocking:** Tolerance hole appears to be drilled from bottom (z = -1) through top (+11), but the hole should be drilled cleanly through the center of the main body block (which sits at z = 2 to z = 16); recalculate the hole height and z-position.
- nonblocking: Horn shape is geometrically functional but crude; a true wedge taper would improve aesthetics and print quality.
- nonblocking: Text emboss uses stacked cubes which produce a pixelated appearance rather than smooth letter forms, but it is still legible as 'PYCON'.
- nonblocking: Base cube dimensions (55 × 35 × 4) are reasonable but could be verified to ensure sufficient contact area for FDM printing stability.

### `qwen/qwen3-vl-8b-instruct` — score 4
_summary:_ The model is not a credible calibration anvil — the horn, heel, text, and hole are all incorrectly implemented.

- **blocking:** The horn is not a tapered wedge as requested — it's a cube with a corner removed, which looks more like a truncated pyramid than a smooth taper.
- **blocking:** The heel block is misaligned and too small — it's placed at [-26, 0, 9] but should be on the opposite side of the horn, and its dimensions are too small for a functional heel.
- **blocking:** The embossed text "PYCON" is not recessed into the side face — it's rendered as a separate module subtracted from the anvil, but the positioning and shape don't match the request for embossed text.
- **blocking:** The tolerance hole is not centered vertically through the body — it's offset by the translate([0, 0, -1]) in the tolerance_hole() module, which may not align with the body's center.
- **blocking:** The base is too wide (55x35) and the body is too tall (14) — the request asks for ~50 mm wide, and the proportions don't match a typical calibration anvil.
- nonblocking: The model uses only cube(), cylinder(), and sphere() primitives as requested.
- nonblocking: The model avoids minkowski() and hull() as requested.
- nonblocking: $fn = 24 is set globally.
- nonblocking: The model has sharp edges as requested.
- nonblocking: The model is simple and printable on FDM at 0.2 mm layers.

### `google/gemma-4-31b-it` — score 4
_summary:_ The model has the general shape of an anvil, but the requested tolerance hole is a protruding cylinder instead of a hole.

- **blocking:** The 4mm tolerance hole is rendered as a positive cylinder sticking out of the top instead of a hole drilled through the body.
- nonblocking: The 'PYCON' text is not visible in the render because it is placed on the top surface rather than a side face, or it is too shallow/small to be seen from this angle.

### `meta-llama/llama-4-scout` — ERROR
```
HTTP 429: {"error":{"message":"Provider returned error","code":429,"metadata":{"raw":"meta-llama/llama-4-scout is temporarily rate-limited upstream. Please retry shortly, or add your own key to accumulate your 
```

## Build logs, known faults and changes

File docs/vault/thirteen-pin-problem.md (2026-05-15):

# The 13-pin vault problem

animated comparison — 12, 13, 24 pins all locking and unlocking on the same loop

> *Three doors, one cycle. Every pin in every panel locks and unlocks.
> The middle panel's darker-brass pin is the one with **no mirror twin**
> across the diameter — the dashed marker shows where its partner would
> have to sit. The mechanism still works; it just can't share parts the
> way 12 and 24 can.*

A 13-pin vault door **works**. In CAD, placing
13 equally spaced pins around a circle is one circular
pattern. Mechanically, a central pinion driving 13 racks
locks and unlocks the door exactly the way 12 or
24 racks would. The geometry doesn't refuse the
prime.

What 13 refuses is a **set of design shortcuts** —
optimizations that composite pin counts get for free and prime pin
counts have to pay full price for. That's the real story, and it's
worth being precise about it.

## Tricks the geometry allows

For any N (prime or composite), all of these work:

* a single central pinion driving N racks — Adam Savage's mini-vault
  pattern, see [pin-counts.md](pin-counts.md)
* a cam plate with N follower slots
* a worm-gear ring driving each pin off its own pinion
* N independent levers, each with its own cam profile

For composite N (like 12 or 24), these
*also* work:

* **one shared rack driving two opposite pins** — needs an exact pair
  across the diameter, so N must be even
* **a mirror-image sub-assembly used N/2 times** — needs bilateral
  symmetry through pin centres, so N must be even
* **cyclic sub-symmetry actuation** — lock half, then the other half;
  lock thirds; lock quarters. Needs a non-trivial subgroup of C_N,
  which exists exactly when N has divisors other than 1 and N

For 13, none of those three are available. 13
is prime — its only divisors are 1, 13.

## The math, fully

13 pins can be spaced exactly evenly:

```
360 / 13 = 27.692°
```

Place pin 0 at the top, walk 27.692° around
the circle for each subsequent pin, and the 13th pin
lands exactly where you started. The radial forces from all
13 pins acting symmetrically on the hub **sum to zero**
— same as any regular N-gon arrangement; primality doesn't break force
balance.

What primality breaks is the **opposing-pair relation**. A pin at angle
A on a 13-pin door has no other pin at angle A + 180°.
The closest two pins land off by half an angle step
(13.846°).

pin 0 highlighted; the would-be mirror partner falls between two real pins

The dashed marker is where pin 0's mirror twin *would* have to sit on a
12-pin door. On 13 pins it falls between two
real pins, off by half an angle step. The pin itself isn't broken — it
just has nothing to be paired with.

side-by-side: 12 pins resolve into 6 chord pairs; 13 pins have no chord that lands on another pin

## Where it actually hurts

Whether you care depends on the design you wanted to build:

| Design trick | Works for 12? | Works for 13? |
|---|---:|---:|
| Central pinion + N independent racks | ✓ | **✓** |
| Cam plate with N follower slots | ✓ | **✓** |
| Independent levers, one cam profile per pin | ✓ | **✓** |
| One shared rack driving two opposite pins | ✓ | ✗ |
| Mirror sub-assembly fixtured & cast N/2 times | ✓ | ✗ |
| Multi-stage lock — wave of N/2, then N/2 | ✓ | ✗ |
| Multi-stage lock — wave of N/3, three times | ✓ | ✗ |

The first three rows are the "no-tricks" path. They work for any N.
That's the path that lets a 13-pin door function.

The last four are the optimizations a composite count buys you — shared
parts, mirrored fixtures, sub-symmetric actuation. 13
locks you out of all of them.

## Divisors at a glance

```
divisors(12)  = 1, 2, 3, 4, 6, 12
divisors(13)  = 1, 13
divisors(24)  = 1, 2, 3, 4, 6, 8, 12, 24
```

Composite numbers give mechanical designers many ways to divide, mirror,
and repeat a design. Prime numbers give two: 1, and the number itself.

That's not a bug in primes — it's the *definition* of prime. It just
means a 13-pin design either uses 13
identical, individually-fitted actuators, or one custom geometry.
There's no elegant middle ground.

## Picking 13 on purpose

If you want the elegance, pick 12 or 24.
You'll have more design options.

If you want a conversation piece — a door that genuinely doesn't admit
mirror simplification, where every part is unique by necessity — pick
13 and lean into it.

What you don't have to choose between is "works" and "doesn't work."
Both work. The honest framing is:

> Prime pin counts aren't mechanically broken. They just don't share.

---

*Generated by `src/vault/thirteen_pin.py`. Pin counts come from
[`src/vault/vault.py`](../../src/vault/vault.py).*

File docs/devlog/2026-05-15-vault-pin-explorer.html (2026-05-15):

DocDevlog

Projectpycon2026

Authorjmcpheron

VenuePyCon US 2026

§ Entry · 2026-05-15

# Vault pin explorer — drag the slider

An interactive slider for vault-door pin counts, plus an animated hero on the vault study's landing page. Companion to the Python parametric study; inspired by Adam Savage's mini vault build.

2026-05-15 · jmcpheron

## What changed

The vault door mechanism study just got a front door. Two new things landed on the same branch:

- An animated hero SVG at the top of docs/vault/README.md — twelve pins extending and retracting in sync with a cam wheel that rotates ±10°. Five-second loop, inline SMIL, no JavaScript. GitHub renders it in the markdown view directly.
- A live interactive pin-count explorer at docs/vault/pin-explorer.html (https://jmcpheron.github.io/pycon2026/vault/pin-explorer.html) — drag a slider from 3 to 30, the SVG layout snaps, and a side panel updates the angle step, the divisor list, the opposing-pair count, and the rack-body thickness budget at the canonical 12 mm central pinion.

The explorer is a single hand-written HTML file. Vanilla JS, no dependencies, ~30 lines of geometry helpers ported from src/vault/geometry.py. The shared stylesheet (cream paper, gold accents, Fraunces serif) gets it for free — it links the same docs/assets/styles.css the rest of the project uses.

// src/vault/geometry.py, ported to JS — kept tiny on purpose
function angleStep(n) { return 360 / n; }
function pinAngles(n, start = -90) {
  const step = angleStep(n);
  const out = [];
  for (let i = 0; i < n; i++) out.push(start + i * step);
  return out;
}
function rackBudgetMm(n) {
  return (2 * Math.PI * PINION_RADIUS_MM / n) - CLEARANCE_MM;
}

Slide to 12: 30° step, six clean opposing-pair chords appear through the hub, rack budget reads 5.98 mm. Slide to 13: chords disappear, pin 0 turns red, a dashed phantom marker shows where its missing partner would have sat, rack budget drops to 5.50 mm. Slide to 24: the racks pinch to 2.84 mm — the visual version of the rack-thinning note I wrote up earlier.

## Where this came from

The whole vault study started when I was watching Adam Savage's mini vault-door build and got fixated on one detail. Each pin had a section of straight gear teeth cut into it, and the back of that section — the spine, opposite the teeth — was machined surprisingly thin. More material removed than weight savings would justify.

When the parts went together inside the door it clicked. A single central pinion drives all N racks at once. The racks have to share the perimeter of that one pinion. Each rack's tangential thickness is bounded by

t  ≤  (2π · r_pinion / N)  −  clearance

So the spine of every rack gets machined down to whatever slice it gets. Bigger N → thinner slice. Adam wasn't choosing the shape; the pin count was choosing it for him. That observation kept me up an evening and turned into a Python parametric study about the symmetry, gearing, and packaging trade-offs of radial pin mechanisms.

The explorer is the version of that idea you can poke at without cloning a repo.

## For the Tested community

I'm sharing this with the Tested (https://www.tested.com/) Maker Share community. It's a fan-made educational study inspired by Adam's mini-vault build — not affiliated with Tested, not a reproduction of any specific design, just a love-letter to the geometry. If you got here from there: hi. Fork it, riff on it, change the numbers in src/vault/vault.py, run uv run vault build, and every page re-derives with your inputs.

What's next, maybe:

- Add a cam rotation slider so you can sweep through 0–45° and see the arc-travel readout update live.
- Add an animated comparison: 12 vs. 13 vs. 24 side-by-side, all running on the same loop.
- Wire the explorer to a query string so links can deep-link to a specific pin count.
- Onshape model — phase 1 (static 12-pin layout) is sketched in onshape-workflow.md; haven't touched the parametric CAD yet.

github.com/jmcpheron/pycon2026 DEVLOG · 2026-05-15 MIT

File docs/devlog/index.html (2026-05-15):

DocDevlog

Projectpycon2026

Authorjmcpheron

VenuePyCon US 2026

§ R&D journal

# Devlog

Working notes on a 3D-printed gear-ratio business card, an offshoot vault-door geometry study, and the Python tooling that generates both. Newest first.

2026 · 05 · 15

## Vault pin explorer — drag the slider

An interactive HTML page for the vault-door study — drag a slider 3 to 30 and the layout snaps, with live readouts for angle step, divisors, and rack-body budget. Plus an animated SVG hero on the study landing page.

experiment decision

github.com/jmcpheron/pycon2026 DEVLOG · INDEX MIT

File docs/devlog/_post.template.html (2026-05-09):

` / `` markers. -->

DocDevlog

Projectpycon2026

Authorjmcpheron

VenuePyCon US 2026

§ Entry · {{DATE_HUMAN}}

# {{TITLE}}

{{LEDE}}

{{DATE_HUMAN}} · jmcpheron

## What changed

Replace this paragraph with the body of the post.

def example():
    return "hello"

$ uv run badgeforge build
# comment

Description of image

FIG 01 A short caption.

Parameter | Value | Notes
Footprint | 88.9 × 50.8 mm | US-standard
Thickness | 1.6 mm | 4 layers @ 0.4 mm

Replace this aside with the user's reasoning. Suggested beats:

- What prompted the change.
- What the trade-offs are.
- What this enables next.

github.com/jmcpheron/pycon2026 DEVLOG · {{DATE_ISO}} MIT

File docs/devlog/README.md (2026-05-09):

# Devlog

The rendered devlog lives at **<https://jmcpheron.github.io/pycon2026/devlog/>** — that's the canonical place to read it.

Posts are HTML, not Markdown. To browse the source: open [`index.html`](index.html) or any `YYYY-MM-DD-*.html` file directly.

The shared stylesheet is [`devlog.css`](devlog.css). The canonical scaffold for new posts is [`_post.template.html`](_post.template.html), maintained by the project-local `/devlog` Claude Code skill.

## Posting from the Claude Code mobile app

This repo ships a project-local `/devlog` skill. From the Claude Code mobile app: open a session in this repo, attach photos, type `/devlog <one-line title or note>`. The skill creates or appends to today's HTML post, drops assets in `assets/<post-slug>/`, prepends a card to `index.html`, and stages everything for review. Nothing auto-pushes.

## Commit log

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2026-05-07 pivot Phase 3: Raspberry Pi demo arc (README only)
    Replace Phase 2 status with the four-stage demo arc: Bolt -> SCADvil
    -> Pi 5 wall mount -> retro Pi 5 case. Engine (agent loop) unchanged;
    only the artifact target shifts. Geometry, prompts, and devlog post
    land in follow-up commits on this branch.
    TODO markers left for the README pitch line and the "Why Raspberry Pi"
    framing so the author can fill those in their own voice.
2026-05-07 scadvil: first generation — prompt + render + post
    iter-0 from scadia, score 8/10, controller stopped early. Source has
    three CSG bugs the vision critic couldn't see (peg-not-hole, floating
    text, faux-tapered horn) — documented in the new devlog post as
    talk-material about the limits of vision-only sensors. Shipping the
    .scad verbatim; CI auto-builds the STL.
    [scadvil.scad]
2026-05-07 multi-critic experiment: poll six OpenRouter models on SCADvil iter-0
    Adds scripts/multi_critic.py — sends one render + SCAD source + the
    original prompt to multiple OpenRouter multimodal models, reuses
    scadia's CRITIQUE_TOOL schema and SYSTEM_CRITIQUE so it's apples-to-
    apples against the live agent's critic. Saves per-model JSON +
    comparison.md under output/experiments/ (gitignored).
    Headline finding: Gemma 4 31B IT (the smallest model in the lineup)
    named the peg-vs-hole bug exactly and gave a code-level fix. Claude
    Haiku 4.5 via OpenRouter graded 7/10 with 3 blockers; the same model
    in the live agent run earlier today gave 8/10 with 0 blockers. Same
    critic isn't even self-consistent.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
2026-05-07 pi5-wall-mount: stage 2 ships iter-1; client.py strips ``` fences
    Three iterations ran (4 → 5 → 4); ship iter-1 (highest score, most
    credible Pi-mount visual). Critic caught real CSG bugs this time —
    the SCADvil's peg-not-hole class of bug didn't recur, the agent's
    top-level difference() structure looks correct. Persistent bugs:
    standoff/plate z-overlap, keyhole slots are rectangular notches not
    real keyholes. Documented in the devlog post with all three iteration
    renders inline.
    Also patches src/scadia/client.py to drop surrounding markdown ```
    fences from generate_scad/refine_scad output. Caught us once on the
    first attempt at this run — the agent's refine pass returned valid
    SCAD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
    [pi5-wall-mount.scad]
2026-05-07 pi5-retro-case: stage 3 ships iter-1, critic missed three CSG bugs
    Two iterations, score 6 → 9, controller stopped on critic
    done=True. The critic was wrong: the SCAD source has three bugs
    visible only in code, not pixels:
    1. PYCON 2026 text is a horizontal slab, not wall-face text —
    missing rotate before linear_extrude.
    2. M2.5 holes drill only z=-0.5 to 6.5; standoff top is at z=9 —
    top 2.5 mm of every standoff is solid, screws hit a wall.
    3. Decorative ribs are three small cubes per wall at the same Z,
    not the requested horizontal raised lines. Aesthetic intent
    lost.
    Same blindspot pattern as the SCADvil: vision sees shape, not
    source. Pi mount was the ex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
    [pi5-retro-case.scad]
2026-05-07 multi-gen 1/4: scripts/multi_generator.py + claude-haiku baseline
    Adds scripts/multi_generator.py — single-shot generation per OpenRouter
    model. Reuses SYSTEM_GENERATE, _strip_fence, scad_to_png — no new deps,
    parallel to scripts/multi_critic.py. ~120 lines.
    First model: anthropic/claude-haiku-4.5, the same model scadia uses
    internally. Generated a clean anvil silhouette with a real tapered horn
    (cylinder r1/r2 trick, no hull) in 3.8s. Reproduced the retro case's
    text-orientation bug — letters laid out in XY plane, linear_extrude'd
    upward, so the emboss is a horizontal slab on top of the body rather
    than wall-face text. Third consecutive Claude run with this exact bug.
    Devlog post is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
2026-05-07 multi-gen 2/4: gemini-2.5-flash — text rotated correctly but CSG buried
    Gemini used rotate([90, 0, 90]) before linear_extrude — first generator
    in this branch's runs to get text-on-vertical-wall orientation right.
    But its difference() is buried beside a duplicate of anvil_body() in
    the union, so the unmodified body overshadows the cut and the text
    emboss disappears anyway.
    Different bug class than Claude (orientation vs structure). Same visible
    outcome (no text on the render). If you only looked at renders you'd
    miss the distinction.
2026-05-07 multi-gen 3/4: gpt-5-mini — reasoning model, parser-error SCAD
    Added --max-tokens flag to the script. gpt-5-mini's first attempt with
    the default 2048 tokens returned finish_reason=length and content=null —
    all tokens went to internal reasoning. Re-ran with --max-tokens 8192,
    took 121s of generation. Output had two versions of the text emboss:
    one broken module that tries to assign linear_extrude() to a variable
    (invalid in OpenSCAD), and one correct inline version. The model knew
    the assignment was wrong (commented on it) and wrote a working
    alternative — but shipped both. Parser fails on the broken one.
    Third bug class in three models: wrong code (Claude), structurally
    cancelled cod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
2026-05-07 multi-gen 4/4: gemma-4-31b-it — closest to right, still invisible text
    Smallest, cheapest model in the lineup. Only model to honor the user
    prompt's $fn=24 (others used $fn=60 from SYSTEM_GENERATE). Cleanest
    horn of the four — actual smooth taper. Used rotate before
    linear_extrude AND a top-level difference — the structurally correct
    pattern.
    Failed at text positioning: text translated to y=-0.1 then extruded
    1mm in -Y. Body front face at y=0. Text slab sits 0.1mm outside the
    wall, extends another 1mm further out, never overlaps body material.
    Difference runs on disjoint geometry.
    Closes the four-model arc: 0/4 produced visible wall-face text from
    the no-hint prompt. Three rendered,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
2026-05-09 feat(badgeforge): parametric PyCon 2026 badge CLI + CI integration
    Pivot the project narrative from the scadia AI design loop to shipping a
    3D-printed PyCon 2026 badge. The AI-loop code stays in place; only the
    README framing changes.
    - New src/badgeforge package: Click CLI + thin OpenSCAD subprocess wrapper.
    uv run badgeforge build --name "..." --github "..." renders models/card.stl
    via openscad -D injection.
    - Parameterize models/card.scad on name/github; lock variant 2 layout from
    the 2026-05-06 mockups post; inline the gh_mark placeholder so the file
    renders standalone with no missing SVG.
    - Update .github/workflows/build-stl.yml to install Python+uv and call
    badgeforge for th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
    [card.scad]
2026-05-09 feat(devlog): HTML scaffold with html-effectiveness palette
    Adopt HTML as the medium for the developer journal, taking the
    warm-editorial palette and patterns from ThariqS/html-effectiveness:
    ivory ground, slate text, clay/olive/rust accents, Georgia + system-sans
    + monospace stack, 860px column, post-card grid.
    - docs/devlog/devlog.css — single shared stylesheet, all design tokens
    declared as CSS variables at the top.
    - docs/devlog/index.html — replaces the markdown bullet list with a card
    grid (newest first), tag chips by post type (pivot / decision-record /
    experiment / print-log).
    - docs/devlog/_post.template.html — canonical scaffold the /devlog skill
    will reference; plac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
2026-05-09 docs(README): 3-image story — OpenSCAD render / GitHub STL viewer / printed photo
    Replace the single hero image at the top of the README with a 3-column
    table that walks the same source through three rendering surfaces:
    1. OpenSCAD render — the existing badge-hero.png, generated by
    "uv run badgeforge render" in CI.
    2. GitHub STL viewer — a new screenshot (docs/assets/badge-stl-github.png)
    captured from the live https://github.com/jmcpheron/pycon2026/blob/main/models/card.stl
    page in Surface Angle view mode. The image is itself a link back to
    that page so a click opens GitHub's interactive viewer.
    3. Printed object — placeholder SVG until jmcpheron drops a r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
2026-05-09 feat(card): replace single PiP gear with dual-gear dial + hex GH fidget
    Move the GitHub identifier from a small embossed [gh] mark into a real
    mechanical fidget in the upper-left:
    - dial: 16-tooth spur gear, 18 mm OD, the knob you spin
    - hex: 6-sided "gear" with GH engraved on top, point-to-point 16 mm
    - both print-in-place in one peanut-shaped pocket sharing pocket
    geometry, each on its own 2.4 mm post
    Engagement geometry: dial body radius is 7 mm, tooth tips reach 9.3 mm;
    hex point radius is 8 mm, hex flat radius is 6.93 mm. With a center
    distance of 15.5 mm, a tooth tip extends ~0.7 mm past the hex flat — a
    visible mesh, and dial spin will step the hex (occasional bind by
    d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
    [card.scad]
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2026-05-09 ci: add concurrency guard to auto-commit workflows
    Cancel any in-flight build-stl/build-step run when a new push arrives
    on the same branch. Prevents overlapping CI runs from racing each other
    to auto-commit binary artifacts (which had been kicking back local
    pushes with non-fast-forward errors).
2026-05-09 feat(explainers): Python-driven engineering writeups for the gear card
    Four deterministic Python programs that emit illustrated markdown writeups
    of the engineering decisions behind the compound reduction-gear card —
    gear ratios, level stacking, terminology, and 3D-printing considerations.
    All numbers come from one canonical card.py so editing it re-renders every
    section consistently. SVG output is deterministic across runs (matplotlib
    hashsalt + drawsvg + no timestamps), so the auto-commit guard won't churn.
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2026-05-13 ci: rebase-and-retry in all auto-commit workflows
    When multiple build-*.yml workflows fire on one human push, they each
    regenerate their own artifacts and try to git push. Whichever runs
    fastest wins; the others get rejected because origin moved.
    The existing `concurrency:` guard only prevents a workflow from racing
    itself, not racing peer workflows.
    Replace the bare `git push` with a 5-attempt loop that fetches and
    rebases onto origin/main between retries. Each auto-commit workflow
    writes to a disjoint path set (badge STL vs pounce-a-pult STEP
    artifacts vs card artifacts vs explainer SVGs), so the rebase is
    always conflict-free in practice. The rebase --abort path bails out
    loudly if the a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
2026-05-13 style(pages): make the landing page mobile-friendly
    The 4-button hero-actions row had display:flex with no wrap, forcing
    horizontal page overflow on phones. That overflow made everything
    else look clipped — the h1, tagline, and lede appeared to bleed off
    the right edge even though they fit on their own.
    - hero-actions: flex-wrap: wrap so the buttons stack on narrow widths
    - btn: white-space: nowrap so button labels don't break mid-word
    - hero h1: lower clamp minimum 4.5rem → 2.75rem so "pycon2026"
    scales down on small phones
    - tagline: lower clamp minimum 1.5rem → 1.25rem
    - tagline / lede / h1: overflow-wrap: break-word as a safety net
    - html, body: overflow-x: hidden as a defensive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
2026-05-13 docs(pages): overhaul the landing page to mirror the README
    The pages site had a "How it builds" button that didn't say what it
    linked to, a "Devlog" button pointing at a directory of old badge /
    scadia brainstorming, and a section structure that diverged from
    the README. Refactors the page so the information hierarchy matches
    the README — which is now the canonical project description.
    Pages changes:
    - Hero: drop the "Devlog" and "How it builds" buttons. Replace with
    Repository + a clean "How it works" anchor.
    - New parts-row section under the hero — three plate-style figures
    (card half, standard compound gear, tall-hub variant) with the
    same captions as the README. Stacks on mob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
2026-05-13 docs(pages): rework landing page for a Hacker News audience
    Reframes the Pages site from a conference-handout vibe into a
    landing page someone arriving from an HN post can read top-to-
    bottom. The card itself, the math, and the Python pipeline are
    still the spine; what changes is the framing around them and the
    substance below.
    Page flow now:
    Hero — lede carries the "going to PyCon, here's why I'm
    posting" framing inline. Onshape link is in both
    the lede and the button row.
    Parts row — unchanged
    §01 How it works — dropquote makes the 256:1 math unambiguous
    (5 gears, 4 meshes, 4:1 each, 4⁴ = 256:1) and
    em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
2026-05-14 docs: clarify the 256:1 math so '5 stages × 4:1' can't be misread
    The legacy phrasing "Five stages of 4:1 → 256:1" is mathematically
    correct only if you read "stage" as "mesh between consecutive gears"
    — but a careful reader (e.g. someone arriving from a Hacker News
    post) will compute 5 × 4:1 = 4^5 = 1,024:1 and conclude the math
    is wrong. The card actually has 5 compound gears in a chain with
    4 meshes between them, each 4:1, → 4^4 = 256:1.
    This commit removes the word "stage" from every reader-facing
    math claim and replaces it with the unambiguous "gears + meshes"
    framing. The Python constant card.N_STAGES keeps its name (renaming
    would propagate through ratios.py, stacking.py, dec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
2026-05-14 ci: drop Python 3.13 from test matrix
    cadquery-ocp==7.8.1.1.post1 (pinned to avoid OCCT STL float-format
    drift in the auto-committed step-demo/*.stl) depends on vtk==9.3.1,
    which only ships cp311 and cp312 wheels. uv sync --all-extras fails
    on 3.13 with "no source distribution or wheel for the current platform".
    Drop 3.13 from the matrix until we can bump cadquery-ocp (>=7.9.3.1
    brings vtk==9.5.2, which has cp313 wheels).
2026-05-14 docs: fix card-half pocket count (4 → 5) and shape in README
    The "Card half" description claimed four square gear pockets, but the
    STEP-derived render (docs/assets/card/parts/Part_1.png) and the manifest
    (5 spur gears at 15 mm pitch) show five rounded pockets. The exploded-GIF
    alt text on line 13 already said "five shaft holes spaced 15 mm apart",
    so the table caption was the lone inconsistency.
    https://claude.ai/code/session_01DXQ545tr6jprgRoTuGNgUv
2026-05-14 feat(explainers): animated gear-chain hero SVG
    Add a second README hero showing the 5-gear compound chain spinning at
    its physically correct relative speeds — gear N rotates at 1/4^N of the
    input, with direction reversal at each pinion-to-disc mesh.
    Each gear is wrapped in a <g> with a SMIL <animateTransform> rotating
    about its post. Durations scale by RATIO_PER_STAGE: 2, 8, 32, 128, 512
    seconds per revolution, so the output gear (1/256× the input) creeps at
    ~0.7°/s while the input visibly turns once every two seconds. Per-mesh
    "4:1" callouts and INPUT/OUTPUT bookends label the chain.
    Reuses the existing compound_gear() primitive — refactored to share its
    shape emission with a new an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
2026-05-15 fix: update README to clarify gear pocket count and correct shape description
    [anthropic_claude-haiku-4.5.scad, cube.scad, cube.stl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]
2026-05-15 feat: add Vault Door Mechanism Study (src/vault/, docs/vault/)
    A parallel parametric study to the gear-ratio card. Same single-source-of-
    truth + auto-regen pattern as src/explainers/: one file (vault.py) drives
    every diagram and markdown page; `uv run vault build` writes docs/vault/.
    - src/vault/ package mirrors src/explainers/ conventions (SLUG/build()
    topic modules, Click CLI, vault.py canonical parameters). Reuses the
    explainers palette and base SVG primitives via cross-package import.
    - Five topic pages: symmetry, thirteen-pin-problem, pin-counts,
    motion-and-travel, onshape-workflow — plus a generated README index.
    - Nine SVGs: 12/24-pin layouts, opposing-pair chords, 12-vs-13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
2026-05-15 feat(vault): add rack-and-pinion packing-constraint note + diagram
    Adds the physical mechanical explanation for why each rack body gets
    machined so thin in miniature rack-and-pinion vault builds. The N racks
    must share the perimeter of the central pinion's pitch circle, so each
    rack's tangential thickness is bounded by 2π·r_pinion/N − clearance.
    - vault.py gains CENTRAL_PINION_RADIUS_MM, RACK_BUDGET_PER_PIN_MM, and
    MAX_RACK_TANGENTIAL_THICKNESS_MM as canonical constants.
    - svg_draw.py gains draw_rack_packing(), a three-panel side-by-side
    (N=6/12/24) showing the same pinion with rack bodies shrinking as N
    grows.
    - pin_counts.md gets a new "A note from watching Adam Savage's mini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
2026-05-15 docs(devlog): first entry — vault pin explorer shipped
    Adds the first devlog post (2026-05-15-vault-pin-explorer.html) and
    creates docs/devlog/index.html (one post card). Companion to the Phase 2
    vault overhaul: animated hero on docs/vault/README.md plus the new
    interactive docs/vault/pin-explorer.html. Three short sections — what
    changed, the rack-thinning observation that started the study, and a
    maker-share friendly note for the Tested community.
2026-05-15 feat(vault): animated 12 vs 13 vs 24 comparison hero on 13-pin page
    Three doors side-by-side, all locking and unlocking on the same
    5-second SMIL loop. The middle (13-pin) panel highlights pin 0 in red
    with a dashed phantom marker showing where its missing partner would
    sit. Watching all three cycle simultaneously is the visual punchline:
    12 and 24 cleanly mirror across the diameter on every cycle, 13
    demonstrably never does.
    - New draw_animated_comparison() in src/vault/svg_draw.py — 3 cam
    rotations + 49 pin translations (12+13+24) all on the same keyTimes,
    same SMIL pattern as draw_animated_hero. Renders inline in GitHub
    markdown via the camo proxy.
    - Wired into src/vault/thirteen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
2026-05-15 feat(vault): replace SVG hero with build123d-rendered mechanism GIF
    The README hero used to be a flat drawsvg/SMIL diagram of a single
    central pinion driving 12 radial racks, with rack teeth drawn on the
    wrong face of each rack (the short inner end instead of the long
    tangential face the README itself describes). Replace it with a
    parametric build123d + bd_warehouse model of Adam Savage's actual
    mechanism — a central ring gear driving 12 spur gears on a 72 mm BCD,
    each spur driving one rack-and-pin via rack-and-pinion — rendered
    frame-by-frame through OpenSCAD and PIL-stitched into vault-hero.gif.
    The new module sits behind a dedicated `vault build-mechanism`
    subcommand and its own CI w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
2026-05-15 docs: credit upstream open-source projects we depend on
    Add ACKNOWLEDGMENTS.md with a per-project license table covering every
    Python library this repo pulls in (build123d, bd_warehouse, cadquery-ocp,
    cascadio, trimesh, Pillow, drawsvg, matplotlib, click) plus the external
    tools (OpenSCAD, Xvfb, uv). Link to it from the main README's License
    section and from the auto-generated docs/vault/README.md so the new
    mechanism animation specifically credits bd_warehouse and build123d —
    the two libraries that draw the gear teeth — and notes their Apache-2.0
    licenses inline. Also adds a short third-party-libs block to the
    mechanism module's docstring so the credit travels with the code.
2026-05-15 feat(cardlab): add `cardlab spin` — animated chain via build123d + bd_warehouse
    Apply the same parametric pipeline the vault mechanism uses
    (src/vault/mechanism.py) to the gear card. New src/cardlab/spin.py
    builds the five compound gears with bd_warehouse.gear.SpurGear (40
    driven + 10 pinion at module 0.6, fused via build123d boolean union),
    drops a card-shaped plate beneath, and renders one frame per cam angle
    through OpenSCAD before PIL stitches them into spin.gif. Each gear
    spins at 1 / RATIO_PER_STAGE the rate of the previous with alternating
    direction, so the 256:1 reduction reads visually: input is a brass
    blur, output barely twitches.
    Wired into the existing build-card.yml after `c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
2026-05-16 fix(vault): make racks coplanar with spurs + mill the spine
    The hero GIF was missing the 12 racks visually — they were defined in
    the SCAD shim but rendered 6.1 mm above the spurs (and hidden by the
    ring gear's silhouette in iso). Even if visible, the geometry wasn't
    a real rack-and-pinion mesh: rack centrelines coincided with the spur
    radial axes, so the spur's pitch circle wasn't tangent to any face of
    the rack.
    Three changes to src/vault/mechanism.py:
    1. **Coplanar Z**: drop _RACK_Z (rack bottom = 7.2 mm) and replace
    with _RACK_Z_CENTER = _SPUR_Z + _SPUR_THICKNESS/2 = 5.1 mm — same
    z as the spur centre. The 8 mm rack stock now overlaps the 4 mm
    spur thickness at every z, wi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
2026-05-16 feat(explode): apply spin-GIF rainbow palette to exploded.gif too
    Move the per-stage colors (STAGE_COLORS, AXLE_COLOR) into a new shared
    cardlab.palette module so both pipelines paint with the same brush.
    exploded.gif now sorts gear parts by X centroid and assigns the
    crimson→violet cascade, so both GIFs read as the same five-stage chain.
    Card halves stay uncolored — the default Cornfield yellow keeps reading
    as the printed card body.
    Adds a pure-logic test for _assign_part_colors that doesn't need any of
    the heavy toolchain (cascadio / build123d / openscad).
2026-05-16 README: add photo of the actual printed card
    After the two animated GIFs (exploded.gif, spin.gif), show a real-world
    shot — four pieces laid out: the bottom half with the gear chain nested
    in, the top half on its own, the top flipped so gears show through the
    windows, and the closed card with the front-face logo.
    Lives at docs/assets/card/photos/assembled.jpg — outside the set of
    paths build-card.yml stages, so the auto-commit workflow won't touch it.
    https://claude.ai/code/session_01T9oEa2qkTPUCuZ4nayWYrD
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2026-05-17 Add vault sandbox: OpenSCAD playground + Onshape comparison docs
    Local iteration sandbox for the vault-door build under docs/vault/sandbox/:
    parametric three-stage tapered door body, full assembly with imported gear
    STLs and animated cam_progress slider, and a self-contained parametric
    ring-gear demo (no external libraries) that exports to STL.
    Distills the Adam Savage video parts 2-5 into specs.md with source tags
    and a discrepancies table, fixes the onshape-notes table (the ring is
    topologically a sun gear, not an internal annulus), and adds an
    onshape-vs-openscad comparison doc framed around code-trackable CAD
    workflows.
    [assembly.scad, door.scad, ring_gear.scad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]
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2026-05-19 Add parametric rack.scad meshing with the 24T pinion
    OpenSCAD source-of-truth for the gear rack on the vault project's 12
    locking pins. Module 0.5, 20 deg pressure angle, face width 6mm to
    match the satellite pinion's Onshape Depth setting. Tooth profile is
    mathematically exact (a rack's involute is straight flanks at the
    pressure angle), not an approximation.
    Includes an optional mesh-preview pinion that uses ring_gear.scad's
    gear() module so the rack and the pinion can't drift apart. STL
    exports cleanly via openscad -o.
    [rack.scad, rack.stl]
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
